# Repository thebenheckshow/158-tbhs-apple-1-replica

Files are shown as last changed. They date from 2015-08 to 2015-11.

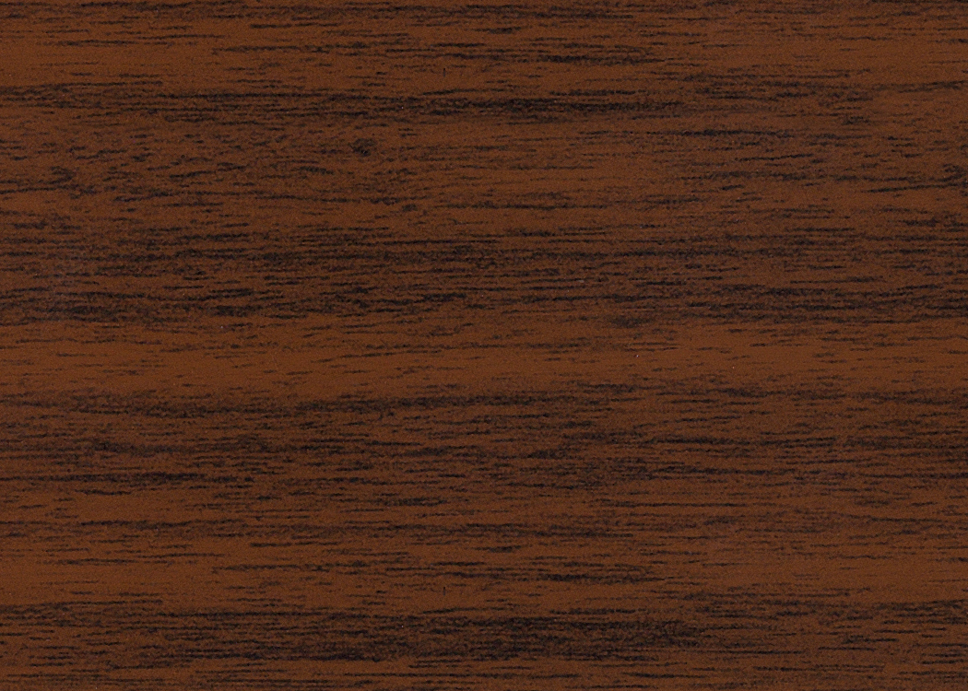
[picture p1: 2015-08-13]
enclosure design/ai/woodgrain.jpg

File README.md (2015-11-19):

Ben decides to take on another retro 8-bit computer project and builds an Apple 1 from scratch. He wires the CPU, ROM, and RAM to a PCB and adds some logic gates for memory addressing. With this basic 6502 computer complete, he uses an oscilloscope to take a look at what the CPU is doing. The digital data shows that the 6502 is functional and Ben can move on to the next step.

Ben Heck's Apple 1 Replica Part 1: http://www.element14.com/community/docs/DOC-70662/l/episode-158-ben-hecks-apple-1-replica-part-1-episode

Ben Heck's Apple 1 Replica Part 2: http://www.element14.com/community/docs/DOC-70977/l/episode-159-ben-hecks-apple-1-replica-part-2-episode

Ben Heck's Apple 1 Replica Part 3: http://www.element14.com/community/docs/DOC-71142/l/episode-160-ben-hecks-apple-1-replica-part-3-episode

Learn more about DREAMBOARD at http://element14.com/dreamboard

Join the community at: http://www.element14.com/tbhs

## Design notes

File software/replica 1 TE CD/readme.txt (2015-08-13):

This CD contains drivers, manuals and software for the replica 1TE 8 bit single board computer. See Briel Computers website for more information at:

http://www.brielcomputers.com

I hope you enjoy your replica 1 as much as I enjoyed designing it.

Vince Briel
Briel Computers

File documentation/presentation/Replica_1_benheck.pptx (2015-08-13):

## Replica apple 1 build the ben heck show

A Journey Back to an 8-bit Era

## About the ben heck show

- Weekly show on element14.com community and YouTube
- Focus on technology, problem solving and real-world assembly
- Projects designed to engage community
- 175 episodes since debut in 2010

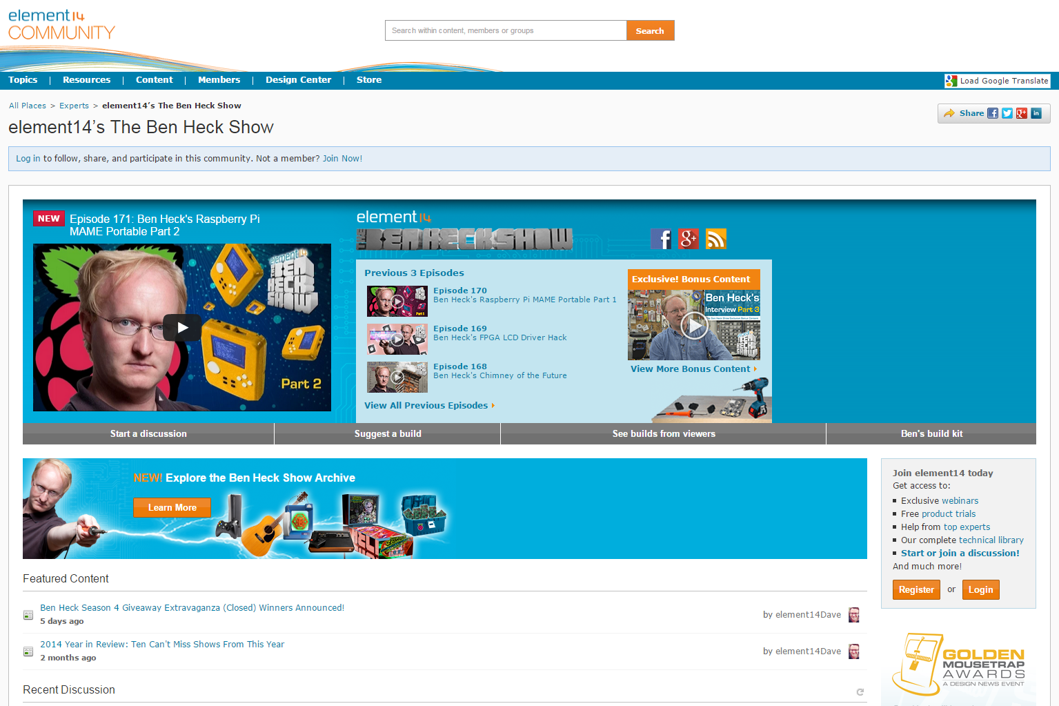
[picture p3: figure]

## Project origins

- Personal fan of classic 8-bit computers
- Recent success with classic Sinclair Spectrum
- Fun opportunity to explore the roots of modern computing

## Project overview

- Find schematics for original Apple 1
- Locate ROM images and map correctly to modern EPROM
- Find as many modern, compatible components as possible
- Hand-wire Apple 1 circuitry as a 6502 single-board module
- Hand-wire microcontroller alternative to Apple 1 video circuit
- Create custom keyboard and scan with the microcontroller
- Design project enclosure based off the size of the LCD
- CNC, laser cut and 3D print custom case, assembly and wire

## Apple 1 overview

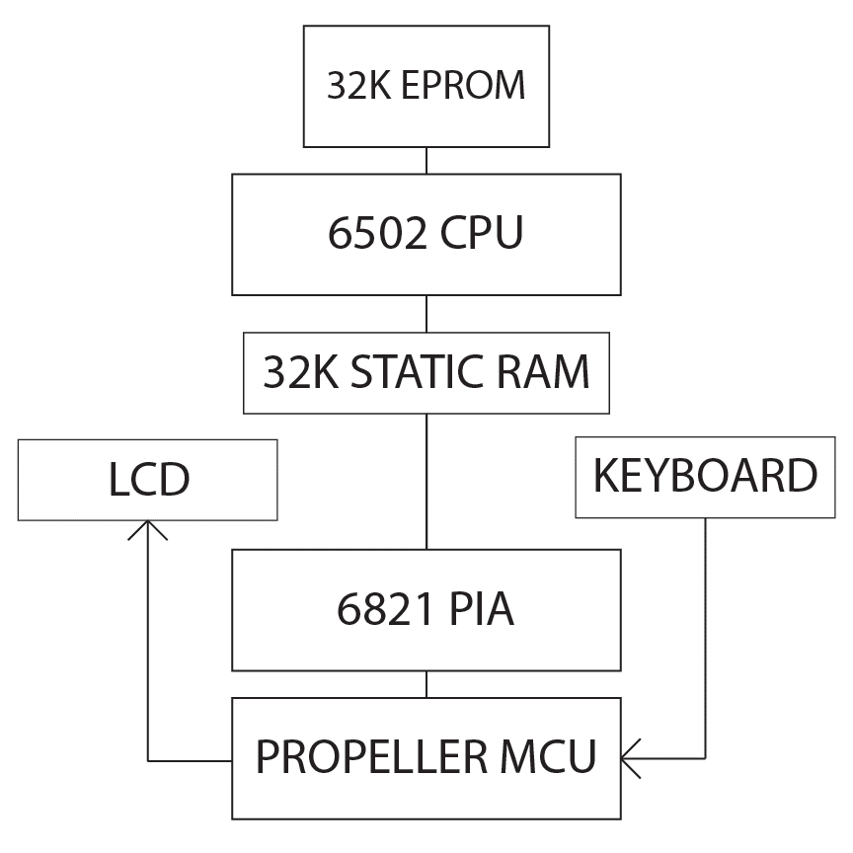
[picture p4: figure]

- Part 1: 6502 system
- Part 2: PIA and Microcontroller for I/O
- Original parts:
- 6502, PIA
- Modern parts:
- EPROM, RAM, MCU, glue logic

## Memory map

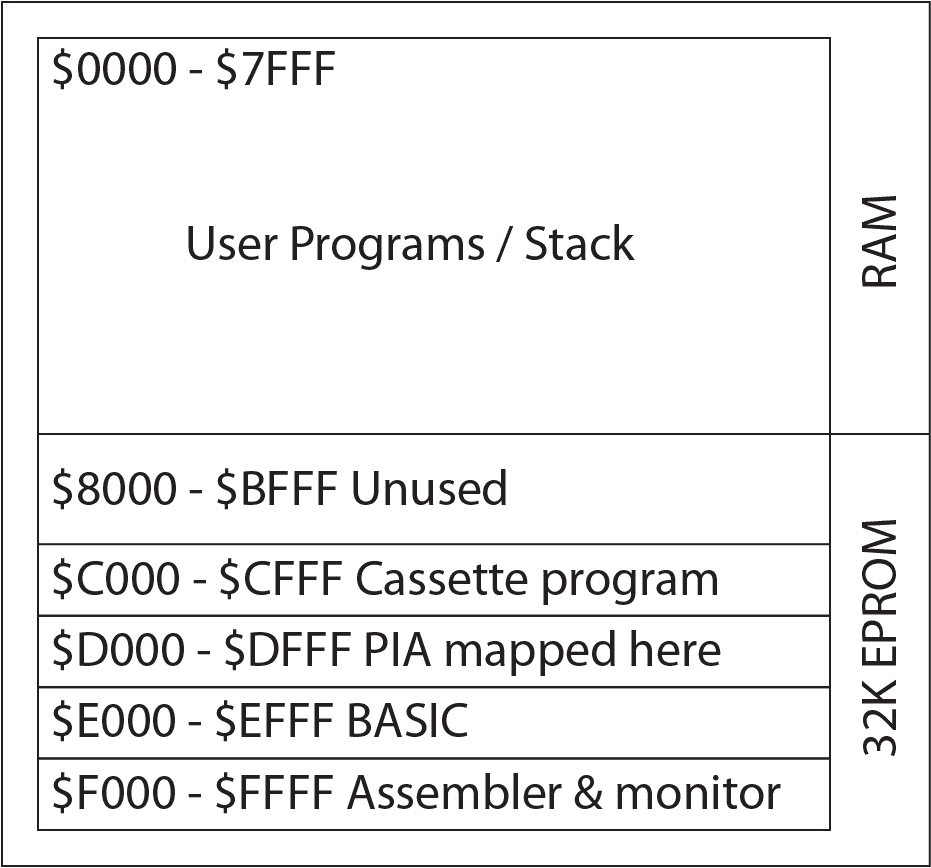
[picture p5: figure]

- Original Apple had RAM at bottom and top of memory (below WOZ monitor)
- Replicas place RAM at bottom of memory, EPROM programs at top
- Cassette, BASIC and monitor programs arranged via HEX editor and burned to EPROM
- Mapping done with a few logic circuits

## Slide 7

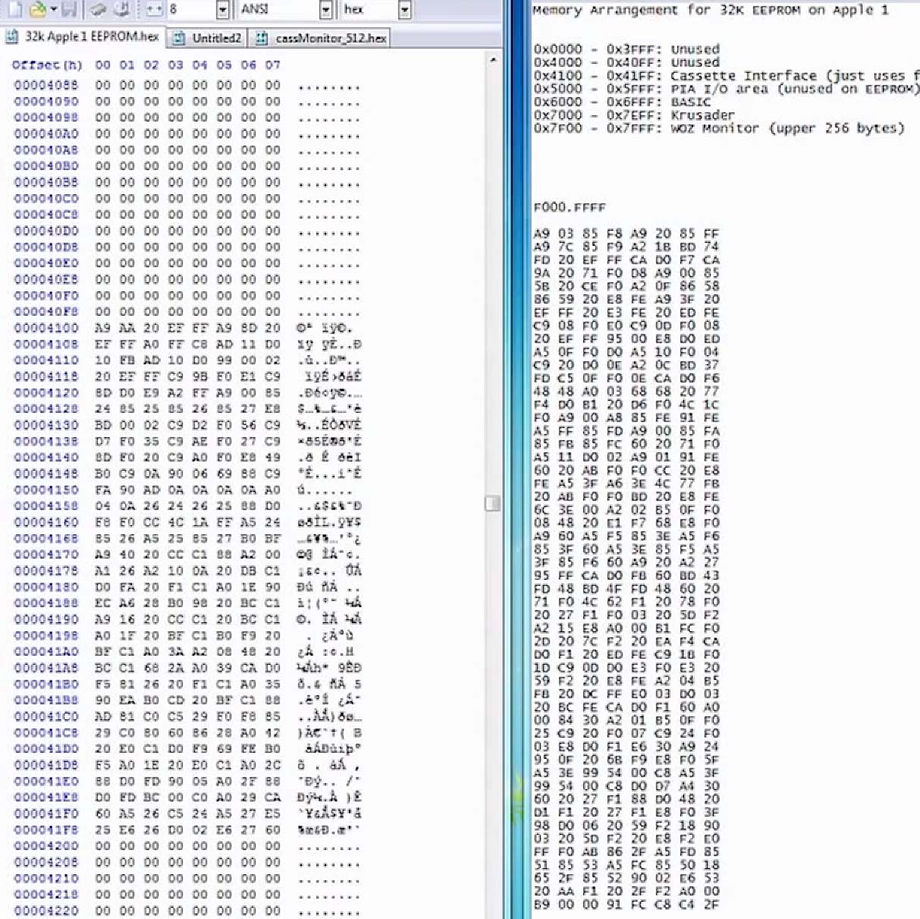
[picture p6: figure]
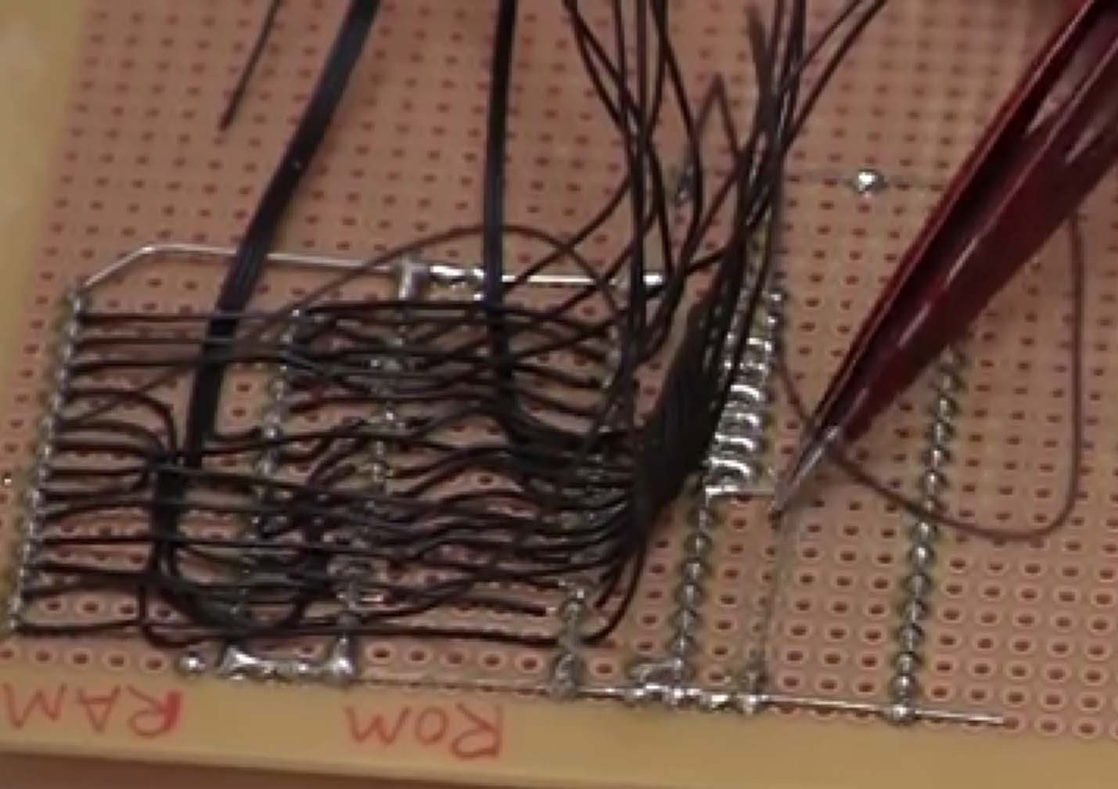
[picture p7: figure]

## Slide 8

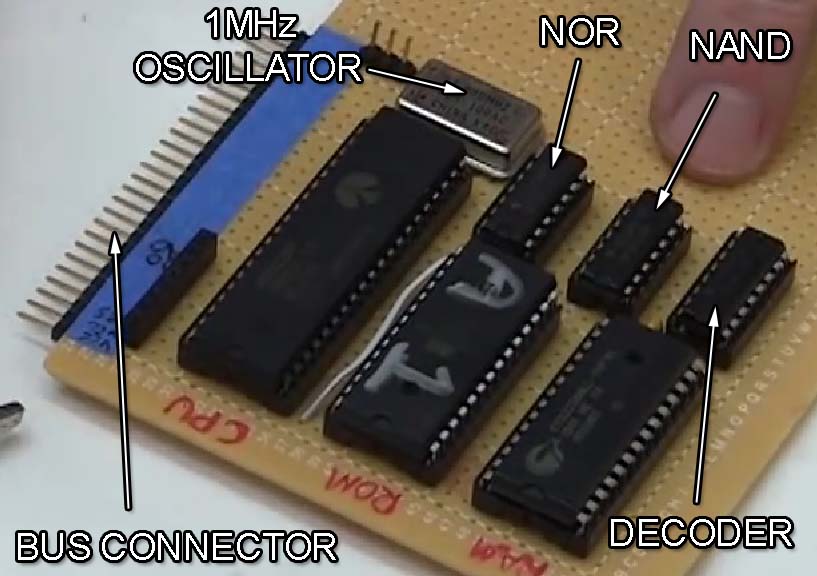
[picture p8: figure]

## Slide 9

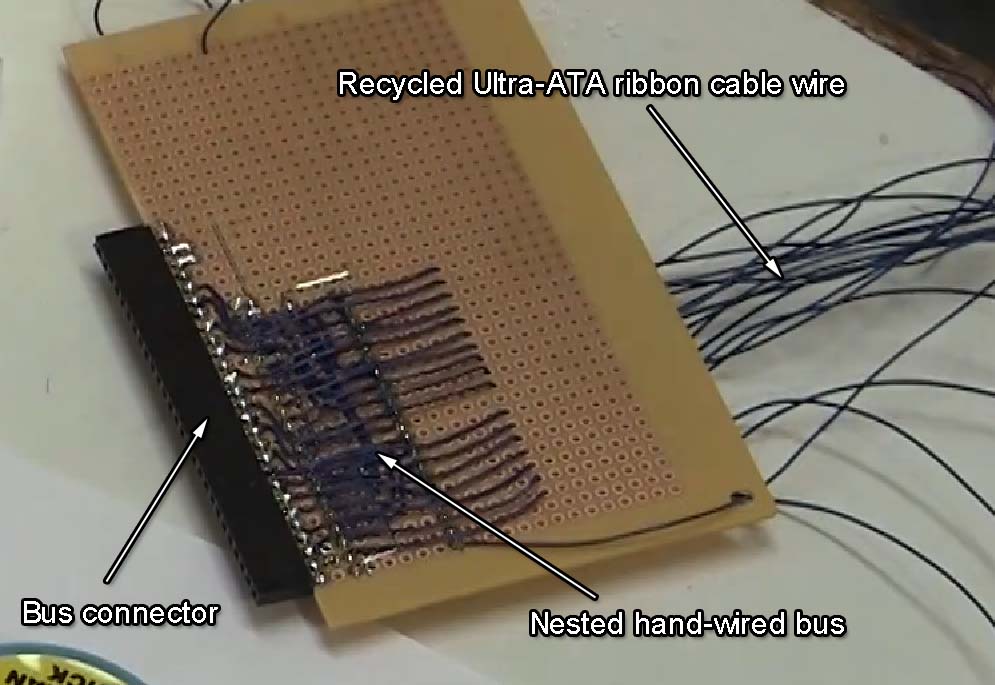
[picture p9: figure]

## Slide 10

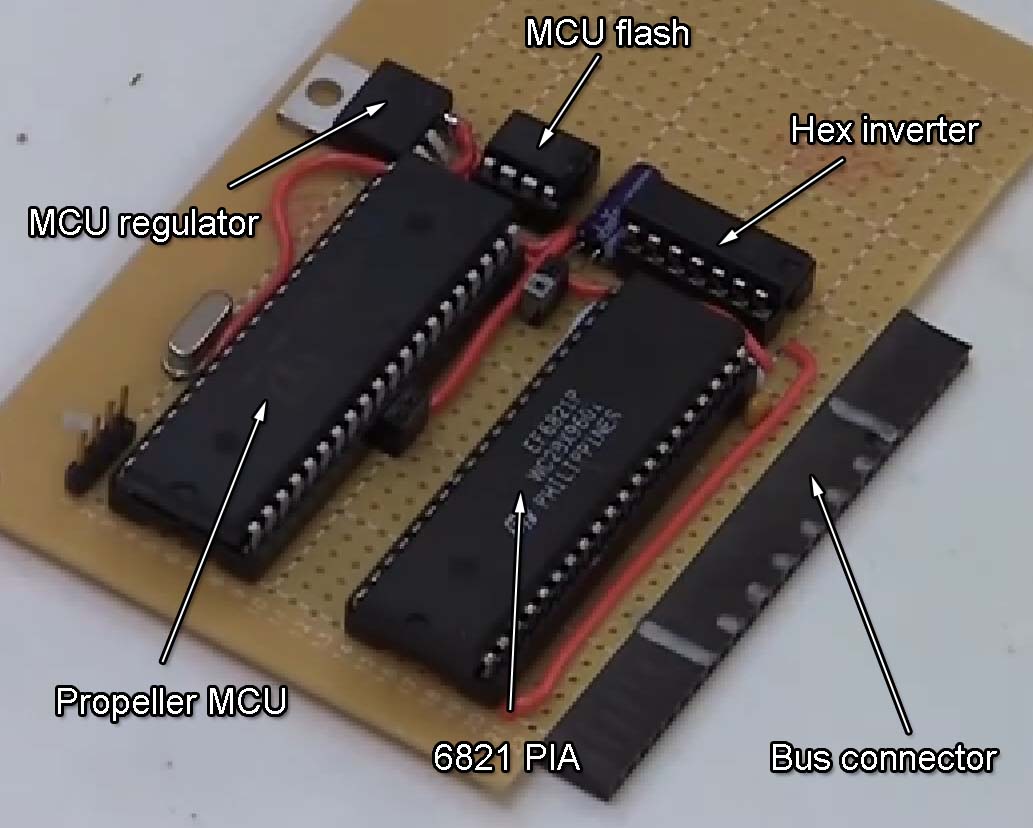
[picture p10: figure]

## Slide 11

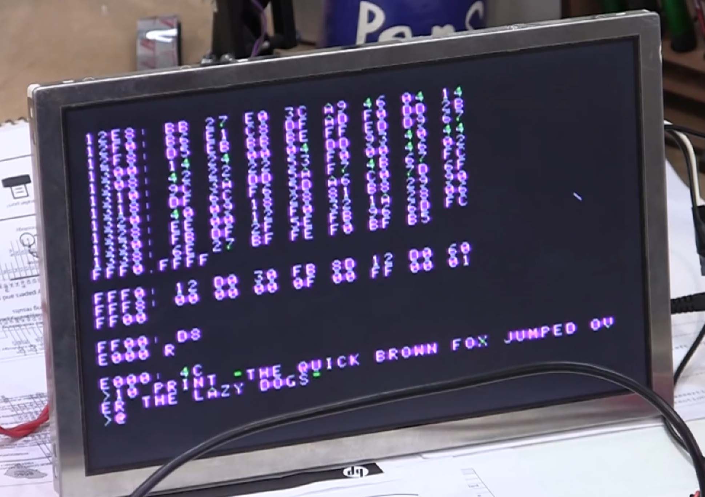
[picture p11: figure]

## Enclosure design & construction

- Bringing a Blast from the Past

## Base pcb layout

- Basic dimensions of hand-wired PCB are drawn into computer
- Only major shapes drawn for expediency

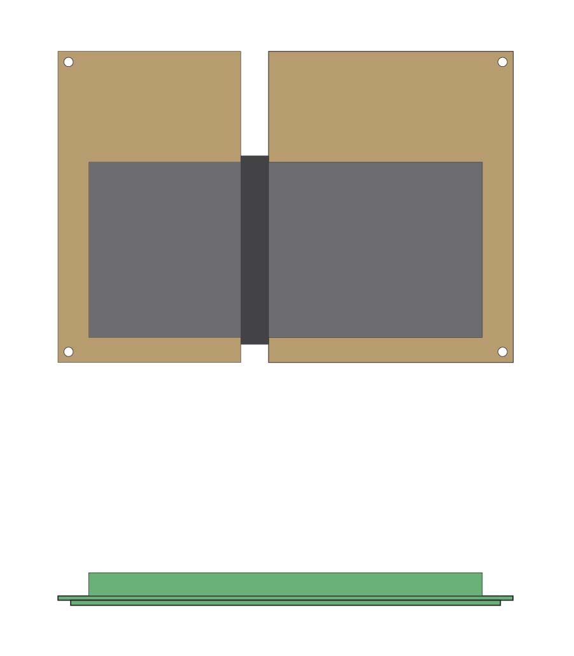
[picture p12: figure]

## LCD drives majority of layout

- Used old spare composite LCD taking up space in shop
- Size of LCD drives size & design of custom keyboard
- Extra layers and texturing added to increase detail

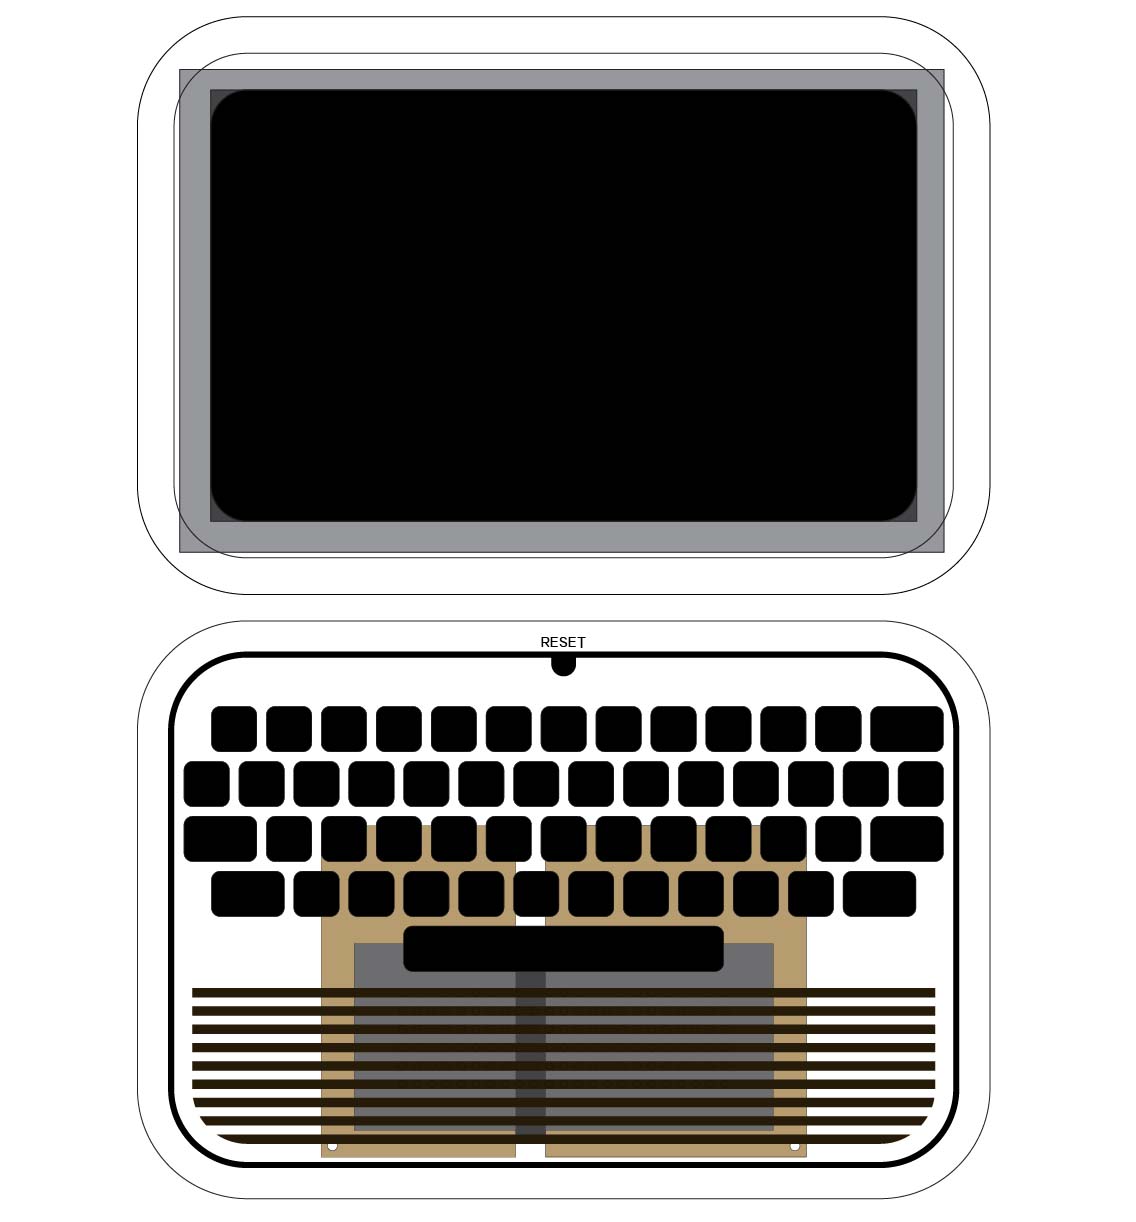
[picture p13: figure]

## Minimalist custom keyboard

- Spacing and size derived from case shape – custom allows us to make it perfectly fit our case
- 6mm tactile switches mount to laser-cut plastic template

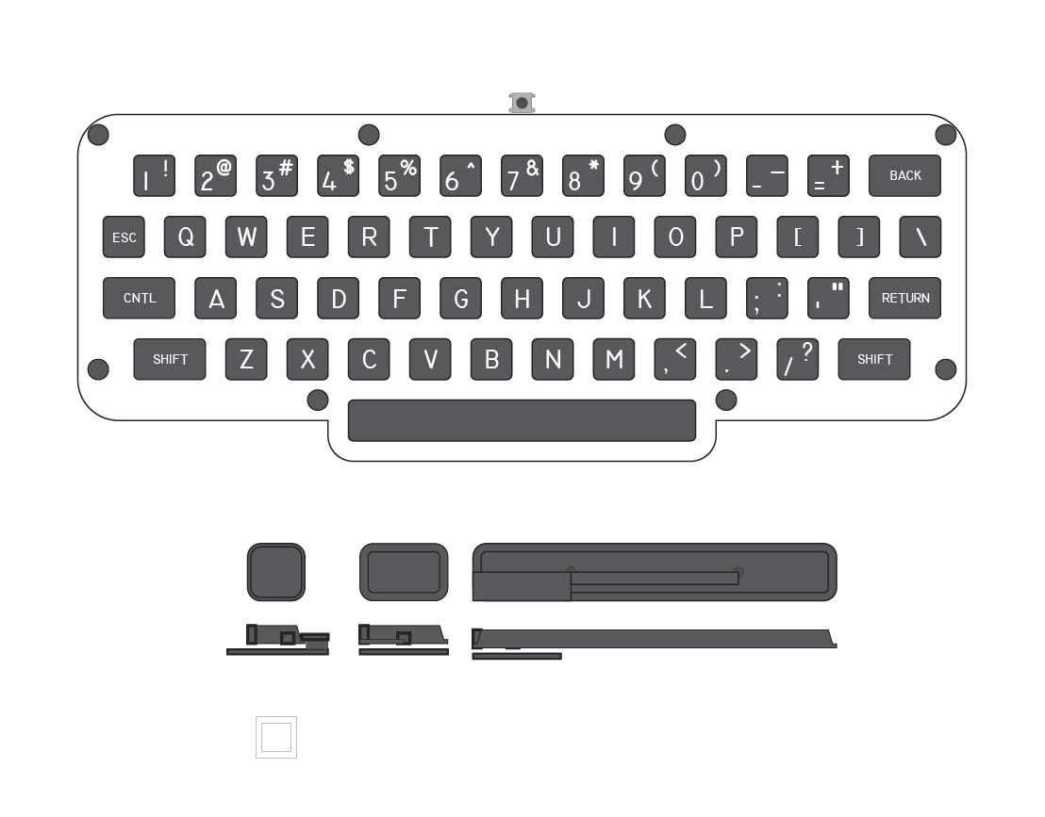
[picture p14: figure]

## Final case design

- 3D printed keys with laser-etched white glyphs
- Dark stained wood & gloss black color theme
- Meant to look like a well-made, homemade computer from a wood-grain era

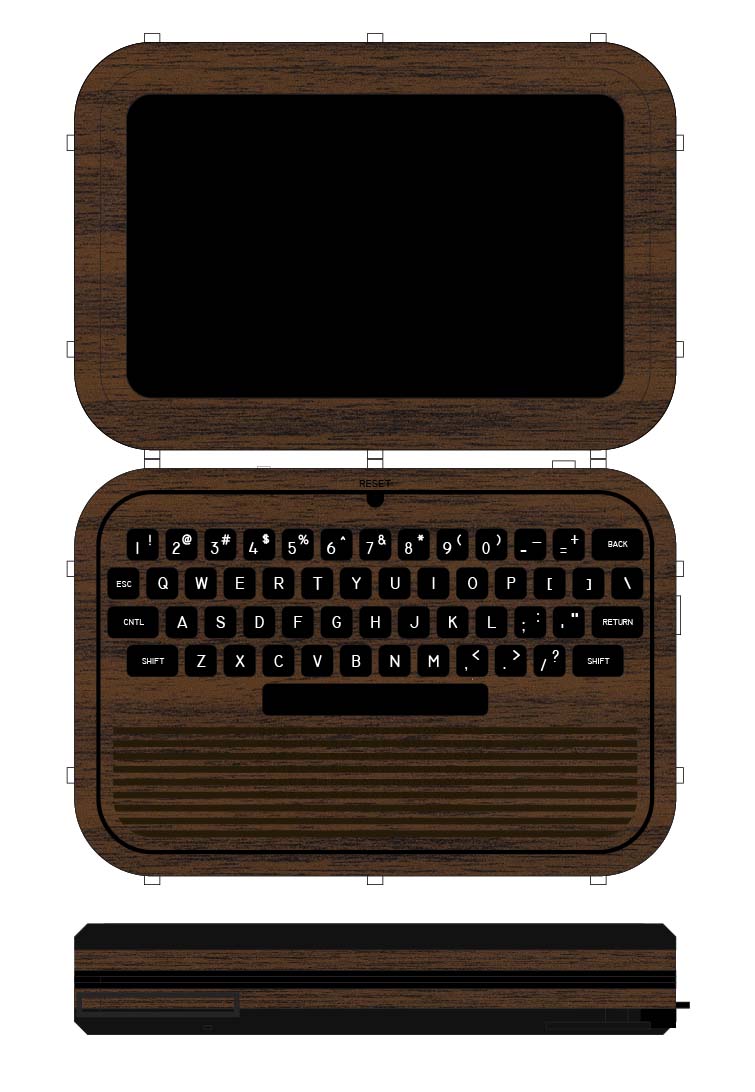
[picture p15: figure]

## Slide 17

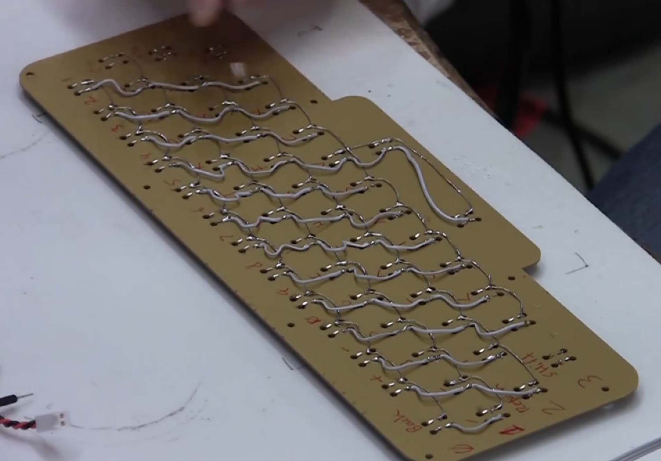
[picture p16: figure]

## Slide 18

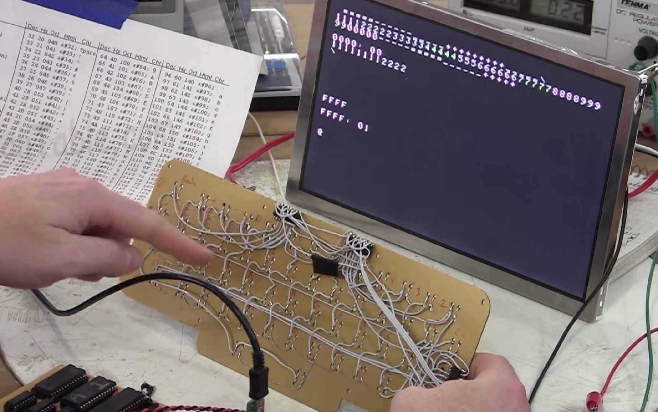
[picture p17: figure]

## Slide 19

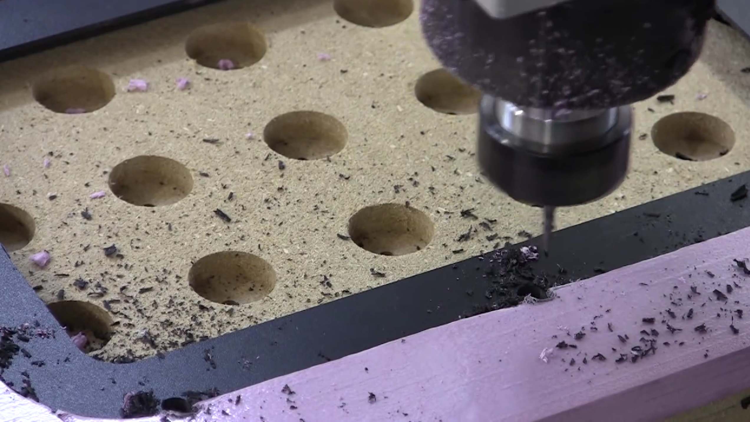
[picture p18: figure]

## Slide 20

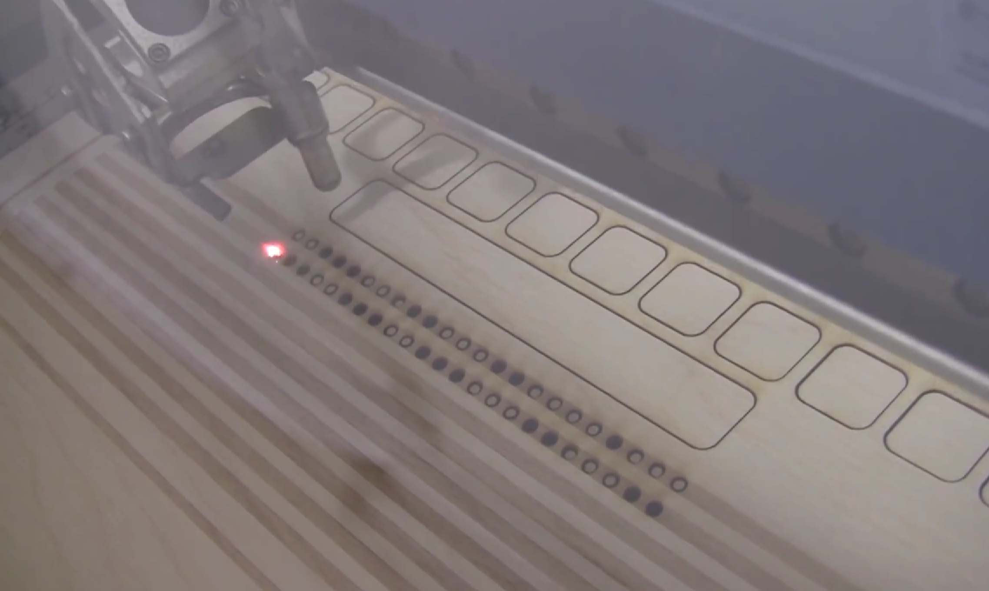
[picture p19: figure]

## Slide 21

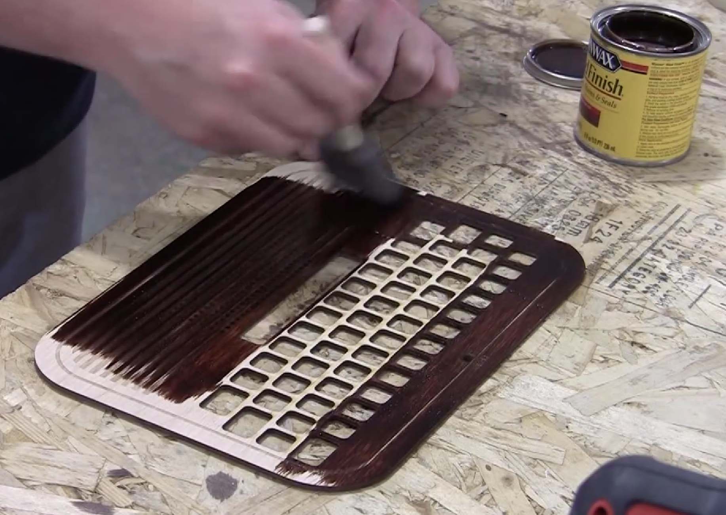
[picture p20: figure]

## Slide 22

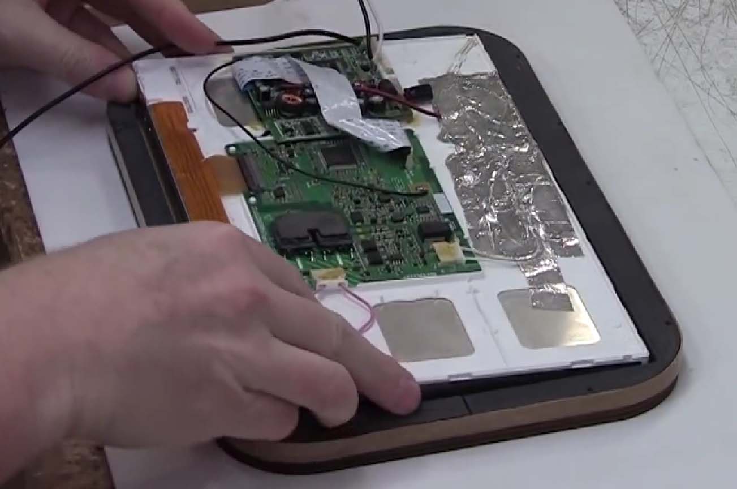
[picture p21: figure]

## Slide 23

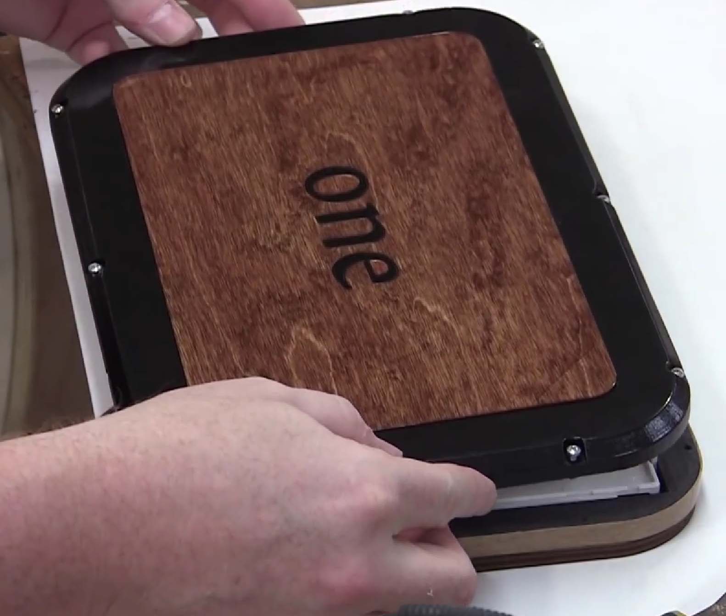
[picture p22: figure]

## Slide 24

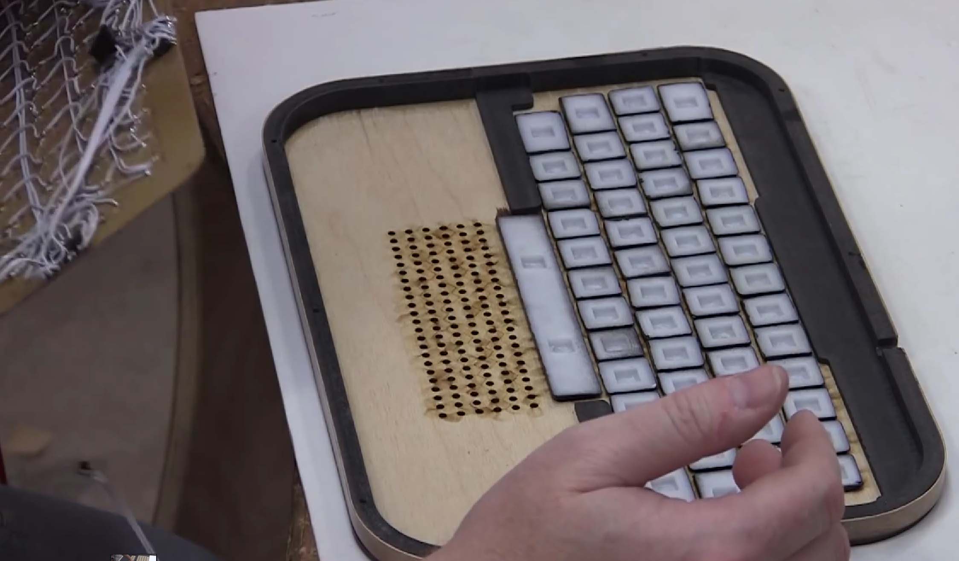
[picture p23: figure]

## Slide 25

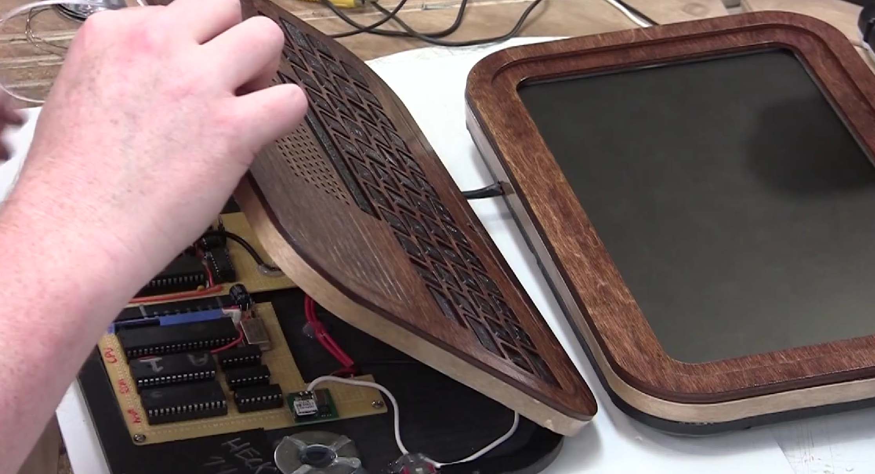
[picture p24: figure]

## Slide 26

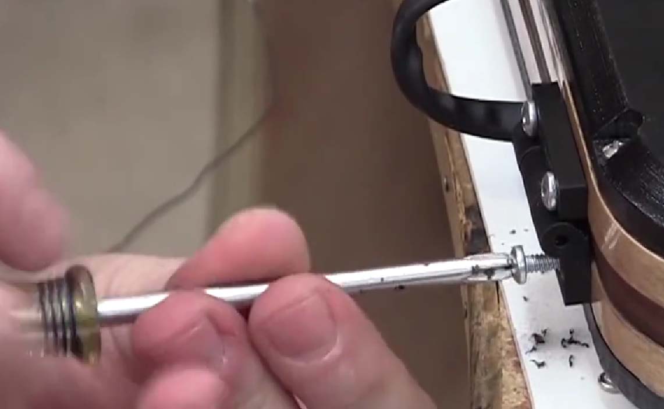
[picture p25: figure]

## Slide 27

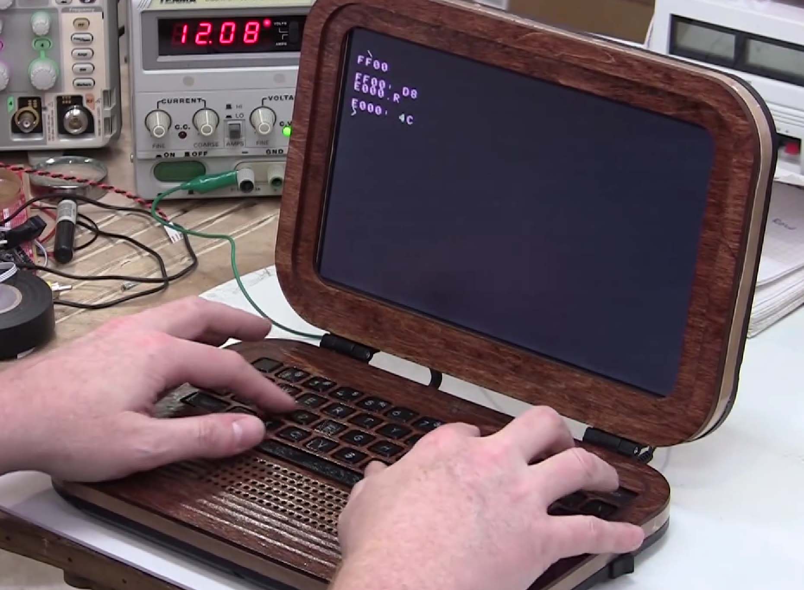
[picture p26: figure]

## Things I liked about project:

- Great wood aesthetic, fairly compact size
- Used almost all original components, fairly simple and fun electronics
- Learned a lot about where Apple came from and was very impressed by the use of technology, especially the 256 byte “Woz Monitor”
- Used up a clunky old LCD that was taking up space in my shop
- Made great use of a variety of CNC tools.
- Always fun to do woodworking

## Things I could have done better:

- Custom keyboard ate up a lot of build time, was it worth it?
- Old PS/2 keyboard would have worked better but at cost of design / size
- “Junk” LCD has poor display (even by composite standards) and consumes a lot of power, making batteries not an option
- Sometimes buying new is better than using up what you have
- Audio in / cassette port would have been nice
- 6821 PIA could probably have been emulated in MCU assembly if I had the time to write code

## Questions?

- Questions about this build, other builds, our show, etc?

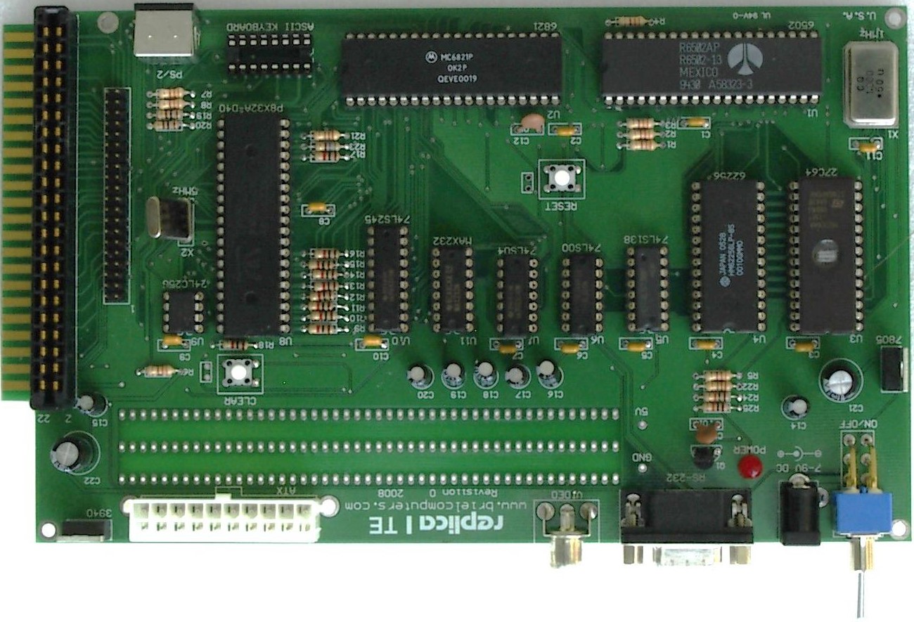
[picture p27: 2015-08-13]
software/replica 1 TE CD/Replica1TE1.jpg

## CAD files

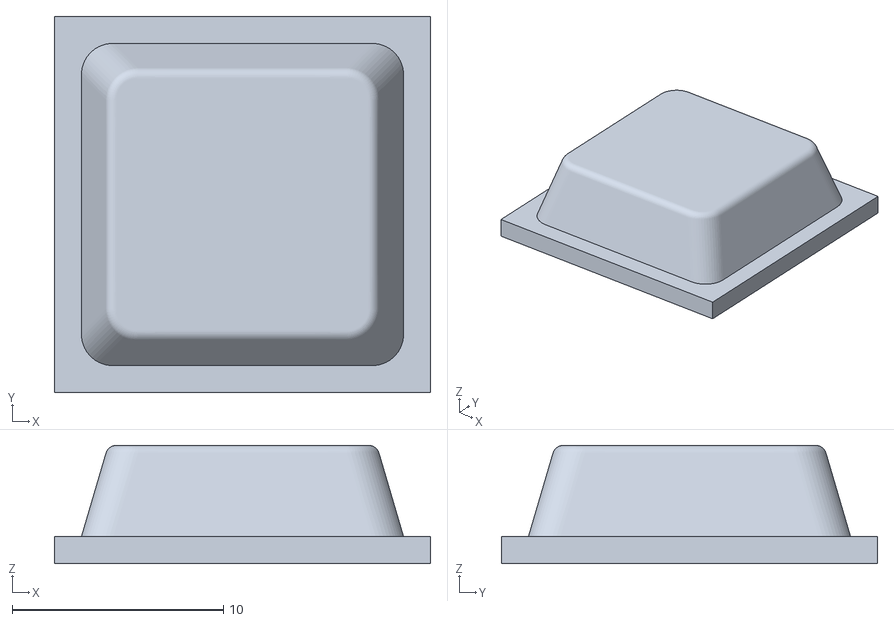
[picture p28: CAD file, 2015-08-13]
enclosure design/STL/key 2.stl
17.8 x 17.8 x 5.59

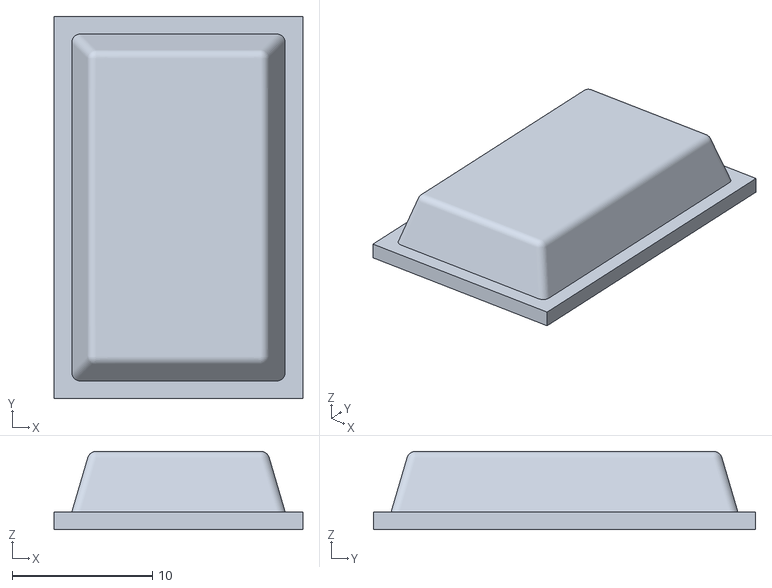
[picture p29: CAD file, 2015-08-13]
enclosure design/STL/control.stl
17.8 x 27.3 x 5.59

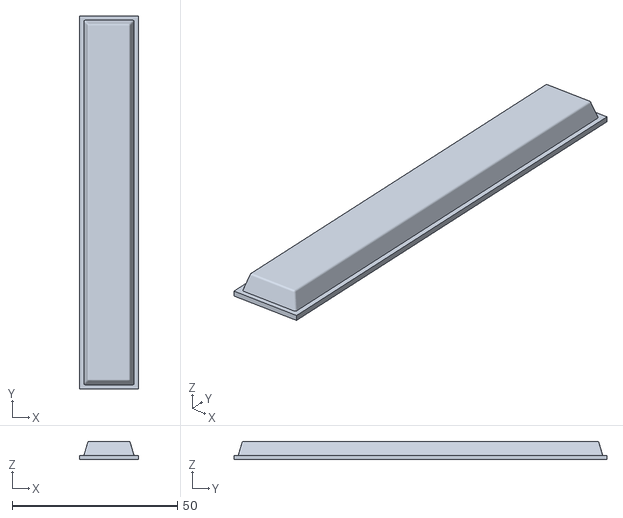
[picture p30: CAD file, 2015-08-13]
enclosure design/STL/space.stl
17.8 x 113.0 x 5.59

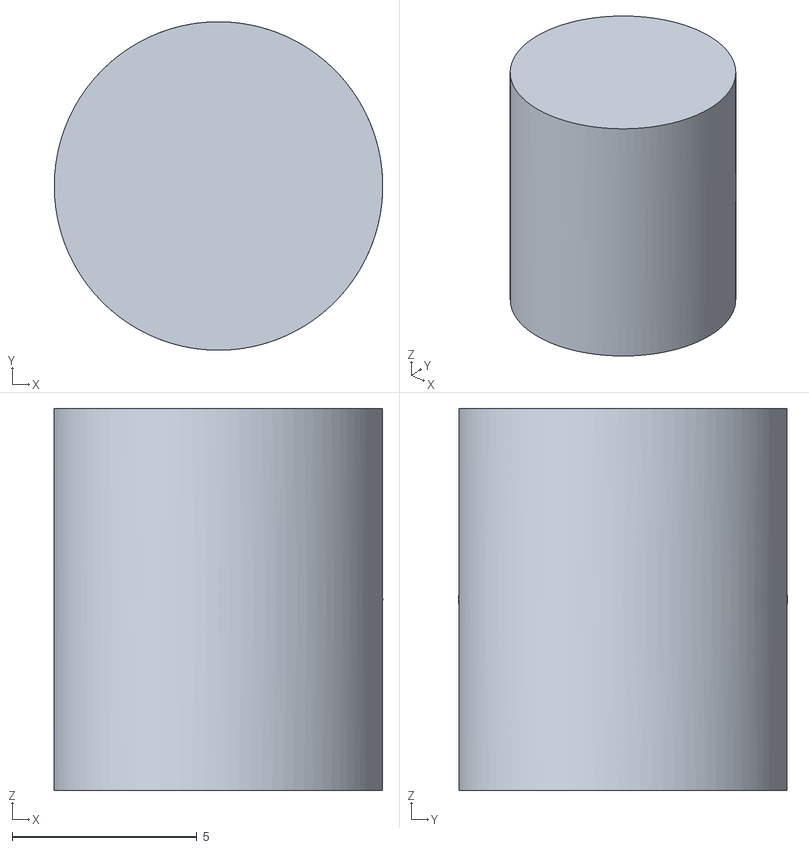
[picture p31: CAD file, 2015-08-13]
enclosure design/STL/key_pressure_1.stl
8.89 x 8.89 x 10.3

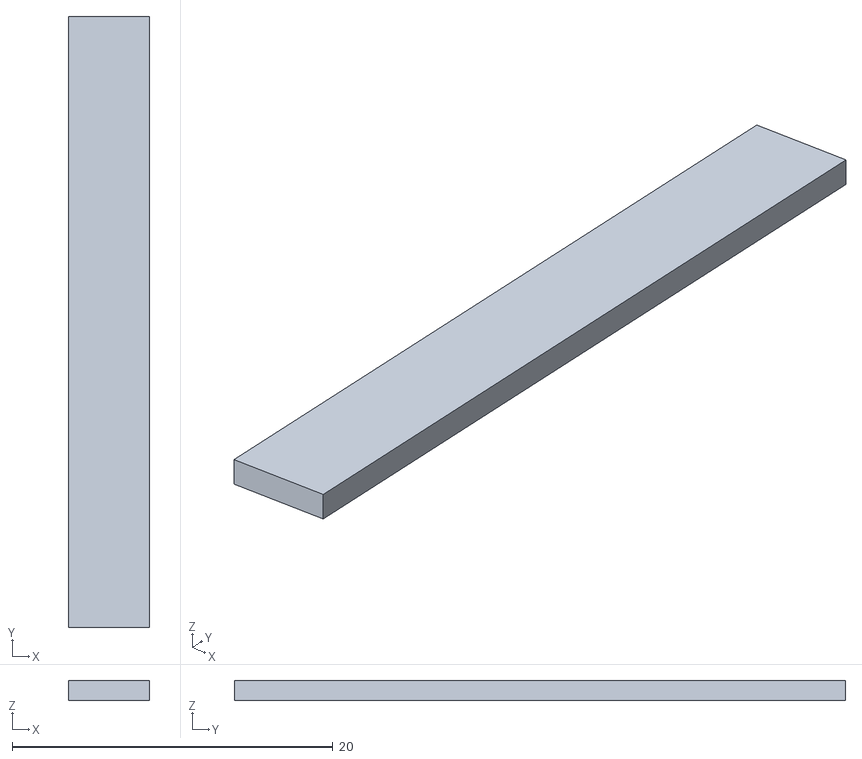
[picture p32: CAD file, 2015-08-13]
enclosure design/STL/spacer.stl
5.08 x 38.1 x 1.27

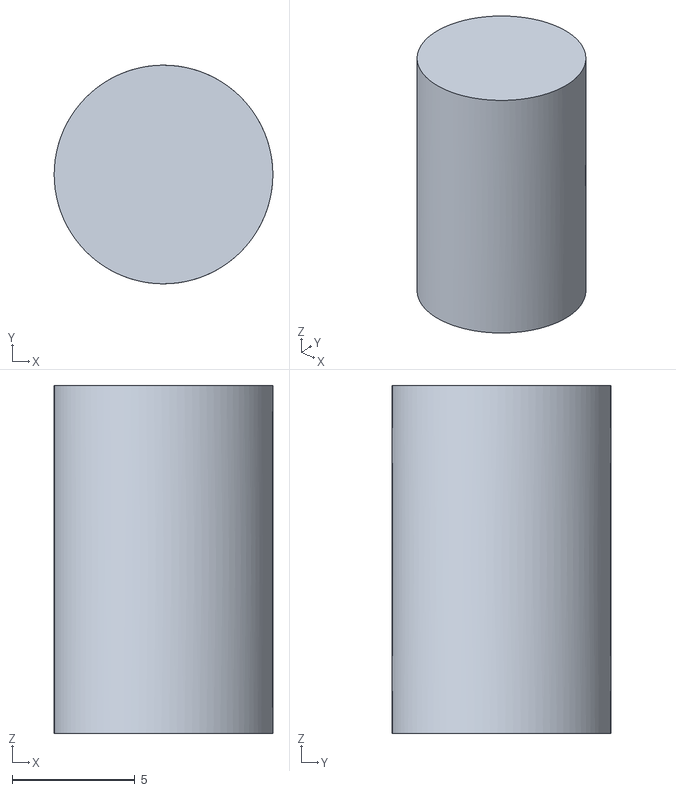
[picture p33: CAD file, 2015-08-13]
enclosure design/STL/key_pressure_2.stl
8.89 x 8.89 x 14.1

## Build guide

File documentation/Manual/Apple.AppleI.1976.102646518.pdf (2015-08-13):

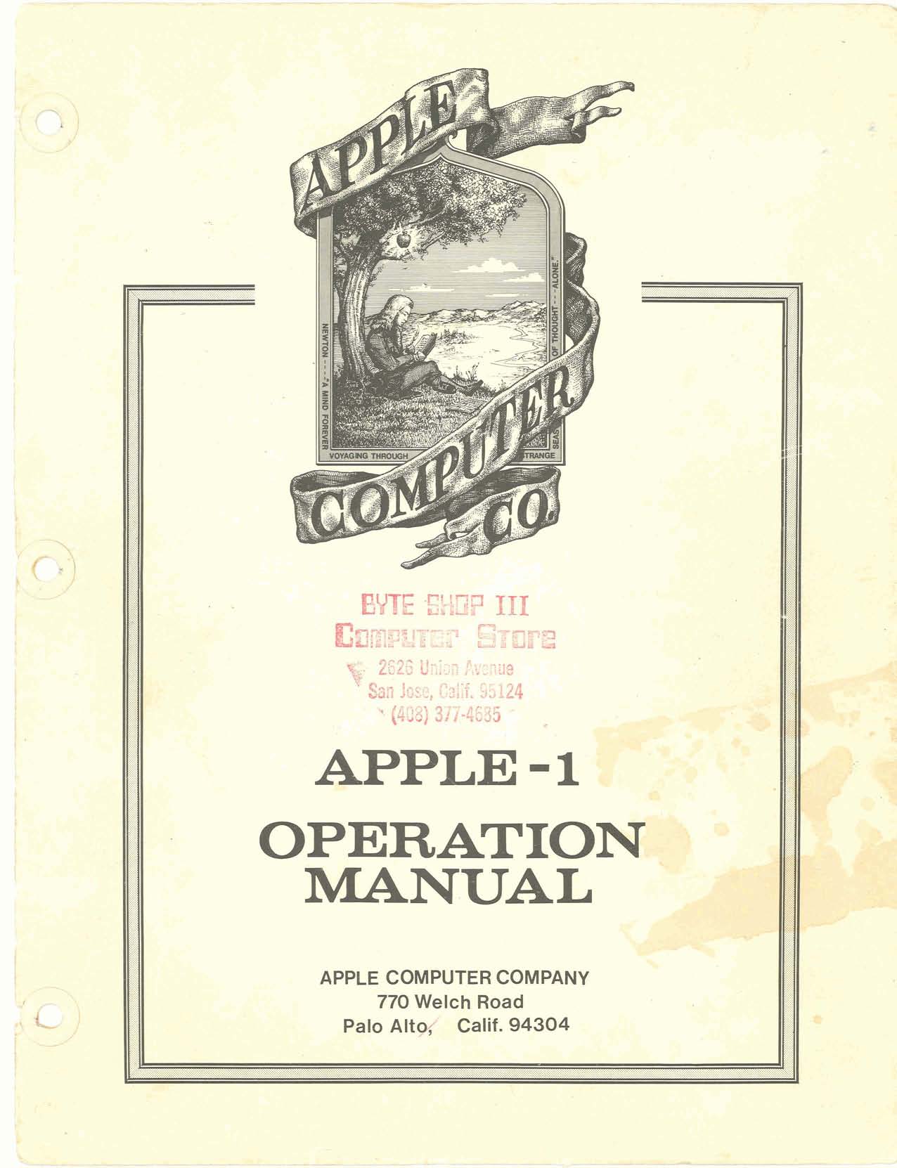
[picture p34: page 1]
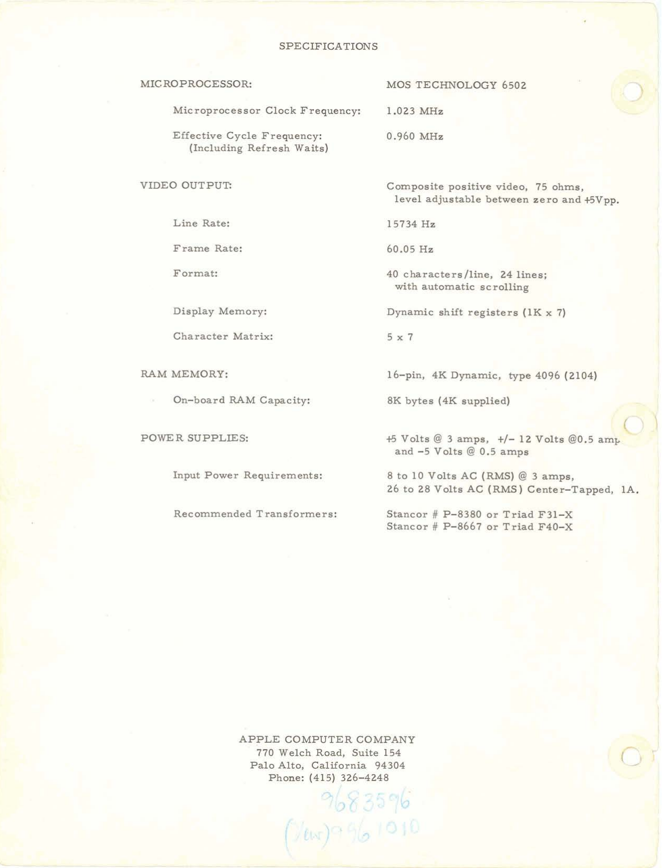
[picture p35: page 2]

SPECIFICATIONS

MICROPROCESSOR:

Microprocessor Clock Frequency:

Effective Cycle Frequency: (Including Ref re sh Waits)

VIDEO OUTPUT:

Line Rate:

Frame Rate:

Format:

Display Memory:

Character Matrix:

RAM MEMORY:

On-board RAM Capacity:

POWER SUPPLES:

Input Power Requirements:

Recommended Transformers:

MOS TECHNOLOGY 6502

1.023 MHz

0.960 MHz

Composite positive video, 75 ohms, level adjustable between zero and -15Vpp.

40 characters/line, 24 lines; with automatic scrolling

Dynamic shift registers (1K x 7)

16-pin, 4K Dynamic, type 4096 (21 04)

8K bytes (4K supplied)

+5 Volts @ 3 amps, +/- 12 Volts @0.5 amp and -5 Volts @ 0.5 amps

8 to 10 Volts AC (RMS) @ 3 amps,
26 to 28 Volts AC (RMS) Center-Tapped, 1A.

Stancor # P-8380 or Triad F31-X
Stancor # P-8667 or Triad F40-X

APPLE COMPUTER COMPANY
770 Welch Road, Suite 154
Palo Alto, California 94304 Phone: (415) 326-4248

The Apple Computer is a complete micro-'~,ocessor system, consisting of a Mos Technology 2 microprocessor and support hardware, in-Jral video display electronics, dynamic memory and refresh hardware, and fully regulated power supplies. It contains resident system monitor software, enabling the user, via the keyboard and display, to write, examine, debug, and run programs efficiently; thus being an educational tool for the learning of microprocessor programming, and an aid in the development of software.

The integral video display section and the keyboard interface renders unnecessary the need for an external teletype. The display section contains its ownmemory, leaving all of RAM for user programs, and the outputformat is 40 characters/ line, 24 lines /page, with auto scrolling. Almost any ASCII encoded keyboard will interface directly with the Apple system.

The board has sockets for upto 8K bytes of the 16 pin, 4K type, RAM, and the system is fully expandable to 65K via the edge connector. The system uses dynamic memory (4K bytes supplied), although static memory may also be used. All refreshing of dynamic memory,' including all " off -board" expansion memory, is done auto-

matically. The entire system timing, including the microprocessor clock and all video signals, originates in a single crystal oscillator.

Further, the printed circuit board contains a "breadboard area", in which the user can add additional " on -board " hardware ( for example,

extra PIAfs, ACIAfs, EROMfs, and so on).

This manual is divided into three Sections:

Section I GETTING THE SYSTEM RUNNING. Section I1 USING THE SYSTEM MONITOR. (listing included)
Section I11 EXPANDING THE SYSTEM.

Please readsection I thoroughly, before attempting to "power-up" your system, and study Section I11 carefully before attempting to expand your system. In addition to this manual, Apple "Tech Notes" are available which contain example s of expansion hardware and technique s.

*
SECTION I
GETTING THE SYSTEM RUNNING

The Apple Computer is fully assembled, tested, and burned in. The only external devices necessary for operation of the system are: An ASCII encoded keyboard, a video display monitor, and AC power sources of 8 to 10 Volts (RMS) @3 amps and 28Volts (RMS) @1amp. The following three articles describe the attachment of these devices in detail.

Keyboard:
Any ASCII encoded keyboard, with positive DATA outputs, interfaces directly with the Apple system via a "DIP" connector. If your keyboard has negative logic DATA outputs (rare), you can install inverters (7404) in the breadboard area. The strobe can be either positive or negative, of long or short duration. The "DIP" keyboard connector (B4) has inputs for seven DATA lines, one

1
87

ST ROBE line, and two normally-open pushbutton switches, used for RESET (enter monitor), and CLEAR SCREEN (see schematic diagram, sheet

### 3 of 3, for exact circuitry). This keyboard con-

nector also supplies three voltages, (+5V, +12V, and-12V) of which one or more may be necessary to operate the keyboard. Pin 15 of the keyboard connector (B4) must be tied to +5V (pin 16) for normal operation.

NOTE: The system monitor accepts only uppercase alpha (A-F, R).
It is therefore convenient, though it's not essential, tohave a keyboard equipped with uppercasealphalock (usuallyintheelectronics). Either of the following suggested circuits may be used to provide alpha lock capability, if needed, and
can be built in the breadboard area.

Vcc(+S)

Bp-wB6 13 | TO KBD
FROM l5 | 00
KBD 14 | CONNECTOR 184)

Display:
The Apple Computer outputs a composite video signal (composite of sync and video information) which can be applied to any standard raster-scan type video display monitor. The output level is adjustable with the potentiometer located near the video output Molex connector, J2. The additional two outside pins on the Molex connector supply $5 andi-12 volts, to be used in future Apple accessories. The composite video signal can also be modulated at the proper RFfrequency, with an inexpensive commercially available device , and applied to the antenna terminals of a home television receiver. Since the character format is 40 characters /line, all television receivers will have the necessary bandwidth to display the entire 40 characters. Two large manufacturers of video display monitors, which connect directly with the Apple Computer, are Motorola and Ball. The mating four-pin Molex connector is provided.

AC Power Sources:
Two incoming AC power sources are required for operation: 8 to 10 VAC (RMS) at 3 amps, and 28VAC (RMS) Center-Tapped

at 1amp. These
AC supplies enter the system at the Molex connector, Jl. The 8 to10 volts AC provides the raw AC for the +5 volt supply, while the 28 VCT supplies the raw AC for the +12 and -12 volt supplies, and the -5V supply is derived from the -1 2V reg-
ulated output. | I

The board, as supplied, requires no more than 1.5 amps DC from the t5V supply, while the regulator is capable of supplying 3 amps. The remaining 1.5 amps DC from the t5V supply is available for user hardware expansion (provided ratings are employed).

rce of the raw AC voltages , are two commercially available trans-,Stancor P/N P-8380 or equivalent (8 to at 3 amps), and Stancor PIN P-8667 or equivalent ( 28VCT at 1 amp ) . Simply wire the

secondaries to the mating six-pin Molex connector supplied, and wire the primaries in parallel, as -
shown in the schematic diagram (power supd section, Dwg. No. 00101, sheet 3 of 3.
TEST PROGRAM | &

After attaching the keyboard, display, and
AC power sources, you can try a simple program to test if your system and the attachments are functioning together properly. While it does not test many possible areas of the microprocessor system, the test program will test for the correct attachment of the keyboard, display, and power supplies.

FIRST:
Hit the RESET button to enter the system monitor. A backslash should be displayed, and the cursor should drop to the next line.
SECOND: | 4Y
Type- | 0 :A9 b 0 b AA b 20 b EF b FF b
E8 b 8A b 4C b'2 bib-(RE~)
(0 is a zero, NOT an alpha "0"; b means blank or space; and (RET) hit the "return" key on the keyboard)

THIRD:
Type- 0 . A (RET)

(This should print out, on the display, program you have just entered. )

FOURTH:
Type- R (RET)
(R means run the program. )

THE PROGRAM SHOULD THEN PRINT OUT ON THE DISPLAY A CONTINUOUS STREAM OF ASCII CHARACTERS. TO STOP THE PRO-GRAM AND RETURN TO THE SYSTEM MONITOR, HIT THE "RESET" BUTTON. TO RUN AGAIN, TYPE : R (RET).

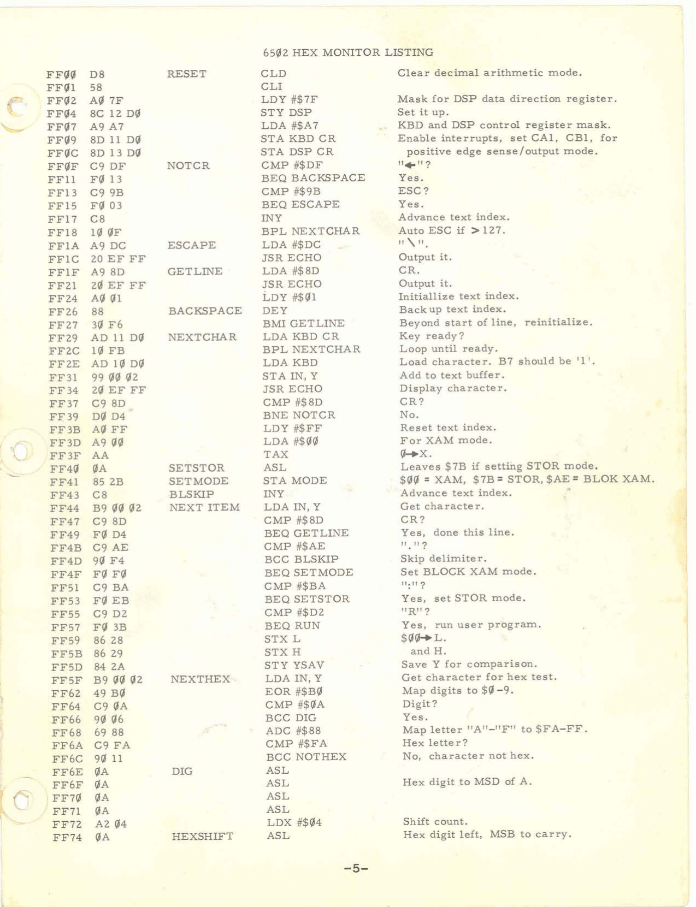
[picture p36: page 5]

ifhmetic mode.

| | LDY #$7F | | Mask for DSP data direction register.
| | STY DSP | | Set it up.
| | LDA #$A7 | | KBD and DSP control register mask.
FF09 8D 11 D0 | | STA KBD CR | | Enable interrupts, set CAI, CB1, for
FFgC 8D 13 D0 | | STA DSP CR | | positive edge sense/output mode.
FF0F C9 DF | NOTCR | CMP #$DF | | 11 ?
FFll F0 13 | BEQ BACKSPACE | Yes.
FF13 C9 9B | | CMP #$9B | | ESC ?
FF15 F0 03 | | BEQ ESCAPE | | Yes.
FF17 C8 | | INY | | Advance text index.
FF18 10 0F | BPL NEXTCHAR | Auto ESC if >127.
FFlA A9 DC | ESCAPE | LDA #$DC | * | 11 \It,
FFlC 20 EF FF | | JSR ECHO | | Output it.
FFlF A9 8D | GETLINE | LDA #$8D | | CR.
FF21 241 EF FF | | JSR ECHO | | Output it.
FF24 A0 01 | | LDY #$a1 | | Initiallize text index.
FF26 88 FF27 30 F6 | BACKSPACE | DEY
BMI GETLINE
| | | | Back up text index.
| | | | Beyond start of line, reinitialize.
FFZ~AD 11 DQ | NEXTCHAR | LDA KBD CR | Key ready?
FFZC 10 FB
FFZE AD 10D0

BPL NEXTCHAR

| | LDA KBD | | Loop until ready. Load character. B7 should be '1 I.
FF31 99 00 02 | | STA IN, Y | | Add to text buffer.
FF34 20 EF FF | | JSR ECHO | | Display character.
FF37 C9 8DI | | CMP #$8D | | CR?
FF39 D0 D4 | | BNE NOTCR | | No.
FF3B A0 FF | | LDY #$FF | | Reset text index.
FF3D A9 00 | | LDA #$a0 | | For XAM mode.
FF3F AA | | TAX
FF40 4A | SETSTOR | ASL
FF41 85 2B | SETMODE | STA MODE
FF43 C8 | BLSKIP | INY | - | 'Advance text index.
I
i
FF44 B9 09 02 FF47 C9 8D | NEXT ITEM | LDA IN, Y
| | CMP #$8D | | Get character.
| | | | CR?
FF49 F0 D4 | BEQ GETLINE
FF4B C9 AE | | CMP #$AE
FF4D 90 F4 | BCC BLSKIP | Skip delimiter.
FF4F Fg F0 | BEQ SETMODE
FF51 C9 BA
FF53 F0 EB
FF55 C9 D2 | | CMP #$D2 | | Yes, set STOR mode. "R"?
l | FF57 F0 3B
FF59 86 28 | | BEQ RUN
| | STX L | | Yes, run user prbgram
! | FF5B 86 29 | STX H
FF5D 84 2A | | STY YSAV
FF5F B9 (40 02 | NEXTHEX-. | LDA IN, Y
FF62 49 B0 | | EOR #$I30 | | Map digits to $@-9.
FF64 C9 0A | | CMP #$@A
FF66 90 06 | | BCC DIG
FF68 69 88 | | ADC #$88
FF~A C9 FA | | C.MP #$FA | | Hex letter?
BCC NOTHEX | . | No, character not hzx.
| | | | Hex digit .to MSD of
| | | | Shift count.

Fd 97

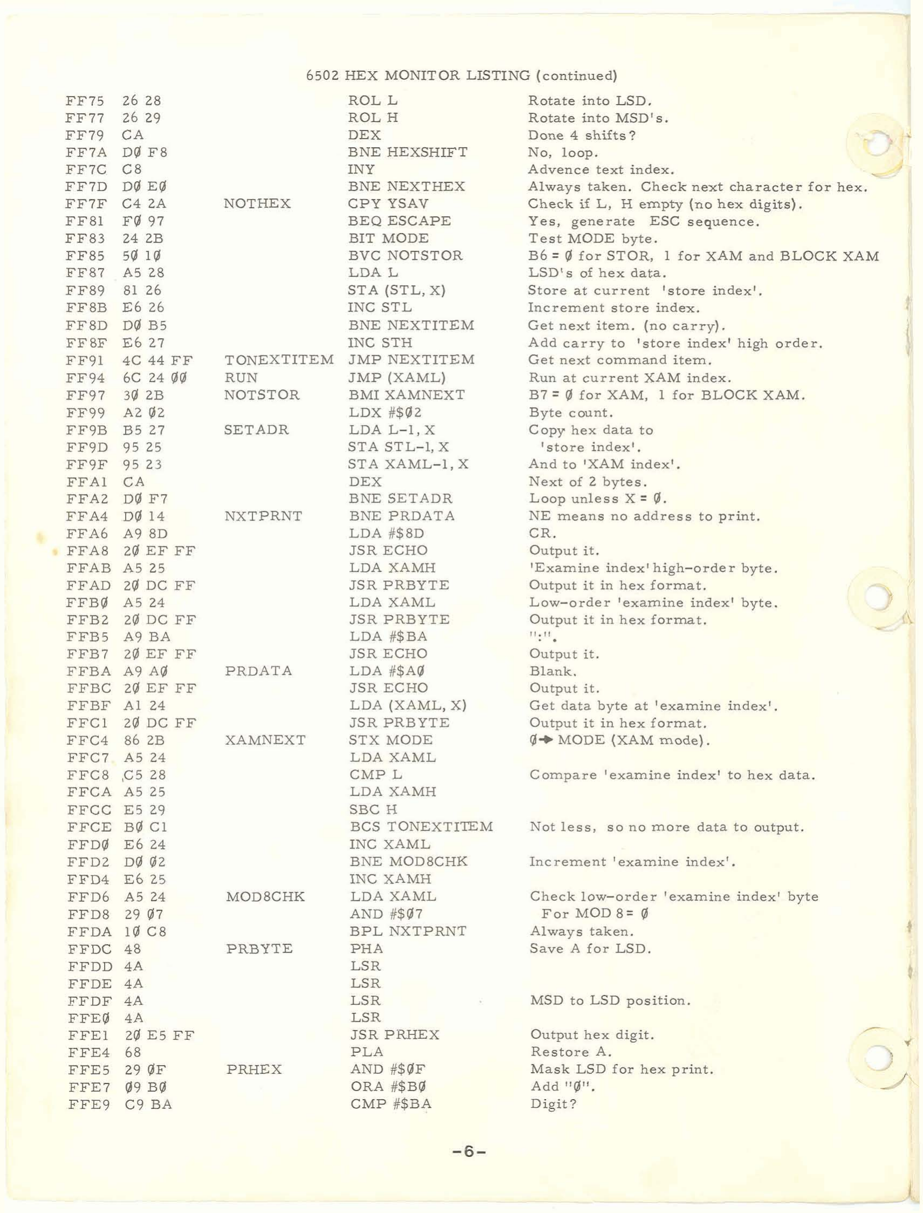
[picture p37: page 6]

i

6502 HEX MONITOR LISTING (continued) FF75
FF77
FF79
FF7A
FF7C
FF7D
FF7F
FF81
FF83
FF85
FF87
FF89
FF8B
FF8D
FF8F
FF91
FF94
FF97
FF99
FF9B
FF9D
FF9F
FFAl

26 28
26 29
CA
Db F8
C8
DQ EQ
C4 2A

24 2B
50 10
A5 28
81 26
E6 26
DQ B5
E6 27
4C 44 FF
6C 24 00
30 2B
A2 02
B5 27
95 25
95 23
CA
| ROL L | Rotate into LSD.
| ROL H | Rotate into MSD's.
| DEX | Done 4 shXts?
| BNE HEXSHIFT | No, loop.
| INY | Advence text index.
| BNE NEXTHEX | Always taken. Check next character for he,
| CPY YSAV | Check ifL, H empty (no hex digits).
| BEQ ESCAPE | Yes, generate ESC sequence.
| BIT MODE | Test MODE byte.
| BVC NOTSTOR | B6 = 0 for STOR, 1 for XAM and BLOCK XAM
| LDA L | LSD's of hex data.
| STA (STL, X) | Store at current 'store index'.
| INC STL | Increment store index.
| BNE NEXTITEM | Get next item. (no carry).
| INC STH | Add carry to 'store index' high order.
TONEXTITEM JMP NEXTITEM | Get next command item.
RUN | JMP (XAML) | Run at current XAM index.
NOTSTOR | BMI XAMNEXT | B7 = 0 for XAM, 1 for BLOCK XAM.
| LDX #$02 | Byte count.
SETADR | LDA L-1 ,X | Copy hex data to
| STA STL-1, X | 'store index'.
| STA XAML-1, X | And to 'XAM index'.
| DEX
| BNE SETADR | Next of 2 bytes.
| | Loop unless X = 0.
NXTPRNT | BNE PRDATA | NE means no address to print.
| LDA #$8D | CR.
| JSR ECHO | Output it.
| LDA XAMH | 'Examine index'high-order byte.
| JSR PRBYTE | Output it in hex format.
| LDA XAML | Low-order 'examine index' byte.
| JSR PRBYTE | Output it in hex format.
| LDA #$BA | ,I:,#
| JSR ECHO | Output it.
PRDATA | LDA #$A0 | Blank.
| JSR ECHO | Output it.
| LDA (XAML, X) | Get data byte at 'examine index'.
| JSR PRBYTE | Output it in hex format.
XAMNEXT | STX MODE | 0-C MODE (XAM mode).
| LDA XAML
| CMP L | Compare 'examine index' to hex data.
| LDA XAMH
| SBC H
| BCS TONEXTITEM | Not less, so no more data to output.
| INC XAML
| BNE MOD8CHK | Increment 'examine index'.
| INC XAMH
MODBCHK | LDA XAML
| AND #$07 | Check low-order 'examine index' byte
| | For MOD 8' 0
| BPL NXTPRNT | Always taken.
PRBYTE | PHA | Save A for LSD.
| LSR
| LSR
| LSR | MSD to LSD position.
| LSR
| JSR PRHEX | Output hex digit.
| PL A | Restore A.
PRHE X | AND #$@F | Mask LSD for hex print.
| ORA #$BQ | Add "0".
| CMP #$BA | Digit?

d~~A2 D0 F7
L%IX;

FFAB
FFAD
FFBQ
FFB2
FFB5
FFB7
FFBA
FFBC
FFBF
FFCl
FFC4
FFC7
FFC8
FFCA
FFCC
FFCE

$fi,

A5 25
20 DC FF
A5 24
20 DC FF
A9 BA
20 EF FF
A9 A0
20 EF FF
A1 24
20 DC FF
86 2B
A5 24
,C5 28
A5 25
E5 29
B0 Cl
FFDQ E6 24
FFD2
FFD4
FFD6
FED8
FFDA
FFDC
FFDD
FFDE
FFDF
FFE0
FFEl
FFE4
FFE5
FFE7
FFE9

D0 02
E6 25
A5 24
29 07
10 C8
48
4A
4A
4A
4A
20E5FF
68
29 0F
09 B0
C9 BA

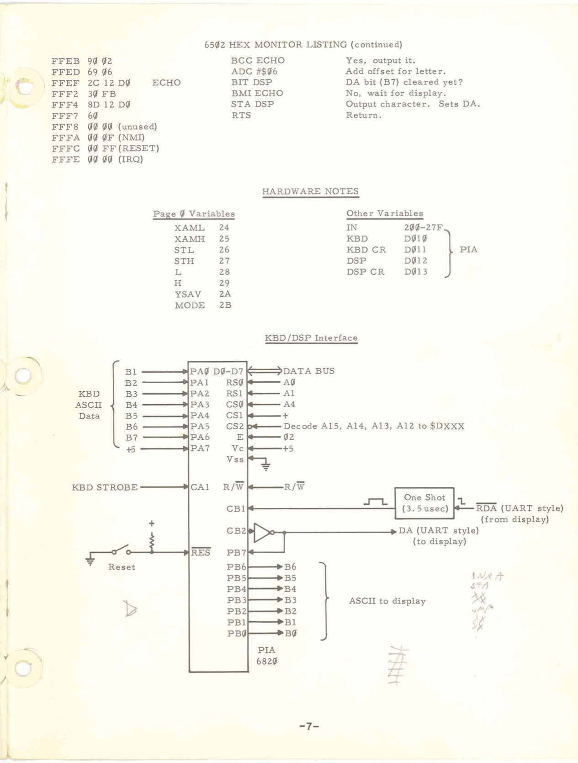
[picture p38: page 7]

Page 0 Variables
XAML | 24
XAMH | 25
STL | 26
STH | 27
L | 28
H | 29
YSAV | 2A
MODE | 2B

HARDWARE NOTES

Other Variables
IN | 200-27F
KBD
KBDCR Doll
DSP
DSP CR DQ13

SECTION I11
HOW TO EXPAND THE APPLE SYSTEM

The Apple system can be expanded to include more memory and I0 devices, via a 44-pin edge connector. The system is fully expandable to 65K, with the entire data and address busses, clocks, control signals ( i. e. IRQ, NMI, DMA, RDY, etc.), and power sources available at the connector. All address lines are TTL buffered, and data lines can drive ten equivalent capacitive loads (one TTL load and 130pf) without external buffers. All clock signals are TTL. The Apple system runs at approximately 1 MHz ( see spec sheet) and is fully compatible with 6800/6500 style timing.

Three power sources are available at the edge connector: f5 volts regulated, and raw DC (approximately +/- 14V) for the +12'V, -12V, and -5V supplies. If +12V, -12V, or -5V supplies are required, EXTERNAL REGULATORS MUST BE USED. An excess of 1.5 amps from the "onboardu regulated f5V supply is available for expansion (assuming suitable transformer ratings are employed). Exercise great care in the handling of the raw DC, as no short-circuit protection is provided.

REFRESH:
Four out of every 65 clock cycles is dedicated to memory refresh. At the start of a re-
- fresh cycle (150 ns after leading edge of 01), RF

goes low, and remains low for one clock cycle. $42 is inhibited during a refresh cycle, and the processor is held in 01 (it's inactive state). Dynamic memories, which must clock during refresh cycles, should derive their clock from 00, which is equivalent to 02, except that it continues during a refresh cycle. Devices, such as PIA1s, will not be affected by a refresh cycle, since they react to 02 only. Refer to Apple "TechNotesl' for a variety of inte riacing examples .

DMA:
The Apple system has full DMA capabli
For DMA, the DMA control line tri- states ,
address buss, thus allowing external devices t, | '
control the buss. | Consult MOS TECHNOLOGY
6502 Hardware Manual for details. (For DMA use, the solder jumper on the board, marked "DMA", must be broken. )

For the 6502 microprocessor, the RDY line is used to halt the processor for single stepping, or slow ROM applications. Refer to Apple "Tech Notes" for examples.

SOFTWARE CONSIDERATIONS:
The sequences listedbelow are the routines used to read the keyboard or output to the display,

Read Key from KBD:
LDA KBD CR (D011)

LDA KBD DATA (DQlo)

Output to Display:
BIT DSP (D012)

STA DSP (Do12)

PIA Internal Registers:
KBD Data | I3010
High order bit equals 1.

KBD Control Reg. Doll
High order bit indicates "key ready". Reading key clears flag. Rising edge of KBD sets flag.
DSP DATA | D012
Lower seven bits are data output, high order bit is display ready" input (1 equals ready, 0 equals busy)

DSP Control Reg. D013

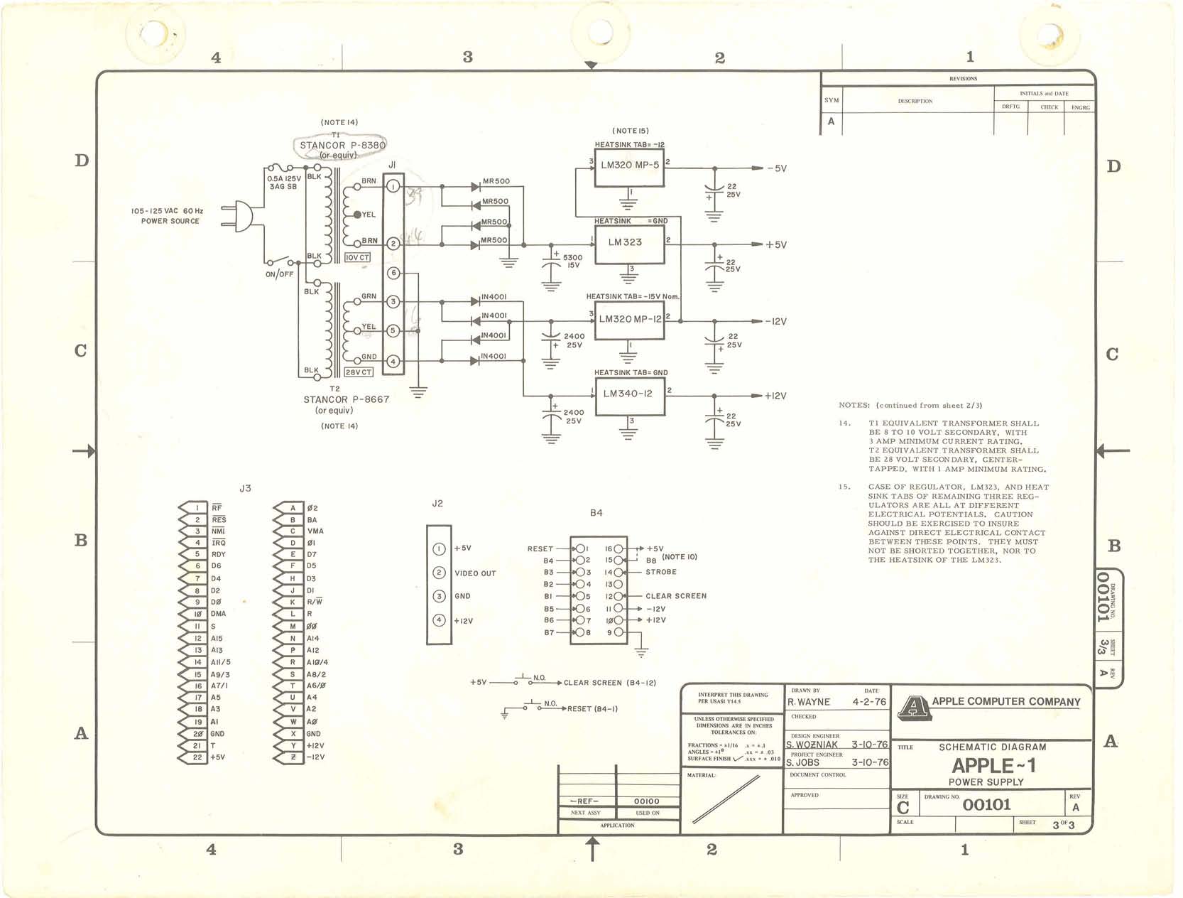
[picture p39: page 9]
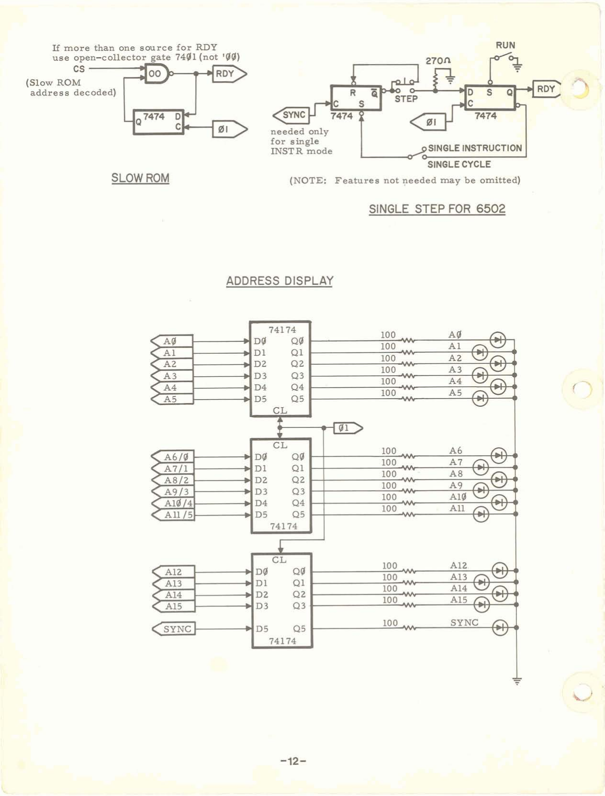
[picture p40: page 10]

If more than one source for RDY | RUN
use owen-collector gate 7401 (not '00)
CS
(SlowROM
address decoded) I | I | , ' | 1 STEP | -1,I | Y

needed only
for single

INSTR mode I poSINGLE lNSTRUCTlON I

SINGLE CYCLE
SLOW ROM | (NOTE: Features not needed may be omitted)

## SINGLE STEP FOR 6502

## ADDRESS DISPLAY

D0
Dl
D2
D3
100 ,.. | SYNC SYNC | D5 | Q5

The Apple Computer Company hereby warrants each of its products, and all components therein contained, to be free from defects in materials and/or workmanship for a period of thirty (30) days from date of purchase. In the event of the occurrence of malfunction, or other indication of failure attributable directly to faulty workmanship and/or mate rial, then, upon return of the product to the Apple Computer Company, at 770 Welch Road, Palo Alto, California, 94304 (postage prepaid), the Apple Computer Company will, at its option, repair or replace said products or components the reof, to what sve r extent Apple Computer Company shall deem necessary, to restore said product to proper operating condition. All such repairs or replacements shall be rendered by the Apple Computer Company, without charge to the customer.

The responsibility for the failure of any Apple Computer product, or component thereof, which, at the discretion of the Apple Computer Company, shall have resulted either directly or indirectly from accident, abuse, or misapplication of the product, shall be assumed by the customer, andthe Apple Computer Company shall assume no liability as a consequence of such events under the terms of this warranty.

While every effort, on the part of Apple Computer Company, is made to provide clear and accurate technical instruction on the use, implementation, and application of its products, the Apple Computer Company shall assume no liability in events which may arise from the application of such technical instruction, nor shall the Apple Computer Company be held liable for the quality, interconnection, or application of periferal products, which may have been recommended by Apple Computer Company, but which havenotbeensuppliedaspart oftheproduct.

This warranty contains and embodies the limits of responsibility of the Apple Computer Company, with regard to its products, and no other liability is expressed, implied, or should be assumed by the purchaser, and in no event shall the Apple Computer Company be held liable for the loss of time, effort, or transportation costs, nor for loss of potential profits or other consequentiallosses whichmight arise from the purchase, assembly, use, application, or subsequent sale of the products of Apple Computer Company, nor from any instructions and/or technical information thereto related.

4

f

d

k

C

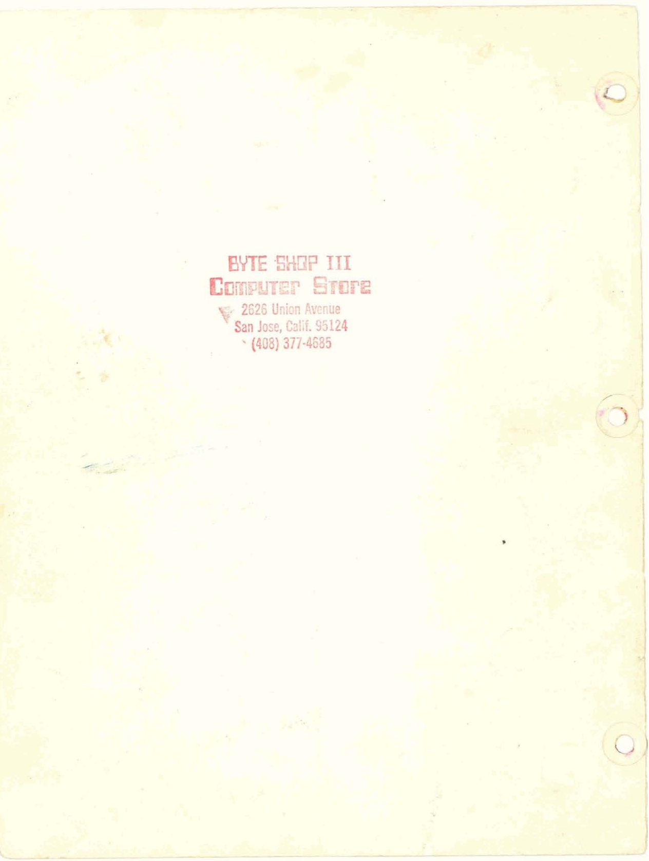
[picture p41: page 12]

# em 'anp 1\11

# v $621 Union A%en+Qe $gsj Mf;351124

@@4i137746g$

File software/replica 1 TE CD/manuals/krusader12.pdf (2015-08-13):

# User Manual for

# KRUSADER

Ken’s Rather Useless Symbolic Assembly Development Environment for the Replica 1 or is that Reasonably Useful? You decide!

### Ken Wessen

ken.wessen@gmail.com

### Version 1.2 – August 30, 2006

## 1 Introduction

KRUSADER is a program written to allow assembly language development on the Replica 1 – an Apple 1 clone designed by Vince Briel¹
, and described in the book Apple 1 Replica Creation: Back to the Garage by Tom Owad²
. KRUSADER includes a simple shell and editor, a single-pass symbolic assembler, a disassembler, and a simple interactive debugger, and fits in just under 4K (so it is small enough to fit in the 8K of Replica 1 ROM along with the monitor and Apple BASIC). Although designed for the Replica 1/Apple 1, there is very little system dependent code, and since full source code is provided, KRUSADER can easily be adapted to any other 6502 based system. However, it’s limitations may mean it is not an appropriate tool in many cases (for example, it has no concept of a file-system and so would not be particularly suitable for use on an Apple II). KRUSADER handles a fairly standard and expressive syntax for its assembly source code. For users who are unfamiliar with the 6502 instruction set, I recommend the introduction by Andrew John Jacobs at http://www.obelisk.demon.co.uk/6502/. On a Replica 1, KRUSADER can assemble over 200 lines of code per second, and given its 32K of RAM, the defaults provide space for around 20K of tokenised source code, 7K of generated code, and up to 256 global symbols. The KRUSADER distribution is comprised of two source files, one that can assemble and disassemble 6502 code only, and the another that is able to handle the expanded 65C02 instruction set (see section 6). Both versions include a mini-monitor for interactive debugging (see section 7). In addition, two binaries of each version are supplied – one to be loaded in high RAM at addresses $7100-$7FFF, and the other that belongs in ROM from $F000-$FEFF. Since source is provided, alternative binaries are easy to produce. I use the 6502 simulator by Michal Kowalski³
to assemble

1http://www.brielcomputers.com
2http://www.applefritter.com/replica
3http://home.pacbell.net/michal k/ (http://home.pacbell.net/michal_k/)

the object code, and test it on the Pom1 simulator⁴ and my Replica 1. Although the latest version of KRUSADER supports the 65C02, it contains only 6502 code itself, and this manual will cover the 6502 features first, saving a discussion of the 65C02 enhancements until section 6. Addresses quoted in this manual will be for the high RAM version of the code, with the ROM version values following in brackets, but these values are easily offset for any particular starting address.

## 2 Sample Session

The best way to give a quick overview of the system and its operation is to work through a couple of simple examples. First thing is to load the program, and once loaded run it by typing 7100R(F000R). At this point you will be presented with a brief message showing the version of the assembler you are running, followed by the shell prompt ? . Type N to enter a new program, and enter the code shown below. The column layout is important, with the source organised in fields. After the current line number is printed by the editor, the next 6 characters are the label field, then after a space there is the 3 character mnemonic field, then after a space a 14 character arguments field, and finally a comments field of maximum 10 characters. Hitting tab or space will automatically progress you to the next field, and to finish entering code, hit the escape key (hit return first though, or you will lose the current line). If you make an error typing a line, hitting backspace will return you to the start of the line (there is no true backspace on the Apple 1, and I have chosen not to implement the underscore-as-backspace hack used in the Apple 1 monitor and Apple 1 BASIC since it confuses the syntactically important column layout). If you only notice an error after hitting return and need to change a line, type E nnn, where nnn is the line number in question (it is not necessary to enter any leading zeroes). If you missed a line out altogether, type I nnn to insert at line nnn.

? N
000 | LDA #’A’
001 LOOP | JSR $FFEF
002 | CLC
003 | ADC #$1
004 | CMP #’Z’+1
005 | BNE LOOP
006 | RTS
007<esc>

When you have finished entering the source, type L to list the code, and then A to assemble it. You should see the assembler output 0300-030C, indicating the target memory locations used by the assembled code. Any errors detected in the code will be displayed at this point, and can be fixed using either the I and E commands described above, or the X nnn mmm command for deleting a range of lines (the second argument mmm is optional). Once the code has been successfully assembled, run it by typing R $300. The program will run and output the string

4The original is at http://www.chez.com/apple1/Apple1project/, and a version that fixes various bugs at http://school.anhb.uwa.edu.au/personalpages/kwessen/apple1. This version also adds the capability to emulate a 65C02-based Replica 1.

ABCDEFGHIJKLMNOPQRSTUVWXYZ

and then return to the shell (because of the final RTS).
In order to illustrate some more advanced features of the assembler, a second, more complicated example is the following.
000 ECHO | .= | $FFEF
001 START | .= | ’A’
002 END | .= | ’Z’
003 STEP | .= | $30
004
005 SETUP | .M | $280
006 | LDA #$1
007 | STA STEP
008 | LDA #START
009 | RTS
00A
00B FWD | .M | $300
00C .LOOP | JSR ECHO
00D | CLC
00E | ADC STEP
00F | CMP #END
010 | BMI .LOOP
011 | RTS
012
013 BACK | .M | $320
014 .LOOP | JSR ECHO
015 | SEC
016 | SBC STEP
017 | CMP #START
018 | BPL .LOOP
019 | RTS
01A
01B MAIN | .M | $340
01C | JSR SETUP
01D | JSR FWD
01E | JSR BACK
01F | RTS
020<esc>

Again, type L to list the code. Since this program is longer than 24 lines (i.e. one Apple 1 screen), the listing will pause after 22 lines and wait for a keypress. Hitting return will move the listing forward by one line, escape will cancel the listing, and any other key will list the next 22 lines. Typing A will assemble the code – this time made up of 4 modules, each with their own starting address. The assembler will output the following upon successful assembly:

? A
0300-02FF
SETUP | 005 0280-0286
FWD | 00B 0300-030A
BACK | 013 0320-032A
MAIN | 01B 0340-0349
?

This output shows the first source line number and the memory locations used by each module in the source code (the first line can be ignored because no code is generated prior to the declaration of the SETUP module). Hitting M will show the memory taken up by the source code, in this case 2000-20E5(2300-23E5), and the value of global symbols can be queried by using the V command – e.g. typing V MAIN will get the response 0340. This is important, because it is the entry point for this program, and running it by typing either R $340 or R MAIN will result in the output:

ABCDEFGHIJKLMNOPQRSTUVWXYZYXWVUTSRQPONML
KJIHGFEDCBA

Some other relevant features of this second example are the use of blank lines for layout, and symbols to represent both constants (e.g. START .= ’A’) and memory locations (e.g. STEP .= $30). Also note the use of the local label .LOOP in both the FWD and BACK modules. Local labels are indicated by an initial ‘.’, and have module level scope only. The .= and .M commands are two directives recognised by the assembler for defining symbols and modules respectively. It is not necessary to give a memory location argument to the .M directive, and indeed only in very special circumstances would you wish to do so.

## 3 Shell Commands

The previous section introduced most of the available shell commands, in the context of a sample interactive session. Shell commands are entered in response to the ? prompt, and are all single key commands, with between zero and two arguments. If the shell cannot process an entered command, ERR: SYN is output to indicate a syntax error. Five of the twelve shell commands are for source editing, and the others are for assembling, running, disassembling, querying symbols and source memory, entering the monitor, and recovery. Table 1 gives a summary of all commands and their syntax.

## 4 Source Code

As described in section 2, source code in KRUSADER requires strict adherence to a specific column-based format. The editor both assists and enforces source code entry to match this format by auto-forwarding on a space and ignoring invalid keypresses. In addition, any non-blank line must have either a valid mnemonic or directive, or start with the comment character (;). The sections below describe the source format and the legal entries for each field in detail.

Command | Arguments | Action
N | | Start a new program. This command will clear any ex- isting source, and prompt for source entry from line 000.
I | <nnn> | Insert code from line nnn, or at the end if no argument. If k lines are inserted, existing lines from nnn are shifted down by k.
L | <nnn> | List the source starting from line nnn, or the beginning if no argument. The listing pauses for input every page – hitting return shows the next line, escape cancels the listing, and any other key shows the next page.
X | nnn <mmm> | Delete from lines nnn to mmm inclusive. If just one argument, delete line nnn only. Care must be taken since this will change the line number associated with all subsequent source lines. Delete cannot be undone.
E | nnn | Edit line nnn, and insert after. This is equivalent to typ- ing X nnn followed by I nnn, so the existing line is deleted immediately, and as for the X command, it cannot be recovered.
M | | Show the memory range used to store the current source code.
A | | Assemble the current source code.
V | LABEL | Show the value of the given label or expression.
R | $nnnn or LABEL | Run from address $nnnn. If the program ends with an RTS, control is returned to the shell. Otherwise, re-enter the shell at address $711C($F01C).
D | <$nnnn or LABEL> | Disassemble 20 instructions from address $nnnn, or con- tinue from the last address if no argument.
$ | | Drop into the Apple 1 Monitor. You can re-enter the shell at address $711C($F01C).
P | <c> | Panic! This command attempts to recover lost source (usually due to zero page data corruption). If the first line of source starts with a label, then give the first letter of that label as an argument to this command. For more detail, see the section on source tokenisation 8.2

Table 1: KRUSADER shell commands. Note that any shell commands that use labels are dependent on the assembler’s global symbol table being intact, specifically the pointer information in zero page locations $E9, $EA and $EB, and the table data itself (see figure 1). Optional arguments are indicated by < · · · >.

### 4.1 Labels

Labels are up to 6 alphanumeric characters in length, and may be either global or local in scope. Local labels are defined for the current module only, whereas global labels are accessible anywhere in the program. Up to 256 global labels may be defined, and up to 32 local labels in any one module. Local labels are any labels that begin with a . (i.e. a period).
Labels may be used prior to being defined, i.e. as forward references, and up to 85 forward references are allowed. However, forward references are more limited than normal labels since they are always treated as words (i.e. 2 bytes in size), and any expression involving them must also result in a 2 byte value. In particular this means forward references cannot be used with the < and > operators (see section 4.5).
Once any particular module has been assembled, all local labels are cleared and an error is reported if any forward references involving local labels remain unresolved. However, any forward references to global labels that remain unresolved are simply held, and will only cause an error if they are still unresolved once assembly of the entire program has been completed.
KRUSADER will report an error if a global label is redefined, or a local label is redefined within a module.

### 4.2 Mnemonics

KRUSADER recognises the standard 3 character mnemonics for all legal 6502 instructions. These are shown in table 2. Undocumented opcodes are not supported, and the 65C02 support is discussed in section 6. The editor will not accept any line with an invalid entry in the mnemonic field. Note that when the 6502 executes a BRK instruction, the return address pushed onto the stack is PC+2, and so KRUSADER assembles the BRK opcode as two $00 bytes and an RTI will return to the next instruction. However, the disassembler will show these as consecutive BRK instructions.

Operation | Mnemonics
Load/Store | LDA, LDX, LDY, STA, STX, STY
Transfer | TAX, TXA, TAY, TYA, TSX, TXS
Stack | PHA, PLA, PHP, PLP
Logical | AND, EOR, ORA, BIT
Arithmetic | ADC, SBC, CMP, CPX, CPY
Increment/Decrement | INC, INX, INY, DEC, DEX, DEY
Shift | ASL, LSR, ROL, ROR
Jump/Call | JMP, JSR, RTS
Branch | BCC, BCS, BEQ, BNE, BMI, BPL, BVC, BVS
Status Flag | CLC, CLD, CLI, CLV, SEC, SED, SEI
Other | BRK, NOP, RTI

Table 2: Recognised mnenomics.

### 4.3 Arguments

Table 3 shows the argument format for each of the 6502’s addressing modes. In addition, $nnnn can always be replaced by a label or expression, and similarly $nn so long as the result is a single byte. (Expressions are introduced in section 4.5 below.) A single byte may also be represented using ‘c’ for a given printable character when immediate mode is being used. Whenever a word sized argument actually has a high byte of zero and the corresponding byte size addressing mode is legal, the byte size mode will be used. In addition, some mnemonics support the absolute,Y addressing mode but not the zero page,Y mode. In these cases, a byte sized argument will be increased to word size in order to make the instruction legal. Constants are always hexadecimal.

Addressing Mode | Format | Addressing Mode | Format
Implicit | | Absolute | $nnnn
Accumulator | | Absolute,X | $nnnn,X
Immediate | #$nn or #’c’ | Absolute,Y | $nnnn,Y
Zero Page | $nn | Indirect | ($nnnn)
Zero Page,X | $nn,X | Indexed Indirect | ($nn,X)
Zero Page,Y | $nn,Y | Indirect Indexed | ($nn),Y
Relative | *+/-nn

Table 3: Source code syntax for the 13 addressing modes of the 6502.

### 4.4 Comments

There are two ways to include comments in KRUSADER source. Full line comments may be entered by typing a ‘;’ character as the first character in the line, followed by a space⁵
. Then
all line space from the mnemonic field onwards can be used for comment text. Alternatively, the remainder of any line after the end of the argument field is also reserved for comments, and in this case, no special character is required to preceed their entry.
Comment entry is the only place where spaces are treated literally, and examples of both kinds of comments are shown in the code snippet below:
003 ; | HERE IS A LONG COMMENT
004 | CMP #’Z’+1 | HERE ARE
005 | BNE LOOP | SHORT ONES

### 4.5 Expressions

KRUSADER allows the use of 4 operators in a mnemonic’s argument: +, -, < and > for plus, minus, low byte and high byte respectively. The plus and minus operators take a constant signed byte argument only, and unlike other places where constants are employed, the argument requires no preceeding $. The high and low byte operators are used to extract the relevant single byte from

5Strictly speaking the space is not required, but if it is absent, the source formatting will be upset.

a word sized constant or label, and have lower precedence than + and -, and so are applied last of all when evaluating the expression.
For example, if we define the symbols BYTE .= $12 and WORD .= $3456, then the following expressions are evaluated as listed below:
- BYTE+1 | = $13, | • WORD+FF | = $3455,
- BYTE+80 | = $FF92, | • >WORD | = $34,
- <BYTE+80 = $92, | • <WORD | = $56,
- WORD+1 | = $3457, | • >WORD+10 = $34,
- WORD-1 | = $3455, | • <WORD+10 = $66.

As described in section 4.1, forward references can be used in expressions involving the + and
- operators, but not in expressions involving the < and > operators.

### 4.6 Directives

In addition to the 6502 mnemonics described in section 4.2, KRUSADER supports a number of directives for managing symbolic constants, program structure and data. Directives are entered in the mnemonic field, and always consist of a period followed by a single letter. Each of the available directives is described in table 4 below.

Directive | Action
LABEL .= $nnnn | Define a named constant. The label must be global in
scope, and redefinitions are ignored without error. Expressions or a quoted character are allowed.
LABEL .M <$nnnn> Define a new module, optionally at the specified address, or else just continuing on from the previous module. The label must be global in scope, and redefinitions are ignored without error. Expressions are not allowed.
<LABEL> .B $nn | Store the byte-sized value $nn at the current PC. Ex-
pressions or a quoted character are allowed, but not for-
| ward references.
<LABEL> .W $nnnn | Store the word-sized value $nnnn at the current PC in
little-endian byte order. Expressions are allowed, but
| not forward references.
<LABEL> .S ’cc. . .c’ | Store the string literal at the current PC. The string
must be 13 characters or less, and may not containt
| spaces.

Table 4: Directives supported by KRUSADER. Optional fields are indicated by < · · · >.

## 5 Errors

Error reporting in KRUSADER is necessarily limited by its size constraints, but nevertheless it attempts to capture as many errors and ambiguities as possible, and report them in a meaningful way. Errors can arise in response to a shell command or as a result of an assembly. When appropriate, the offending line or symbol will be displayed.

Error | Meaning
ERR: SYN | Syntax error in either a shell command or a source code line.
ERR: MNE | An illegal mnemonic code was encountered.
ERR: ADD | An illegal addressing mode was encountered.
ERR: SYM | A needed symbol was not found.
ERR: OVF | Too many symbols has lead to a symbol table overflow.

Table 5: KRUSADER error messages.

There are many reasons why an “ERR: ADD” may occur, especially if the offending line involves symbols. For this reason it can be helpful to query the symbols involved using the V command (see table 1). If the symbol is indeed the cause of the addressing mode error, the V command will report a more useful error, specifically “ERR: SYM” if the symbol is undefined, or “ERR: OVF” if the symbol tables are full.

## 6 65C02 Support

With version 1.2 of KRUSADER, optional support for the 65C02 processor has been included. The 65C02 is an enhanced version of the basic 6502 chip, offerring some extra operations and addressing modes, and fixing a few problems with the original design⁶
. Although these enhancements are all useful, essentially the changes are a case of “too little, too late” and frequently programmers choose to stick to pure 6502 code for portability reasons. In addition, 65C02s from various manufacturers have slightly different command sets, thus adding to the confusion. However, since the 65C02 is the CPU in nearly all Replica 1 computers, it makes good sense for KRUSADER to support this chip, and this section describes this support. Nevertheless, no 65C02 specific operations are used in the KRUSADER code itself.

### 6.1 Additional Mnemonics

The ten 65C02 instructions supported by KRUSADER are listed in table 6. Each of these is valid on all versions of the 65C02, and also on the 65C816. No other instructions are supported – specifically the single bit instructions BBR, BBS, RMB, SMB found on the Rockwell and WDC versions of the 65C02, and the STP and WAI instructions found on the Rockwell 65C02 only are not recognised.

6See http://www.obelisk.demon.co.uk/65C02/ for a brief introduction to the 65C02.

Operation | Mnemonics
Load/Store | STZ
Stack | PHX, PLX, PHY, PLY
Logical | TSB, TRB
Increment/Decrement | INA, DEA
Branch | BRA

Table 6: Additional mnenomics supported by the 65C02 version of KRUSADER.

### 6.2 Additional Addressing Modes

The 65C02 introduced two new addressing modes – zero page indirect and absolute indexed indirect. The KRUSADER source code syntax for these modes is shown in table 7.

Addressing Mode | Format
Zero Page Indirect | ($nn)
Absolute Indexed Indirect | ($nnnn,X)

Table 7: Source code syntax for the additional 65C02 addressing modes.

## 7 The Mini-Monitor

The 8K of Replica 1 ROM, with Integer BASIC, the Monitor, and KRUSADER, leaves just enough space for a simple interactive debugger, and this section describes the debugger included with the ROM version of KRUSADER. By making the IRQBRK vector at $FFFE,F point to the DEBUG routine at address $FE17 ($FE0A for the 65C02 version), execution of a BRK passes control to the mini-monitor, and the registers and next instruction are displayed as follows:

A-41 X-FF Y-07 S-FD P-23 CZ
0306 | 20 EF FF | JSR | $FFEF

The P register is shown both as a value, and as a string from “NVBDIZC” indicating which flags are set. (In the above example, the zero flag (Z) and the carry flag (C) are set.) The - prompt indicates that the mini-monitor is waiting for a command. Valid commands are shown in table 8, and are used to change the register values, set the next instruction location, or drop into the Apple 1 monitor.
To return to the mini-monitor from the Apple 1 monitor, type FE21R (or FE0AR if you are running the 65C02 version). Another useful address to remember is the 20 instruction disassembly routine at $FADA ($FAF8 for the 65C02 version), but bear in mind that using this routine involves changing the stored PC value at locations $F5 and $F6, and this must be restored, using either the monitor or the mini-monitor, if you wish to resume the program being monitored.

Command | Action
Ann Xnn Ynn Snn Pnn Lnn Hnn R $ T | Put the value $nn into the A register. Put the value $nn into the X register. Put the value $nn into the Y register. Put the value $nn into the S register. Put the value $nn into the P register. Set the low byte of the PC for the next instruction to be executed to the value $nn. Set the high byte of the PC for the next instruction to be executed to the value $nn. Resume execution at the currently displayed instruction. Enter the Apple 1 monitor. Trace execution step by step (6502 version only).

Table 8: Mini-monitor commands.

### 7.1 Sample Mini-Monitor Session

This section gives a short example of a mini-monitor session. In order to work through this example, first start the assembler, and enter the following short program that includes a BRK instruction.

F000R
F000: A9
KRUSADER 6502 BY KEN WESSEN ? N
000 | LDA #’A’
001 | JSR $FFEF
002 | SEC
003 | BRK
004 | JSR $FFEF
005 | RTS
006
?

Assemble it and examine the resulting code.

? A
0300-030B
? D $300
0300 | A9 41 | LDA | #$41
0302 | 20 EF FF | JSR | $FFEF
0305 | 38 | SEC
0306 | 00 | BRK
0307 | 00 | BRK

0308 | 20 EF FF | JSR | $FFEF
030B | 60 | RTS

When this program is run, it should print A, set the carry flag (C), and then drop into the minimonitor.

? R $300
A
A-41 X-FF Y-07 S-FD P-21 BC
0308 | 20 EF FF | JSR | $FFEF

Use the A command to change the value in register A from 41 to 42, confirm the change by checking the new register display, and then resume the program with the R command. The program will then print a B, corresponding to the new value in register A, and return to the assembler shell as normal.

-A42
A-42 X-FF Y-07 S-FD P-21 BC
0308 | 20 EF FF | JSR | $FFEF
-R
B
?

Now let’s enter a new program, this time involving a subroutine call.

? N
000 | LDA #’A’
001 | JSR SUB
002 | JSR $FFEF
003 | RTS
004
005 SUB | .M
006 | BRK
007 | LDA #’Z’
008 | RTS
009
?

Assemble it, examine the resulting code, and run. It will break into the mini-monitor on entry to the subroutine SUB.

? A
0300
SUB 005 0309-030C
? D $300

0300 | A9 41 | LDA | #$41
0302 | 20 09 03 | JSR | $0309
0305 | 20 EF FF | JSR | $FFEF
0308 | 60 | RTS
0309 | 00 | BRK
030A | 00 | BRK
030B | A9 5A | LDA | #$5A
030D | 60 | RTS
? R $300

A-41 X-FF Y-07 S-FB P-24 B
030B | A9 5A | LDA | #$5A

When in the mini-monitor, unroll the stack by adjusting the value in S, and set the PC to $0305.

-SFD
A-41 X-FF Y-07 S-FD P-20 B
030B | A9 5A | LDA | #$5A
-L05
A-41 X-FF Y-07 S-FD P-20 B
0305 | 20 EF FF | JSR | $FFEF

Now resume, and A will be printed rather than Z since lines 007 and 008 were never executed. Since we also adjusted the stack pointer, the RTS on line 003 will return control to the assembler.

-R
A
?

### 7.2 Tracing Assembled Code

The 6502 version of KRUSADER left just enough space free in the Replica 1 ROM for implementing a single step trace function in the mini-monitor. In the absence of size constraints, this function can be added to the 65C02 version as well, but it would need a little bit of extra code to properly handle the BRA instruction and the absolute indirect addressing mode.
To see how the trace function operates, enter the following short program:

? N
000 | BRK
001 | PHP
002 | SEC
003 | LDX #$0
004 | DEX

005 | PLP
006 | RTS
007
?

Assemble and run, and it will drop into the monitor right away.

? A
0300-0308
? R $300

A-0D X-01 Y-07 S-FD P-30 B
0302 | 08 | PHP

Now we can use the T command to step through the code. After one step, the current value of the status register (P = 30) will be pushed onto the stack, and the stack pointer will decrease by 1.

-T
A-0D X-01 Y-07 S-FC P-30 B
0303 | 38 | SEC

As we step through, we can watch the changes in the status flags in response to the execution of each command. Follow the below to see the carry, zero and negative flags being set.

-T
A-0D X-01 Y-07 S-FC P-31 BC
0304 | A2 00 | LDX | #$00
-T
A-00 X-01 Y-07 S-FC P-33 BZC
0306 | CA | DEX
-T
A-FF X-01 Y-07 S-FC P-B1 NBC
0307 | 28 | PLP

After one last step, the status register will be restored to its earlier value, so the flags will return to off, and the stack pointer increased by 1. Then, as usual, the R command will continue execution of the program, and so the RTS command will return control to the assembler shell.

-T
A-FF X-01 Y-07 S-FD P-30 B
0309 | 60 | RTS
-R
?

## 8 Low Level Information

This section presents some low-level information about how KRUSADER works, and is not required for normal use of the assembler. However, there are many situations where this information is quite important for managing source and machine code, and correcting errors. The most important memory locations are shown in table 9, and discussed in the following sections.

Address | Function | Zero Page Dependencies
$7100($F000) $711C($F01C) | Assembler entry Assembler re-entry (shell) | $F8 – High byte of assembled code storage area $F9 – High byte of local/global table boundary $FE,$FF – Address of source code storage area $E9,$EA – Global symbol table address $EB – Number of global symbols
$730E($F20E) | Move memory (non-overlapping) | $50,$51 – Source location $52,$53 – Destination $54,$55 – Bytes to move
$FE17∗ $FE21∗ | Mini-monitor entry Mini-monitor re-entry (ROM version only) | $F0-$F4 – Register storage (S,P,Y,X and A) $F5,$F6 – Address of next instruction $0F-$11 – Input buffer $E0-$E8 – Code buffer for trace function
$7BDA($FADA)∗ | Disassemble 20 instructions | $F5,$F6 – Address to disassemble from

Table 9: Important function entry points and related memory locations. ∗The minimonitor addresses are $FE0A and $FE1D in the 65C02 version, and the disassembler address is $FAF8.

### 8.1 Memory Map

Proper operation of the assembler requires a number of things to reside in the machine’s memory. There is the assembler code itself, the program source code, the assembled code, and various symbol tables. The default arrangement for both the high RAM and the ROM versions of KRUSADER are shown in figure 1. The local symbol and forward reference tables take up a fixed 1K of space, with 256 bytes taken up by the locals, and the remainder for the forward references. The global symbol table grows downward to a maximum of 2K (corresponding to 256 symbols). The two most important source locations have both been mentioned already, and are $7100($F000) for initial program entry, and $711C($F01C) for returning to the shell.
KRUSADER also uses a number of zero page locations, but mostly as an input buffer and during assembly. The only locations that absolutely must be maintained are $F8, $F9, $FE and $FF. These hold the high byte of the default assembled code storage location, the high byte of the local/global symbol table boundary, and the low and high bytes of the source code storage location respectively (See figure 1 for the appropriate values). Additionally, locations $E9, $EA and $EB are needed if the shell is to have access to the global symbol table for various commands (see table 1), and locations $0F, $10, $11, $E0 to $E8, and $F0 to $F6 are used by the mini-monitor. If you wish to use all the features of KRUSADER while developing assembly language programs, it is wise

KRUSADER code

Forward References
Local Symbols

Global Symbols

Program Source

Program Target

Zero Page

FEFF

F000

7D00
7C00

7400

2000

0300
0100
0000

7FFF

7100

6E00
6D00

6500

1D00

0300
0100
0000
70FF | 7FFF
High RAM Version | ROM Version

Figure 1: Memory map for both the high RAM and the ROM versions of KRUSADER. Note that the global symbol table starts at the local/global table boundary and grows downwards, whereas the program source starts at the low address and grows upwards. As mentioned in section 8.1, the important values are the high byte of the target memory, the high byte of the local/global symbol table boundary, and the start of the source code storage. For the RAM version, the values are $03, $6D, $00 and $1D, and for the ROM version they are $03, $7C, $00 and $20. After initialisation, these values are stored in zero page locations $F8, $F9, $FE and $FF.

to avoid using these locations in your programs. Replica 1 users need to beware of Apple 1 BASIC because it may overwrite several of these values, so they need to be restored before returning to the KRUSADER shell⁷

### 8.1.1 Changing Default Memory Locations

For the RAM based version of KRUSADER, the default values can be altered by changing the values at memory locations $7101, $7105 and $7109 in the assembler code. For the ROM based version, the default values can only be altered after the program has been run, and the alternative values must be entered directly into the zero page locations mentioned above, before resuming KRUSADER at location $F01C⁸

7The P command is useful for restoring the default values to these zero page memory locations.
8The P command will overwrite any values entered in this way.

### 8.2 Source Tokenisation Scheme

Any entered source is stored in a tokenised form in order to save space. The tokenisation employed is quite simple because there was even less space available in the code to implement it! Three special codes are employed – $01 as a field terminator, $00 as a line terminator, and $02 00 to indicate a blank line. Labels, arguments and comments are stored as entered with the field terminator marking their end, and mnemonics and directives are encoded as a single byte. Program end is indicated by a line starting with $00. This simple scheme results in a reduction of the source code size by a factor of 2 to 3.
Also provided in the KRUSADER distribution is C source code for a program that can convert more general source code formats to the required tokenised form, so that they may be uploaded to the assembler. However, this simple program does not translate different formats for directives or addressing mode specification, so if any such changes are required, they must be done manually. Once you have the converted source data, simply launch KRUSADER as normal, enter the monitor and load in the tokenised data to the source storage memory, and resume. The source will then be available to KRUSADER as if you had typed it in as normal. However, syntax and formatting errors in the source may not be well handled since the error handling is designed around the restrictions placed on source input in the usual manner.
Unfortunately the binary source tokenisation is incompatible between the 6502 and 65C02 versions of the assembler due to differences in the mnemonic indices and directive encoding. The ‘-C’ command line option may be used with the tokeniser program to specify the 65C02 version binary format.
One useful thing to keep in mind is the N command simply clears the source program from memory by putting a $00 as the very first byte of the source storage location. So if N is typed accidentally, the source can be easily restored. To do this manually, simply enter the monitor using $, and change this initial byte to either $01 if there was no label, or the first byte of the label, and then resume KRUSADER as normal with 711CR(F01CR). This process is automated by the P command. You should note however that there is no way to recover source lines deleted with the X or E commands since the memory is immediately overwritten.

### 8.3 Moving Memory

If you want to copy a block of memory to another location (if you are backing up source or machine code via the expansion interface for example), you can make use of one of the memory moving subroutines inside the assembler as follows. First work out non-overlapping source and destination addresses – call these srcL, srcH, destL and destH, and then the size of memory to move – sizeL and sizeH. (You can do this using the M command for source or watching the output of the A command for assembled code.) Then drop into the monitor using the $ command, and enter: 50: srcL srcH destL destH sizeL sizeH to set the parameters, and 730ER (F20ER) to do the move.

### 8.4 Testing

KRUSADER comes with a number of sample programs, both in binary and hex dump formats, and these are useful for verifying its correct operation. The most important sample in this regard is TestSuite.asm, which contains a number of modules for testing the assembler. (For the

65C02 version, there is the pair of source files: TestSuiteC.asm for the pure 6502 tests, and TestSuite65C02.asm for tests of the 65C02 extensions.) The first test of course is that the source assembles without error, then R MAIN will cause the program to verify its own assembled code and report any errors. This test suite covers all the 6502 instructions, using all their addressing modes and various formats for arguments where relevant, as well as each of the available directives. In addition, both forward referencing and the various kinds of expressions supported by KRUSADER are tested – both alone and in combination with various addressing modes. A successful run of this suite of tests is a very good indication that KRUSADER is functioning properly.
Because of the size of the test suite code, it can not be run with the RAM version of KRUSADER without changing the start address for program source storage as described in section 8.1.1 above in order to allow enough room for the source code, the assembled code, and the global symbol table. Specifically, prior to running KRUSADER, the value at address $7101 needs to be changed to $14, or if KRUSADER is already running, this value of $14 can be loaded directly into the zero page address $FF.

## 9 Release History

- KRUSADER 1.0 (May 2006)

– First version released.

– Target CPU is 6502 only.

- KRUSADER 1.1 (July 2006)

– Fully tested version - several bug fixes over version 1.0.

– Comes with code for a thorough automated testing of itself.

– Various enhancements over version 1, most notably:
∗ Forward references can cross module boundaries.
∗ Symbol redefinition is reported as an error.
∗ Comment only lines.
∗ Approximately 20% faster assembly.

– This version was added to the Replica 1 SE ROM.

- KRUSADER 1.2 (August 2006)

– Fixes an obscure bug in version 1.1 that prevented assembly of JMP or JSR commands targetting page zero.

– Improved syntax checking.

– More compact implementation saves more than 200 bytes over version 1.1.

– Extra space used to implement a mini-monitor for interactive debugging.

– Also available is KRUSADER 65C02, a version that supports 65C02 commands in both the assembler and disassembler.

– Still fits inside the 3840 free bytes of the Replica 1 ROM!

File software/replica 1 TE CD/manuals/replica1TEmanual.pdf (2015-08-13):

# replica I

# Setup and Users Manual Setup and Users Manual

MARCH 2009 TE EDITION

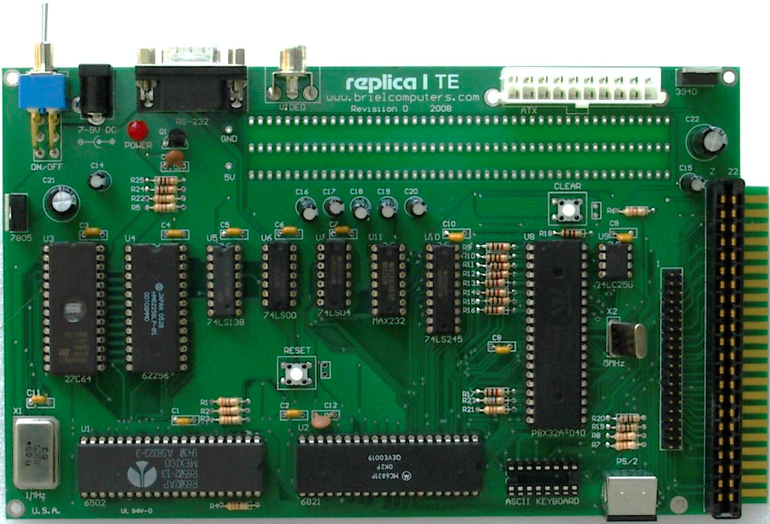
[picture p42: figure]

## Briel Computers Briel Computers Briel Computers

## 5392 Cornell Blvd North Ridgeville, OH 44039

Replica 1 TE | Users Manual
© Briel Computers 2007 | page 2

All materials, schematics, and hardware designs provided without any warranties. Although this material has been carefully examined, Briel Computers takes no responsibility for any errors in printing.

Version 3.0
Published by Briel Computers
5392 Cornell Blvd
North Ridgeville, OH 44039
USA

Copyright 2009 Briel Computers. All rights reserved. Printed in the United States of America. Except as permitted under the Copyright Act of 1976, no part of this publication may be reproduced or distributed in any form or by any means, or stored in a database or retrieval system, without the prior written permission of the publisher, with the exception that the program listings may be entered, stored, and executed in a computer system, but they may not be reproduced for publication.

© Briel Computers 2007 | page 3

# Forward Forward

How the replica 1 came to be

Thank you for purchasing your replica 1 computer. I take pride in every kit and assembled replica that is shipped and my goal is that all kits and assembled boards work as designed. In early 2001 I was an avid collector of vintage computers. I had started with an Apple IIe because it was close to my first computer the Apple IIplus. I, like many people who get the urge to relive the yesteryears of computing looked to eBay to find my past. After receiving my first computer I found myself wanting a monitor, a disk drive, anything to make it fully functional. I didn’t just want a mantle piece; I wanted to actually use my vintage machine.

After spending some time with my Apple I remembered other computers I had seen in magazines but couldn’t afford at the time. I little searching and I was able to start a nice little collection of home computers. I was addicted to vintage computing and collecting everything I could get my hands on.

I was really proud of the fact that every machine I owned, not only worked but I had software to run on them. I was fast becoming an expert in the area of software conversion from the modern computer realm back to actual vintage media like 5 ¼” disk.

Feeling proud that I had a nice collection going I stumbled upon the www.applefritter.com website. I felt pretty versed with apple II hardware and I noticed a small forum there and poked in to read some of the posts. I didn’t see anything out of the ordinary but I noticed a subject right above the Apple II section labeled Apple I. Well, I had never seen an Apple I and had only herd the stories like most people about how Woz and Jobs started Apple Computers from their garage. I had to read more.

I quickly learned that only about 50 Apple 1’s remained in existence from about 200 boards and they were highly collectable and way out of my price range. I read a post where people talked about making a replica but nobody was really stepping up to the plate. I have an education in engineering so I decided to take a look into the Apple 1 hardware.

In March 2002 I wrote to the Applefritter forum requesting some information on the Apple 1 and I informed the group of my intentions. I was well received and many former and current owners of Apple 1 computers gave me information and documentation to get started.

With manuals and emails from owners in hand, I looked over every inch of the Apple 1. I quickly decided not to use all the original components from the Apple 1 due to their lack of ability. Although there are chip suppliers that carry surplus components, their prices and minimum orders are just out of the question. This left me with a decision that many people questioned. I could have made the replica 1 look like the Apple 1 but in the spirit of Woz, I choose to go with more modern components and reduce the chip count as low as possible.

I quickly found that I could interface 32K of RAM with no address decoding. Simply using Address line A15 as the select line, I could activate the RAM chip with A15 off. So, if the replica 1 was looking anywhere in the address range 0000-7FFF A15 would be low and RAM chip select activated. If the replica 1 was looking at address range 8000-FFFF A15 would now be high and the RAM chip select would be deactivated. I added some logic so that the access time of the RAM write cycle was only during PHI2 of the 6502’s clock. For this I used a 74LS00 NAND gate IC. I needed to invert the R/W signal and AND in PHI2. This required 2 of the 4 NAND gates in the IC.

© Briel Computers 2007 | page 4

My next step was to add some address decoding so the replica 1 accessed the I/O chip 6821 PIA and ROM at the same addresses the Apple 1 used. I used a 74LS138 to decode addressing for both the 6821 and an 8K EEPROM. I also made sure that the space for BASIC (E000-EFFF) was EEPROM so BASIC could be stored in ROM.

I now had a core CPU section replicated from the Apple 1. I still had no video section and I needed to build a prototype. After some delays I finally built a prototype on wire-wrap and tested it. It didn’t work. I needed to troubleshoot the board but my free time was very hard to come by and the replica sat on the shelf for a few months.

In November of 2002 I received an email from Leander Kahney of Wired Magazine. He had been reading on the replica project and wanted to interview me. My first reaction was, “Why me?” I had no idea the cult following that Apple had. I really was fond of Apple since the beginning but Apple has such loyal owners and they love everything that involves the history. So, here I am on the phone with Leander as he is asking me questions about why I am doing the project, and when will it be completed and what will I be selling these for? What? I didn’t have the heart to tell him that the project is on the self, that I have no idea what to sell these for even if I had a working version. Little did Leander know that because of him, the replica 1 was pulled off the shelf and completed. I started from scratch, and created a breadboard version of the replica 1. This time it worked… Sort of… Well, the I/O chip, the 6821 was sending binary code for a “\” which means that the replica was seeing a reset and the Woz monitor was trying to output a “\” to a TV monitor. Now I needed a video solution.

Right after the Wired article was released, I received an email from Greg Glawitsch. He stated his interest in the project and said that he had a “down and dirty” solution to the video problem. His answer was to use a microcontroller to output TV text like the video terminal section of the manual. He offered to help by writing the firmware to do this and it would only require a couple external IC’s to help the microcontroller. Wow, 3 chips to do what took about 24 on the Apple 1. This was perfect. And with some work with Greg, we had a working video section.

In August 2003 the first of the replica prototypes were being made. I didn’t have a name for the board yet and simply called it A1 replica. I also just put my initials on the board with the year 2003. Shortly after my first prototypes were built, I created Briel Computers. At this stage my old high school friend Chris contacted Woz through his webmaster asking for permission to use the Apple 1 code. His approval of the project prompted another Wired article.

In October 2003, the first replica 1’s was being built and thus completing a 20 year old dream to design and sell my very own computer. Thanks to Woz for being such a strong influence and great guy to give the ok for this project.

Vince Briel

© Briel Computers 2007 | page 5

# Setup and Users Manual

# Index

Chapter 1: | A Brief History of the Apple 1
Chapter 2: | Introducing the replica 1
Chapter 3: | Unpacking and Setting Up
Chapter 4: | Assembling Kit Version
Chapter 5: | Programming the replica 1
Chapter 6: | Using The Serial Interface
Chapter 7: | Using the Krusader Assembler
Chapter 8: | Troubleshooting your replica 1
Appendix A: | ASCII Keyboard Pin Out
Appendix B: | Replica 1 Memory Map
Appendix C: | Monitor Listing

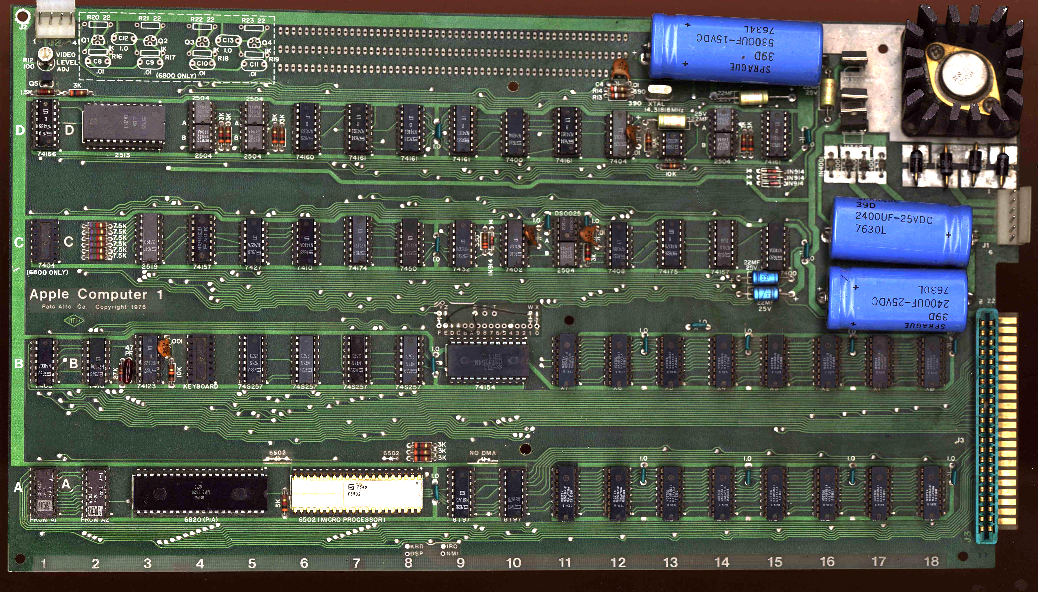
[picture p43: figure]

© Briel Computers 2007 | page 6

## Chapter 1: A brief History of the Apple 1

Steve Wozniak had designed and built many different little projects before the Apple 1 computer. The Apple 1 was not even his first computer design. He had designed the “cream soda computer” long before the Apple 1. He had even designed a TV terminal that could be hooked up to a mainframe computer using a keyboard and your TV as the display. Of course he also built the infamous “blue box” so people could phone phreak and make free long distance calls. It wasn’t until Woz decided to combine two projects, and make one complete computer never seen on the market before. He designed a single board computer and combined his TV terminal to create what is today known as the Apple 1 Computer. He first presented the project to the Homebrew Computer Club and it was well received. At that time, the only major computer out there was the Altair 8800 and that only came with LED’s and switches. The Apple 1 had a keyboard and a monitor. When he showed this to his friend Steve Jobs, Jobs was excited and immediately wanted to make more to sell.

Figure 1: Actual Apple 1 Computer

In April 1976, Steve Jobs and Steve Wozniak decided to start Apple Computer Company. It was based on a computer design that Wozniak had completed making a computer that could display text on a TV and use a keyboard without any additional boards. One board could do all of this. While it wasn’t the first home computer, it was the first to give you all of these features on one board without any addition hardware. No entering code by flipping switches and looking at LED’s. You could actually sit down at a table and type code into the computer using a standard keyboard. Steve Jobs saw something great in this project and was eager to start selling these boards.

Woz distributed schematics and source code listings for the Apple 1 computer at the Homebrew Computer Club meetings in Northern California bay area. Steve Jobs knew that there was enough interest in the boards at the Homebrew club to sell boards to the members. 200 boards were printed and most of them were assembled but not all of them. They assembled boards at night in Job’s parents’ garage and sold some to the Homebrew Club. It wasn’t until a local computer store purchased $50,000 worth of boards that anything significant had happened. After that, things changed.

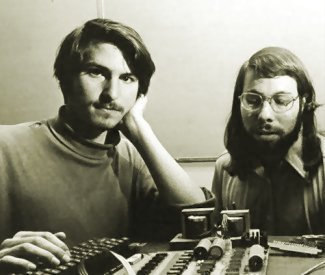
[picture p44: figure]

© Briel Computers 2007 | page 7

They knew they had a great product and that the average person could have a computer on their kitchen table. Woz quickly worked on a BAIC for the Apple 1 but it still lacked a means of storage. Shortly after the Apple 1’s release, Woz designed a cassette interface simply named the ACI (Apple Cassette Interface). This interface allowed the user to store programs onto an audio tape using simple 1 and 2Kh signals to store the data.

While the new interface was being designed and BASIC was being written, the end of the Apple 1 was already near. Woz was already working on the next version of his design. While many people thought the Apple II was the same as the Apple 1 with just more features, the Apple II was a completely new design from scratch. This new design could do color and using processor accessible RAM; you could do graphics and more. While this was all being designed, the Apple 1 was still being made and sold.

BAIC was finally released and that gave the Apple 1 a high level language for people to program in. This BAIC was not only written for the Apple 1, but it was also written for the Apple II at the same time. As a matter of fact, if you look at a disassembly of the Apple 1 BAISC you will see some commands built in that are impossible to perform, such as COLOR. There was no color graphics on the Apple 1, only text.

As soon as the Apple II was release, Jobs wanted to get rid of all the Apple 1 computers. He offered deals, like half off an Apple II with the trade in of your old Apple 1. He so wanted to get rid of the Apple 1, that rumor has it, he even gave some Apple II’s for even exchanges. Some he handed to engineers and programmers at Apple to use, others he chopped up with a band saw. So, while there were 200 boards made from the board house, not all were assembled and many were destroyed on the exchange program.

Today, approximately 50 Apple 1’s are known to exist making it one of the most sought after vintage computers. Some auctions have fetched upwards of $50,000 for an Apple 1 but the average selling price is around $16,000-$25,000.

Figure 2: Steve Jobs and Steve Wozniak shown with an Apple 1 computer in 1976

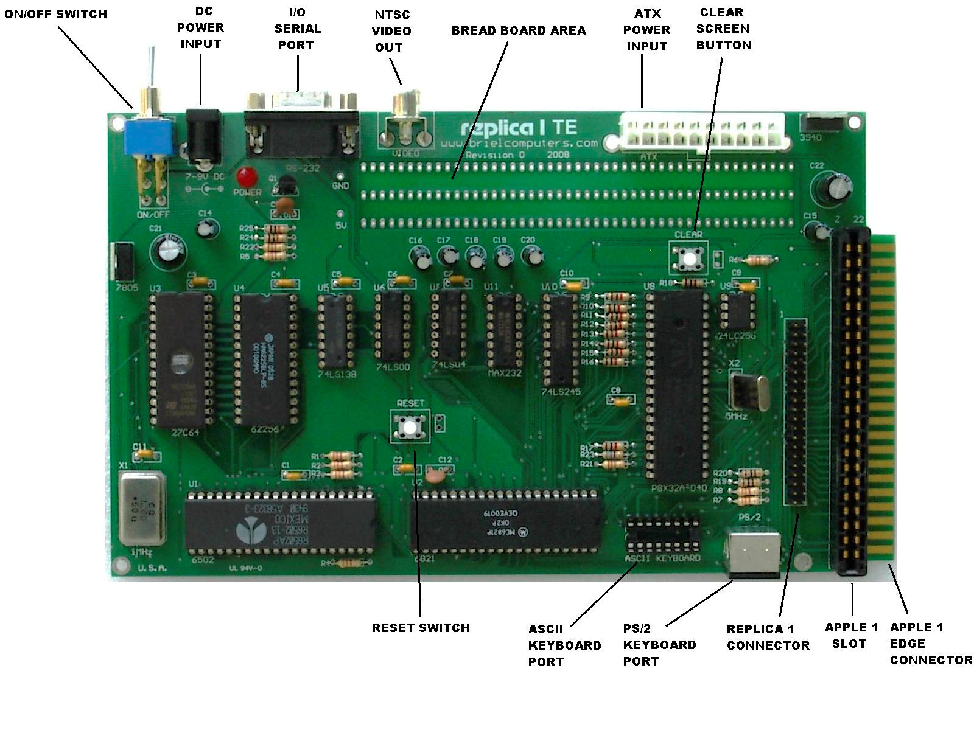
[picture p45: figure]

© Briel Computers 2007 | page 8

## Chapter 2: Introducing the replica I TE computer

The replica 1 computer was designed to give those people a chance to see what an Apple I computer looked and acted like. Most people have never seen an Apple 1 running and the replica 1 helps us see what Woz had created. The goal of the replica 1 project is to simulate the functional aspects of the Apple 1 so that all hardware and software designed for the Apple 1 can be used.

Figure 3: Key component features on the replica 1 TE

Not just a simple hobby board. The replica 1 contains features such Apple 1 compatible expansion slot, original replica 1 connector and your choice of ATX or wall wart power supply.. Other features include a built in serial port that intercepts the keyboard and video signals so software drivers are not required. A PS/2 keyboard port is onboard for those who don’t have ACII keyboards, and a simple On/Off switch for applying power to the replica 1.

Firmware upgradeable: The new TE model (Third Edition) includes a Parallax Propeller micro-controller for the onboard I/O. The source code is open source and is included with the replica 1 on the CD and updates can be made via free software to program the Propeller from Parallax website. Programmers are welcome and encouraged to use the Briel Computers forum to announce custom developed features and improvements to the firmware. The owner takes all responsibility for any firmware installed that is not released or approved by Briel Computers. Using untested firmware could damage the replica 1 TE.

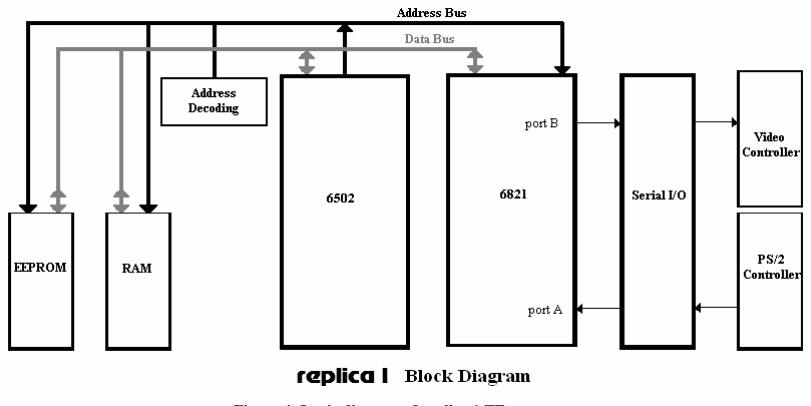
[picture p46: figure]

© Briel Computers 2007 | page 9

The replica 1 expansion header was designed for the hobby engineer in mind. The Apple 1 expansion slot gives the user the ability to use Apple 1 compatible boards, or expanding even more with the edge connector and the 3 slot adapter.

As well as being able to run all the original Apple 1 software and hardware, the replica 1 has the capability to use modern hardware like a ps/2 keyboard and use a standard PC ATX power supply or wall brick power supply to power the replica 1. The added Serial port gives the user the ability to download programs right from your PC or Mac into the replica 1 making software sharing possible.

Figure 4: Logic diagram of replica 1 TE computer

Keeping a simple design structure was important with the replica 1. Chip reduction is the way Woz designed the Apple 1 and the replica 1 follows in its path. While it’s true that the replica 1 TE board contains more IC’s than the original replica 1, the added features give the user flexibility that wasn’t available before. The TE (Third Edition) replica 1 uses the new Parallax Propeller as the I/O controller. This new micro-controller has the ability to handle all I/O including video, serial, and PS/2 port. This feature reduces chip count and eliminates the need for jumpers.

While the replica 1 has been in production for 5 years, it is always a work in progress. Sometimes bugs and fixes come up and changes to the board are always discussed on the replica 1 forums. For the latest in design changes and modifications, see the replica 1 forum at:

http://www.brielcomputers.com/phpBB2/

The replica 1 TE is currently the most advanced replica Apple 1 produced. It encompasses features as requested by current or future owners of replica 1, as well as design improvements, bug fixes and other enhancements. All revisions remain backward compatible with the original replica 1.

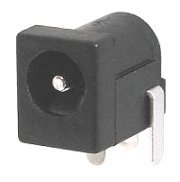
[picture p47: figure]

© Briel Computers 2007 | page 10

Chapter 3: Unpacking and Setting up system.

Before you begin setting up your replica 1 computer, make sure you have plenty of table space. Do not power up the unit while touching any part of the circuit board and contact Briel computers if you are unsure about any part of the setup process.

You will need the following items to get your replica 1 up and running:

1. The replica 1 system board.
2. ATX power supply or 7-9V DC wall brick supply positive center.
3. Keyboard, a PC PS/2 or an Apple II/II plus (not //e or //gs).
4. A TV with composite video in, or a composite computer monitor.
5. A video cable to attach to the TV from the replica 1.

Place or mount the replica 1 board so that it is secured. Make sure no metal objects can touch the circuit board or damage could result. Next you need to choose what type of power supply you are going to use. There are three ways you can power your replica 1 TE. ATX power supplies are the most commonly used power supplies in today’s computers. You need to use an ATX power supply if you are planning on using the Apple II ASCII keyboard because -12V power is required.

If you only intend on using the ps/2 style keyboard you only need a 7-9V wall brick style power supply. While the replica 1 shows 7V on the board, it is best to use something around 8-9V 1000mA (1.0A) if adding on an add-on board. You may need to find a heat sink for the 7805 voltage regulator to keep it cool under that much voltage drop.

Figure 5: DC wall brick connector (Use 7-9V positive center connection power supply)

CAUTION: DO NOT ATTACH BOTH A WALL WART POWER SUPPLY AND AN ATX AT THE SAME TIME TO YOUR REPLICA 1. DOING SO COULD DAMAGE YOUR REPLICA 1.

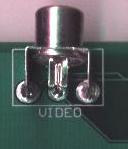
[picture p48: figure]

© Briel Computers 2007 | page 11

Once you have the power source connected, you can attach your monitor or TV to the replica 1 with a standard composite video cable. Most modern TV’s have a composite input located on the back of the TV. Plug your RCA style cable into the back of your TV or monitor and locate the video connector as shown and plug your cable (not supplied) into the replica 1 (figure 8). While the replica 1 is designed for NTSC composite video, PAL will work but will be slightly reduced in size on the screen.

Figure 6: Video connector

Next you need to attach a keyboard. You have two choices for keyboards; ps/2 pc style keyboard or an ASCII keyboard. To use the ps/2 style keyboard locate the ps/2 port on the back edge of the replica 1 and plug your keyboard into that port (see figure 9).

Figure 7: ps/2 keyboard port

If you are using an Apple 2 or 2+ ASCII keyboard, locate the ASCII keyboard port near the replica 1 logo on the board and plug your 16pin dip cable into the board. Note that pin 1 is next to the ‘A’ on the ASCII KEYBOARD label.

© Briel Computers 2007 | page 12

Figure 8: ASCII keyboard port

Now you are ready to test your replica 1 TE. Make sure your TV or monitor is turned on and flip the switch on the replica 1 up. The red LED next to the switch should light up and a solid block cursor should appear in the upper left corner. If you do not see the cursor at the top of the screen, or the LED is not lit, turn the replica 1 off and recheck your work.

Press RESET on the board and your replica will respond with a backslash “\” and the cursor will drop to the next line. The cursor is a blinking ‘@’ symbol just like the original Apple 1 computer. You are now in the Woz monitor and ready to use your replica 1 TE. If you are using the PS/2 style keyboard you will notice that the caps lock is already on by default for you. The apple 1 only understands uppercase characters so does the replica 1.

© Briel Computers 2007 | page 13

## Chapter 4: Assembling the replica 1 TE kit

If you have experience with soldering circuit boards, then not only will you enjoy the replica 1 kit, but you will also have the pride in assembling it yourself while saving money. If you have never built a circuit board kit, please start with something a little simpler before attempting to build the replica 1. This chapter is only designed as a brief guide to help you assemble your replica 1.

Kit contents:

All kits have been carefully assembled to insure that no parts are missing; however, you should check the inventory to make sure you have everything. If you find anything missing, please contact Briel Computers.

IC’s:

QTY | MODEL | ID | # of Pins
1 | 6502 | U1 | 40
1 | 6821 | U2 | 40
1 | 62256 | U4 | 28
1 | 27C64 | U3 | 28
1 | P8X32A-D40 | U8 | 40
1 | 74LS00 | U6 | 14
1 | 74LS04 | U7 | 14
1 | 74LS138 | U5 | 16
1 | 74LS245 | U10 | 20
1 | MAX232 | U11 | 16
1 | 24LC256 | U9 | 8
1 | 7805 | V1 | 3
1 | 3940 (3.3V) | V2 | 3

Sockets:

QTY | # of Pins

3 40 pin
2 28 pin (.6 wide)
1 20 pin
2 16 pin
1 16 pin duel swipe
2 14 pin
1 8 pin

Crystals and Oscillators:

QTY | Type | Size | Speed
1 | Crystal | HC49/U | 5MHz (X2)
1 | Oscillator | Full Can | 1MHz

© Briel Computers 2007 | page 14

Connectors:

QTY | Type

### 1 ATX Male connector 1 RCA style video connector 1 PS/2 keyboard connector

1 2.1mm DC power connector

### 1 DB-9 Female serial connector

1 40 pin .100” expansion header 1 44 pin .156” Apple 1 style slot

Switches:

QTY | Type

### 2 PCB board-mount mini momentary push button 1 PCB board-mount toggle DPDT switch

Resistors:

QTY | Size | ID
9 | 3.3K | R1-R8
10 | 1K ohms | R9-R18
2 | 100 ohms | R19, R20
2 | 220 ohms | R21, R22
1 | 560 ohms | R23
2 | 10K ohms | R24, R25

Capacitors:

QTY | Size | ID
11 | .1uF | C1-C11
2 | .01uF | C12, C13
7 | 10uF | C14-C20
2 | 100uF | C21, C22

DISPLAYS:

QTY | Type

### 1 Jumbo Red LED

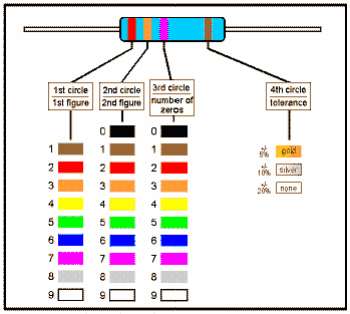
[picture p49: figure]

© Briel Computers 2007 | page 15

Misc:

QTY | Type

1 2N4401 Transistor
1 8.5”X5” replica 1 TE silk screened PCB with expansion male edge

Tools required for assembly:

Soldering iron, solder, wire cutters, needle nose pliers, and a multi-meter

Before you begin:

Make sure you have proper working space and that you heat your iron before beginning the assembly. This kit is not for beginners and Briel Computers assumes that you have some prior experience with soldering circuit boards. If you have never soldered circuit boards before or don’t feel you are ready, you should build other kits of a smaller, less complex nature before building your replica 1.

Reading and identifying resistors:

In previous revisions of the replica 1 kits, all parts were labeled in an effort to make it easier on the kit builder. Now, the manual is being expanded to help newcomers to kits learn to identify the parts and read their values. Resistors have 4 colored bands on them that are used to identify the value. The first 3 are the value and the 4th colored band is to identify the tolerance of the resistor. The 4th band is usually silver for 10% or gold for 5% tolerance. Here is how to read the other three to get the value:

Figure 9: Resistor color code chart

Let’s assume the resistor you are trying to identify has the colors orange, and then another orange, then a red band followed with a gold band. So, to read the resistor, find the gold or silver band, that identifies the 4th band. Hold the resistor so the 4th band is on the right side and read the first color on the left.

© Briel Computers 2007 | page 16

The first color is orange which has a value of 3 according to the chart above. The second color is also orange which also has a value of 3. The 3rd number indicates how many zeros follow the first two numbers. So, red is 2 zeros. This gives your resistor a value of 3, 3 and 2 0’s (00) or 3300=3.3K. This may take some practice but look through all the resistors and identify them without a meter if you need practice.

Reading and identifying capacitors:

It takes less time to read the values of the capacitors than to read the values of the resistors. The key is to understand and read the numbers correctly.

Larger capacitors may have the values clearly printed on them. For example:

10uF = 10 Micro Farads

Smaller capacitors however, may only have 2 or 3 numbers on them. For example, the 22uF capacitors say 22J. .1uF capacitors have the value 104 on them. This is similar to the resistor codes where the first 2 numbers are actual numbers and the 3rd number is the multiplier code. So 10 X 4 is 100,000 and the value is in pico Farads (pF). Converting it to a proper numbering format gives us the value .1uF. To make things easier, here is a list of the values on the capacitors used and the numbers printed on them.

Value | Identifying numbers QTY
.01uF | 103 | 2
.1uF | 104 | 15
22pF | 22J | 4
.22uF | 224M | 1

Power LED:

Figure 10: LED pin internal diagram

Looking at the LED there are two connectors, the Anode is longer and has the smaller connector inside. The cathode is the negative side. It has a shorter lead and a larger part inside the LED. The cathode is the negative post. Connecting is simple on the replica 1. The LED silkscreen on the replica 1 has the positive + marked. Simply put the longer anode connector into the positive side when installing.

Ready to Begin Assembly:

Now that you have inventoried all parts you are ready to begin assembly of your replica 1.

Step 1: Start with the resistors. Bend the leads on each side of the resistor 90 degrees near the edge of the resistor. Insert the resistor into its proper location until it rests flush with the board. They are not polarized so

© Briel Computers 2007 | page 17

that can be installed either direction. While holding the resistor with one finger, bend the pins on the bottom side away from each other so that the resistor will not fall out and will stay flush on the board. Flip the board

over and solder the resistor down to the board. Cut the extra lead length off and throw away. Repeat for all resistors carefully making sure each one goes in the proper location.

Step 2: Solder in the reset and clear screen buttons. You may need to tape these down before you flip the board over.
Step 3: Install the sockets. I prefer to start with the 40 pin sockets but you can do them in any order you prefer. Please note that one of the 16 pin sockets is a duel swipe older style that goes in the ASCII keyboard socket. When installing sockets, notice the notch at one end of the socket, find the matching notch on the board. Hold the socket firmly to the board and flip the board over. Carefully set down the board so that the socket doesn’t come out. Solder in place. Repeat for the remaining sockets.
Step 4: Install the 1MHz oscillator. If you look carefully you will notice that one corner is not rounded. This indicates pin 1. Match pin 1 to the silkscreen (closer to the X1 label). Install like the sockets but clip the extra lead length off.
Step 5: Install the .1uF & .01uF capacitors C1-C11, C12 & C13. They are not polarized so that can be installed either direction. Install the capacitors in a similar way to the resistors where you bend the leads away from one another to hold the capacitor in place so you can flip the board over. Solder and cut the extra lead length off.
Step 6: Install the LED. As described earlier the longer lead is the +. Install the LED all the way flush, and bend the leads away from one another like with the resistors and capacitors. Solder and cut the extra lead lengths.
Step 7: Install the 40 pin expansion connector (notice there is no incorrect way to install but pin 1 is closer to the reset button. This will be a little harder to install because the header pins are close together.
Step 8: Install the Transistor. Orientate the transistor the same as on the board and insert all the way flush as possible with the board. Solder and remove the extra lead length.
Step 9: Install the DC power connector and power switch. The pins on the switch may require adjusting.
Step 10: Install the RCA video connector. When you insert the connector into the board, bend the center pin over flat so it lay’s down. Solder pins into place.
Step 11: Install the DB9 RS232 connector. Use care when inserting the connector into the board. Placing a little solder on the large holding tabs helps ensure a firm connector.
Step 12: Install the PS/2 keyboard connector. Some versions of this connector come with extra retaining tabs on the left and right side, remove before installing. Use care when installing as this connectors pins are fragile.
Step 13: Install the 44 pin Apple 1 slot. Pin 1 on the slot has a dot next to it.
Step 14: Install the C14-C20 10uF capacitors. The arrow on the capacitors points towards the NEGATIVE. On the PCB the positive is identified, so the negative is the other pin hole. Mount flush onto the board, bend the leads away from one another and solder. Cut away excess lead length.

© Briel Computers 2007 | page 18
Step 15: Install two 100uF Capacitors C21 & C22. Installation is identical to the 10uF Capacitors installed in
step 14.
Step 16: Install the two voltage regulators. The 7805 goes near the power switch and the 3940 goes near the upper right corner. The large flat metal part of the regulator faces to the edge of the board on both regulators. Install the regulators all the way flush with the board. The leads are thick and are harder to cut after soldering.
Step 17: Install the ATX power connector. Be sure the connector is flush with the board before soldering.
Step 18: Install the 5MHz crystal. The crystal is not polarized so it can be installed in either direction. Install flush to the board, bend the leads away from one another and solder the leads. Cut the extra lead length.

Inspection of your work:

Now that you have completed your soldering, take a few minutes and look over your work. Check for solder spots that might not be good connections to the posts. Look for bridges where solder may have jumped over where it wasn’t supposed to go.

Testing your replica 1:

Before installing your IC’s, power up your replica 1. With your multi-meter, check the voltages 5V and GND. make sure your LED is lit properly. Test pin 14 and pin 7 on the 74LS00 & 74LS04 to make sure you are getting 5V. Check pin 8 and 16 on 74LS138 for 5V. Once you are satisfied that the power is being distributed correctly, power off the replica. Install the P8X32A-D40 and 24LC256 EEPROM. Attach an RCA cable to the replica 1 video port and attach it to your monitor or TV. Power up your replica 1 and see if you get a cursor. It may move across the screen and that is normal since it is getting a false trigger. If the video section is working properly, turn off the replica 1 and install the rest of the chips. Power up the replica 1 again, this time press ‘RESET’ button after a couple of seconds and see if the replica 1 resets.

If the circuit is working properly, you will get a “\” backslash followed by the cursor ‘@’ moving to the next line. At this point you can power off the replica 1 once more and attach your keyboard. Power up the replica 1, reset the circuit and try out the keyboard. Congratulations, your replica 1 is now assembled and ready to use.

Caution: Before plugging in the power supply, keyboard and video connector, thoroughly check over your work for errors.

Any parts that get accidentally damaged during the building process can be replaced at the owner’s expense. Contact Briel Computers for any replacement parts needed.

The goal of Briel Computers is that ALL replica 1 kits get completed successfully. If you are having a problem, please feel free to ask for help.

© Briel Computers 2007 | page 19

Use this page to document any notes needed for assembly

© Briel Computers 2007 | page 20

## Chapter 5: Programming the replica 1

The replica 1 can be programmed in one of 3 built in ways. You can enter values into memory directly using the Woz monitor. Another way is to use BASIC that is built into ROM. BASIC was the most commonly used language among beginner all the way to experienced programmers in the 70’s and 80’s. The third built in way to program your replica 1 SE is to use the new Krusader© assembler written by Ken Wessen.

Using the Woz monitor:

The Woz monitor is a tool that gives you direct access to memory to program code that the 6502 will interpret. To use the Woz monitor program, simply power up your replica 1. Just like the original Apple 1© you had to manually reset the circuit to get the computer started. Simply press the reset button on the circuit board and you will see a backslash ‘\’ and the cursor will drop below the backslash. You are now in the Woz monitor.

There are three basic functions to the Woz monitor. First, you can examine a range of memory or just one location. To examine one location of memory, just type in the address and press [return]. To view memory location 300 it would look like this:

300[RETURN]

0300: E1

The cursor will then move below the line that displayed the value of the memory location. To display a block of memory, type in the starting location followed by a period ‘.’; follow that with the ending location. To view 300-32F locations, type:

300.32F[RETURN]

The replica will display the memory contents up to 8 locations per line:

0300: E1 20 94 17 08 26 60 10
0308: E4 98 02 86 88 44 A5 50
0310: 3C 2D 20 9D 7E 18 60 8C
0318: 0F 00 18 24 90 24 06 50
0320: 42 07 06 A0 89 81 00 C6
0328: 80 60 41 12 E0 1B A3 04

Again, the cursor will be below the listing.

To program a location in memory, simply type in the address followed by the value to write to it. For example, to program location 300 with the value FF, simply type:

300:FF [RETURN]

The Woz monitor will respond by displaying the old value of the memory location:

0300:E1

© Briel Computers 2007 | page 21

The monitor will once again drop below the displayed line and be ready for more input. To program more than one consecutive location simply put a space after the value, then type in the next value of the next memory location. For example, to program 300 with FF, 301 with EE and 302 with DD type the following line:

300: FF EE DD [RETURN]

The monitor will respond with the prior contents of the first location you programmed (300):

0300:E1

If you examine the other two locations in memory, you will see the new value is now stored. Type:

301.302[RETURN]

The monitor then displays:

0301: EE DD

Notice it did not display 8 locations of memory across because you only asked for two. Once you have entered your program into memory, you can start your program by entering the memory location that it starts at followed by R for run and [return]. Let’s load and run a simple program through the Woz monitor. Type in the following code:

300: A9 0 AA 20 EF FF E8 8A 4C 2 3 [RETURN]

Notice the ‘3’ and the ‘2’ are single digits, this is correct. You can type in ‘02’ or ‘00’ but it is not necessary. After you have typed in the line, type:

300.30A

This will now print out the contents of the memory locations you just typed in. Verify the contents match the code, then type:

300R [RETURN]

The program should then print out a continuous stream of characters. Every once in a while the screen will clear; this is a normal function of the replica 1 having the ability to clear the screen through software.

© Briel Computers 2007 | page 22

Programming in BASIC:

To start the replica 1 and enter BASIC, turn on the replica and press reset. Next type in:

E000R [RETURN]

The memory contents of E000 are displayed and BASIC begins. The prompt for BASIC is ‘>’. This is how you know you are in BASIC. Here is a simple ‘HELLO’ program you can type in:

### 10 PRINT “HELLO WORLD!” 20 END

RUN

When you type in RUN, the program will print out “HELLO WORLD!” onto the display, and then it will return to the prompt. You can view your program by typing in “LIST”. To get started programming in BASIC, read the BASIC manual. There are many example programs on the internet to help you get started.

Krusader:

The replica 1 has 8K of EEPROM (ROM) space onboard. 4K is used for BASIC; 256 bytes are used for the Woz monitor. This leaves just under 4K available. Now, thanks to Ken Wessen, that space is now occupied with a powerful assembler called Krusader. To start Krusader, type in ‘F000R’ [return]. To program the assembler, refer to the Krusader manual for sample programs and commands.

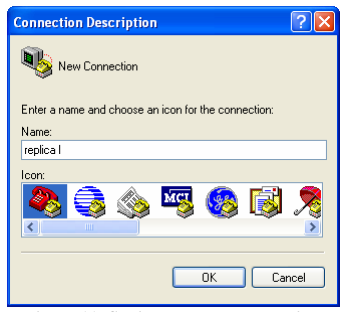
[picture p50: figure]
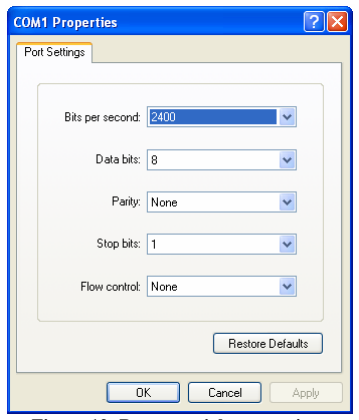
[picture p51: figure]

© Briel Computers 2007 | page 23

## Chapter 6: Using the Serial Port

Setting up Hyper Terminal:

Start a new session of Hyper Terminal and select a name for your session.

Figure 11: Setting up a new connection

Click on OK; next, select which COM port you are connected to and select OK. Next, set up your COM port as shown: 2400, N,8,1

Figure 12: Proper serial port settings

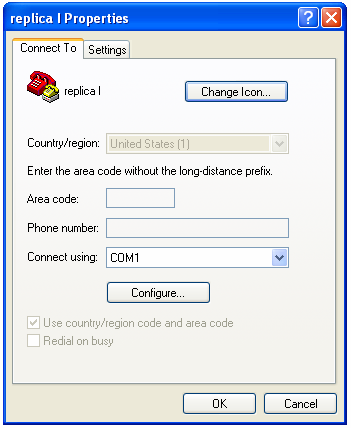
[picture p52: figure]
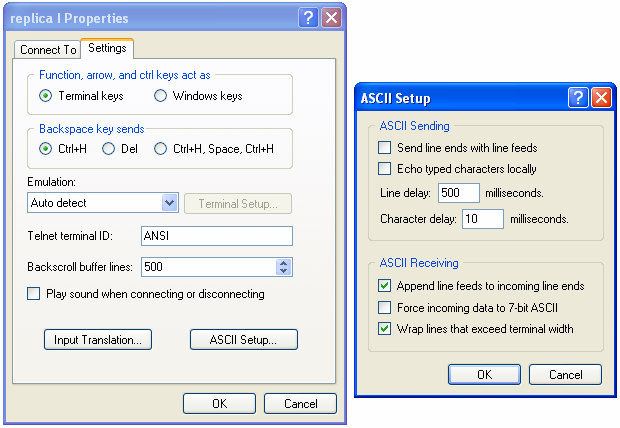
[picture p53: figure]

© Briel Computers 2007 | page 24

Select OK and continue on to starting Hyper Terminal. You are not ready yet, so click on the disconnect Icon as shown: Next, click on “File” in the menu bar and select “Properties” from the drop-down menu list. You should then get a screen that looks like this:

Figure 13: Configure window

Click the “Settings” tab at the top, and then select the “ASCII setup” button.

Figure 14: ASCII settings for COM port

Set up your settings exactly as shown in the Figure 13. Select “OK” to close the ASCII Setup screen. Select “OK” again to close the properties window and return to Hyper Terminal. Now click on the “Connect” button and you are connected. Power up your replica and press the reset button. Try typing on both the replica keyboard and your pc keyboard to verify that both function. Make sure that Caps Lock is ON with the PC. If you have any problems repeat these steps.

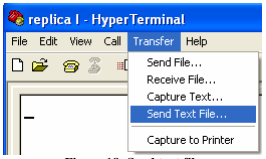
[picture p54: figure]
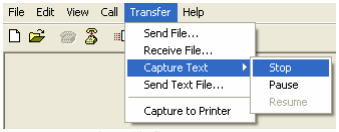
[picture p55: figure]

© Briel Computers 2007 | page 25

Transferring files with Hyper Terminal

To send a file to your replica, simply click on the “Transfer” tab and select “Send Text File” from the drop down list.

Figure 18: Send text file

Find the file on your PC and select “OK”. At this point Hyper Terminal will send the file your replica and your replica will treat the file as if you were typing it in. Once it is finished typing in, just run your program as normal. Remember, if you are sending a BASIC file to enter BASIC by typing “E000R” followed by “Enter” before sending the file.

To receive a file is just as easy. Once again, click on the “Transfer” tab, but this time select “Capture Text…” from the drop down list. This will bring up a file name to save option and select the name for your file. Select “OK” to begin the “Capture” mode. If you’re in BASIC you can type LIST and Hyper Terminal will capture your BASIC listing. If you’re in the Woz monitor, simply type the address range to capture, followed by “Enter.”

Figure 19: Stop text capture

Once you are done capturing your file, click on the “Transfer” tab, Capture Text option and “Stop.” That is it. You can now go in and edit your file with any text editor.

© Briel Computers 2007 | page 26

## Chapter 7: Using the Krusader Assembler

Krusader is a powerful assembler written by Ken Wessen for the replica 1. This assembler makes programming the 6502 processor in the replica 1 a breeze. No hand converting mnemonic instructions to hex then manually entering them in the Woz monitor. Now you can program using mnemonic instructions, assemble and run your program right from the assembler. To enter the assembler, type in:

F000R [return]

The program will begin and the authors name and current revision will appear. Next line will display a ‘?’ with the cursor next to it. Type ‘N’ to enter a new program. The assembler will now display ‘000’ for the first line. Let’s enter the program listed in the Krusader as an example program.

000 is now displayed. Press space bar to skip the first field used for naming code blocks. The assembler tabs over to the next field. Type LDA #’A’ [return];
001 is now displayed. Then type LOOP then press space bar to tab to the next field. Type JSR $FFEF [return]. Type in the rest as shown:

002 CLC
003 ADC #$1
004 CMP #’Z’+1
005 BNE LOOP
006 RTS

Once you have entered in the source code, type L to list out the code, and then A to assemble it. To run your code type R $300. The program will run and output the string:

ABCDEFGHIJKLMNOPQRSTUVWXYZ

Once the program finishes with the RTS command it will return to the Krusader assembler shell.

To learn more on how to program using Krusader, refer to the Krusader owner’s manual or visit the Krusader web site at:

http://school.anhb.uwa.edu.au/personalpages/kwessen/apple1/Krusader.htm

© Briel Computers 2007 | page 27

## Chapter 8: Troubleshooting your replica 1

If you have just built your replica 1 and are now having problems getting it running, here are some tips on what to check:

Dead: Check jumpers to ensure correct setting for the type of power source you are using. Check your power source to make sure it is functioning properly.

Replica 1 won’t reset: If you soldered from a kit, check for any points that didn’t get soldered. Check to make sure all chips are seated properly. Make sure you soldered the oscillator in the correct orientation.

No response from the keyboard: Make sure you press reset before you begin using the replica 1. Check the connector and be sure it is inserted properly.

Reset works but cursor stays on same line as backslash: This is an indication that communication between the 6821 and the 6502 is not working correctly, or RAM is not functioning properly. If built from kit, check the 6821, 74LS04 and 62256 for missed soldering of pins. Make sure the chips are seated properly.

These are a few of the most common problems reported by kit builders. The number one source was missed pins. If the pins don’t get soldered, the circuit may work, but act very strange. If you absolutely can’t find out what is wrong, contact Briel Computers to have your board checked.

The replica 1 forums at: http://www.brielcomputers.com/phpBB2/ is a good source for information when troubleshooting.

We want every kit that gets sold to operate properly so we will fix your kit for shipping charges plus cost on any parts. Please contact Briel Computers at vbriel@yahoo.com before shipping in your board for repair.

## Appendix A: ASCII Keyboard pin out

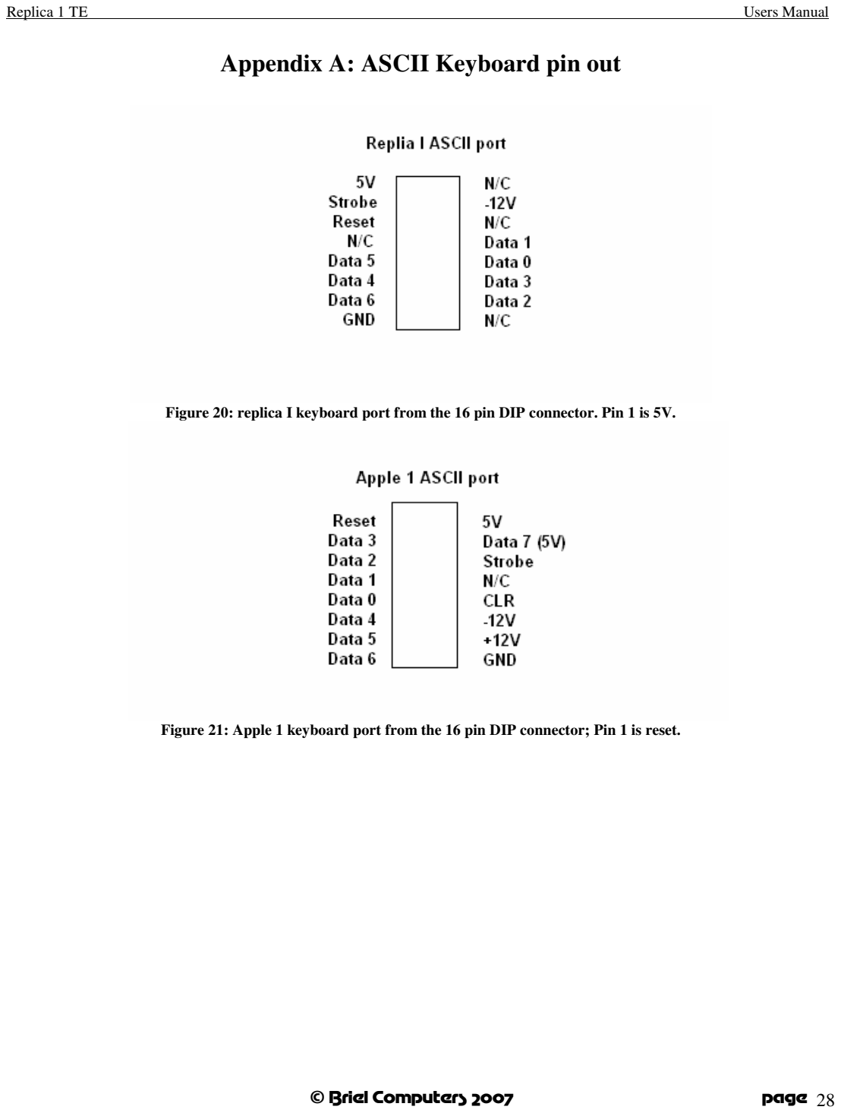
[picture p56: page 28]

© Briel Computers 2007 | page 28

Figure 20: replica I keyboard port from the 16 pin DIP connector. Pin 1 is 5V.

Figure 21: Apple 1 keyboard port from the 16 pin DIP connector; Pin 1 is reset.

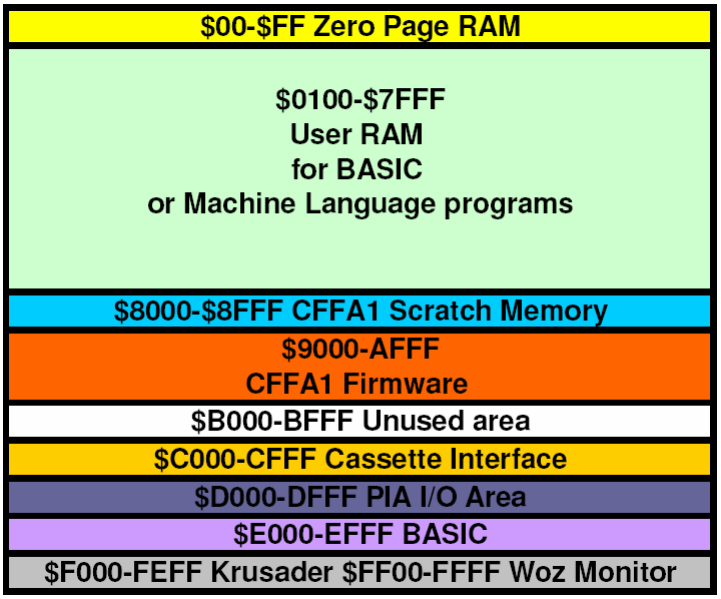
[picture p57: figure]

© Briel Computers 2007 | page 29

## Appendix B: Replica 1 Memory Map

© Briel Computers 2007 | page 30

## Appendix C: Woz Monitor listing

FF00: D8 | RESET | CLD | Clear decimal arithmetic mode.
FF01: 58 | | CLI
FF02: A0 7F | | LDY #$7F | Mask for DSP data direction register.
FF04: 8C 12 D0 | | STY DSP | Set it up.
FF07: A9 A7 | | LDA #$A7 | KBD and DSP control register mask.
FF09: 8D 11 D0 | | STA KBD CR | Enable interrupts, set CA1, CB1, for
FF0C: 8D 13 D0 | | STA DSP CR | positive edge sense/output mode.
FF0F: C9 DF | NOTCR | CMP #$DF | “_”?
FF11: F0 13 | BEQ BACKSPACE Yes.
FF13: C9 9B | | CMP #$9B | ESC?
FF15: F0 03 | | BEQ ESCAPE | Yes.
FF17: C8 | | INY | Advance text index.
FF18: 10 0F | BPL NEXTCHAR Auto ESC if > 127.
FF1A: A9 DC | ESCAPE | LDA #$DC | “\”.
FF1C: 20 EF FF | | JSR ECHO | Output it.
FF1F: A9 8D | GETLINE | LDA #$8D | CR.
FF21: 20 EF FF | | JSR ECHO | Output it.
FF24: A0 01 | | LDY #$01 | Initialize text index.
FF26: 88 | BACKSPACE | DEY | Back up text index.
FF27: 30 F6 | | BMI GETLINE | Beyond start of line, reinitialize.
FF29: AD 11 D0 | NEXTCHAR | LDA KBD CR | Key ready?
FF2C: 10 FB | BPL NEXTCHAR Loop until ready.
FF2E: AD 10 D0 | | LDA KBD | Load character. B7 should be ‘1’.
FF31: 99 00 02 | | STA IN,Y | Add to text buffer.
FF34: 20 EF FF | | JSR ECHO | Display character.
FF37: C9 8D | | CMP #$8D | CR?
FF39: D0 D4 | | BNE NOTCR | No.
FF3B: A0 FF | | LDY #$FF | Reset text index.
FF3D: A9 00 | | LDA #$00 | For XAM mode.
FF3F: AA | | TAX | 0->X.
FF40: 0A | SETSTOR | ASL | Leaves $7B if setting STOR mode.
FF41: 85 2B | SETMODE | STA MODE | $00=XAM $7B=STOR $AE=BLOK XAM
FF43: C8 | BLSKIP | INY | Advance text index.
FF44: B9 00 02 | NEXT ITEM | LDA IN,Y | Get character.
FF47: C9 8D | | CMP #$8D | CR?
FF49: F0 D4 | | BEQ GETLINE | Yes, done this line.
FF4B: C9 AE | | CMP #$AE | “.”?
FF4D: 90 F4 | | BCC BLSKIP | Skip delimiter.
FF4F: F0 F0 | | BEQ GETLINE | Yes. Set STOR mode.
FF51: C9 BA | | CMP #$BA | “:”?
FF53: F0 EB | | BEQ SETSTOR | Yes. Set STOR mode.
FF55: C9 D2 | | CMP #$D2 | “R”?
FF57: F0 3B | | BEQ RUN | Yes. Run user program.
FF59: 86 28 | | STX L | $00-> L.
FF5B: 86 29 | | STX H | and H.
FF5D: 84 2A | | STY YSAV | Save Y for comparison.

© Briel Computers 2007 | page 31
FF5F: B9 00 02 | NEXTHEX | LDA IN,Y | Get character for hex test.
FF62: 49 B0 | | EOR #$B0 | Map digits to $0-9.
FF64: C9 0A | | CMP #$0A | Digit?
FF66: 90 06 | | BCC DIG | Yes.
FF68: 69 88 | | ADC #$88 | Map letter “A”-“F” to $FA-FF.
FF6A: C9 FA | | CMP #$FA | Hex letter?
FF6C: 90 11 | | BCC NOTHEX | No, character not hex.
FF6E: 0A | DIG | ASL
FF6F: 0A | | ASL | Hex digit to MSD of A.
FF70: 0A | | ASL
FF71: 0A | | ASL
FF72: A2 04 | | LDX #$04 | Shift count.
FF74: 0A | HEXSHIFT | ASL | Hex digit left, MSB to carry.
FF75: 26 28 | | ROL L | Rotate into LSD.
FF77: 26 29 | | ROL H | Rotate into MSD’s.
FF79: CA | | DEX | Done 4 shifts?
FF7A: D0 F8 | | BNE HEXSHIFT | No, loop.
FF7C: C8 | | INY | Advance text index.
FF7D: D0 E0 | | BNE NEXTHEX | Always taken. Check next char for hex.
FF7F: C4 2A | NOTHEX | CPY YSAV | Check if L, H empty (no hex digits).
FF81: F0 97 | | BEQ ESCAPE | Yes, generate ESC sequence.
FF83: 24 2B | | BIT MODE | Test MODE byte.
FF85: 50 10 | | BVC NOTSTOR | B6=0 STOR 1 for XAM & BLOCK XAM
FF87: A5 28 | | LDA L | LSD’s of hex data.
FF89: 81 26 | | STA (STL,X) | Store at current ‘store index’.
FF8B: E6 26 | | INC STL | Increment store index.
FF8D: D0 B5 | | BNE NEXTITEM | Get next item. (no carry).
FF8F: E6 27 | | INC STH | Add carry to ‘store index’ high order.
FF91: 4C 44 FF | TONEXTITEM | JMP NEXTITEM | Get next command item.
FF94: 6C 24 00 | RUN | JMP (XAML) | Run at current XAM index.
FF97: 30 2B | NOTSTOR | BMI XAMNEXT | B7=0 for XAM, 1 for BLOCK XAM.
FF99: A2 02 | | LDX #$02 | Byte count.
FF9B: B5 27 | SETADR | LDA L-1,X | Copy hex data to
FF9D: 95 25 | | STA STL-1,X | ‘store index’.
FF9F: 95 23 | | STA XAML-1,X | And to ‘XAM index’.
FFA1: CA | | DEX | Next of 2 bytes.
FFA2: D0 F7 | | BNE SETADR | Loop unless X=0.
FFA4: D0 14 | NXTPRNT | BNE PRDATA | NE means no address to print.
FFA6: A9 8D | | LDA #$8D | CR.
FFA8: 20 EF FF | | JSR ECHO | Output it.
FFAB: A5 25 | | LDA XAMH | ‘Examine index’ high-order byte.
FFAD:20 DC FF | | JSR PRBYTE | Output it in hex format.
FFB0: A5 24 | | LDA XAML | Low-order ‘examine index’ byte.
FFB2: 20 DC FF | | JSR PRBYTE | Output it in hex format.
FFB5: A9 BA | | LDA #$BA | “:”.
FFB7: 20 EF FF | | JSR ECHO | Output it.
FFBA: A9 A0 | PRDATA | LDA #$A0 | Blank.
FFBC: 20 EF FF | | JSR ECHO | Output it.
FFBF: A1 24 | | LDA (XAML,X) | Get data byte at ‘examine index’.

© Briel Computers 2007 | page 32
FFC1: 20 DC FF | JSR PRBYTE | Output it in hex format.
FFC4: 86 2B | XAMNEXT | STX MODE | 0->MODE (XAM mode).
FFC7: A5 24 | LDA XAML
FFC8: C5 28 | CMP L | Compare ‘examine index’ to hex data.
FFCA:A5 25 | LDA XAMH
FFCC:E5 29 | SBC H
FFCE: B0 C1 | BCS TONEXTITEM Not less, so no more data to output.
FFD0: E6 24 | INC XAML
FFD2: D0 02 | BNE MOD8CHK | Increment ‘examine index’.
FFD4: E6 25 | INC XAMH
FFD6: A5 24 | MOD8CHK | LDA XAML | Check low-order ‘examine index’ byte
FFD8: 29 07 | AND #$07 | For MOD 8=0
FFDA:10 C8 | BPL NXTPRNT | Always taken.
FFDC:48 | PRBYTE | PHA | Save A for LSD.
FFDD:4A | LSR
FFDE: 4A | LSR
FFDF: 4A | LSR | MSD to LSD position.
FFE0: 4A | LSR
FFE1: 20 E5 FF | JSR PRHEX | Output hex digit.
FFE4: 68 | PLA | Restore A.
FFE5: 29 0F | PRHEX | AND #$0F | Mask LSD for hex print.
FFE7: 09 B0 | ORA #$B0 | Add “0”.
FFE9: C9 BA | CMP #$BA | Digit?
FFEB: 90 02 | BCC ECHO | Yes, output it.
FFED: 69 06 | ADC #$06 | Add offset for letter.
FFEF: 2C 12 D0 | ECHO | BIT DSP | DA bit (B7) cleared yet?
FFF2: 30 FB | BMI ECHO | No, wait for display.
FFF4: 8D 12 D0 | STA DSP | Output character. Sets DA.
FFF7: 60 | RTS | Return.
FFF8: 00 00 (unused)
FFFA: 00 0F (NMI)
FFFC: 00 FF (RESET)
FFFE: 00 00 (IRQ)

HARDWARE NOTES

Page 0 Variables | Other Variables
XAML | 24 | IN | 200-27F
XAMH | 25 | KBD | D010
STL | 26 | KBD CR | D011
STH | 27 | DSP | D012
L | 28 | DSP CR | D013
H 29
YSAV | 2A
MODE | 2B

© Briel Computers 2007 | page 33

# Warranty

(Applies to factory assembled circuit boards only)

Briel Computers hereby warrants each of its products, and all components therein contained, to be free from defects in materials and/or workmanship for a period of thirty (3O) days from date of purchase. In the event of the occurrence of malfunction or other indication of failure attributable directly to faulty workmanship and/or material, then, upon return of the product to Briel Computers, at 5392 Cornell Blvd, North Ridgeville, Ohio 44039 (postage prepaid), Briel Computers will, at its option, repair or replace said products or components thereof, to whatever extent Briel Computers shall deem necessary, to restore said product to proper operating condition. All such repairs or replacements shall be rendered by Briel Computers, without charge to the customer. The responsibility for the failure of any Briel Computers product, or component thereof, which, at the discretion of Briel Computers, shall have resulted either directly or indirectly from accident, abuse, or misapplication of the product, shall be assumed by the customer, and the Briel Computers shall assume no liability as a consequence of such events under the terms of this warranty. While every effort, on the part of Briel Computers, is made to provide clear and accurate technical instruction on the use, implementation, and application of its products, Briel Computers shall assume no liability in events which may arise from the application of such technical instruction, nor shall Briel Computers be held liable for the quality, interconnection, or application of peripheral products, which may have been recommended by Briel Computers, but which have not been supplied as part of the product. This warranty contains and embodies the limits of responsibility of Briel Computers, with regard to its products, and no other liability is expressed, implied, or should be assumed by the purchaser, and in no event shall Briel Computers be held liable for the loss of time, effort, or transportation costs, nor for loss of potential profits or other consequential losses which might arise from the purchase, assembly, use, application, or subsequent sale of the products of Briel Computers, nor from any instructions and/or technical information thereto related.

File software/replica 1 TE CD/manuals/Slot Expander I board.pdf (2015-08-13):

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

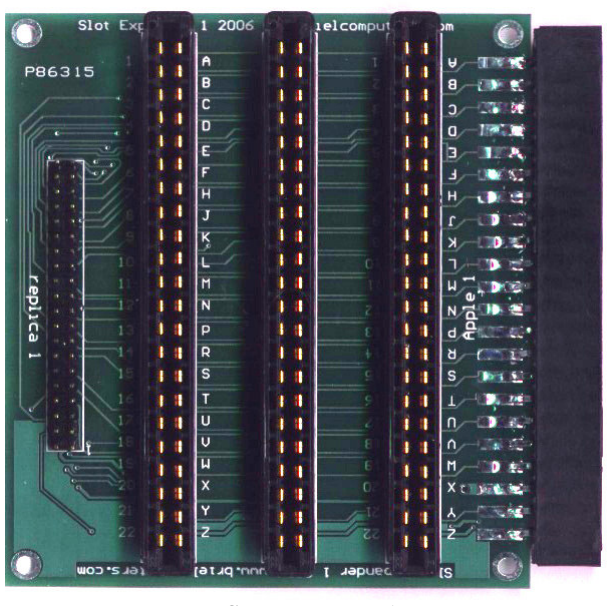
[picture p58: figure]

## Assembly:

Tools needed:

Soldering Iron
Solder
Ohm meter to check connections (optional)

The assembly is straight forward and simple except for the slot connector on the edge of the board. To solder this you will need to exercise patience since the connector wasn’t really designed for this type of connection. Align the slot along the edge so that it lines up with the edge pins on the edge of the board. You might want to bend some of the pins on the edge connector so that contact is better but the edge of the board sits about in the middle of the slot connector. Start by soldering one pin on each edge making sure that they stay down on the contact points on the board. Flip the board over and solder the 2 other ends on the bottom of the board. Check to make sure the board is still sitting in the middle of the slot connector and finish soldering the rest of the edge pins. You may want a small flat screwdriver to help hold the pins down onto the board.

Once you have the edge connector soldered you can install the replica 1 40 pin connector. Hold the 40 pin connector fitting into place and flip the board so the top of the board is facing your workbench and with the replica 1 header connector resting on the workbench you can now solder it in place.

The last step is to solder the 3 slot expansion connectors into place. If you look carefully at the slot connector you might be able to make out a small dot in one corner; that is pin1. The connector does not have to be installed this way but it is the correct way. Hold all three connectors with the board, then flip the board over and set down on workbench so all three are resting on the bench while the board is sitting on top of the 3 connectors. You can now solder you slot connectors in place. Check you work with an ohm meter to verify all the connections on the end connector are making good contact.

## Installation:

Apple 1:

Installing on the Apple 1 or look-alike clone computers is straight forward. Simply plug the slot expander 1 board into the edge connector on the Apple 1 computer and you are ready to go. You can double check that the connections match with an ohm meter and the 1 slot on the Apple 1 with any of the 3 slots on the expansion board.

Replica 1:

To install the slot expander 1 board on the replica 1, you need to attach a 40 pin connector cable to both the expander board and the replica 1. Pin 1 on the expander board is marked with a 1. Find the red edge of the cable and either end to find pin 1 on the connector. Carefully plug the cable into the expansion board. On the replica 1, pin 1 is not as easy to identify but it is located closest to the silver looking 4 pin clock OSC.

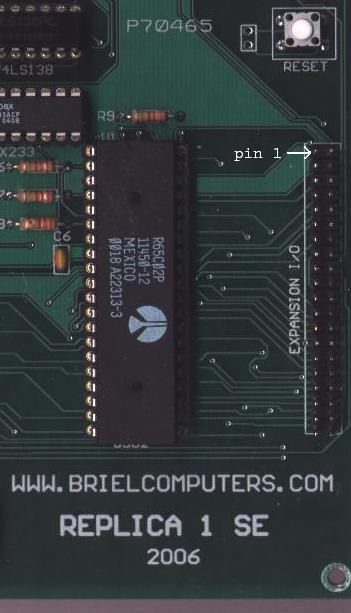
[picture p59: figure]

replica 1 showing pin 1 location

This pin is 180 degrees off from the expansion board so you will need to be careful when plugging in the cable to make sure you have it correct.

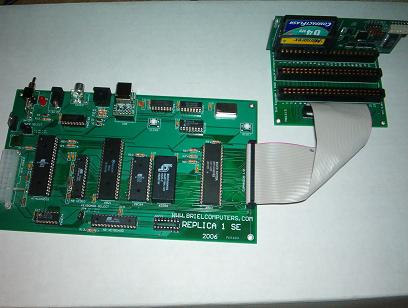
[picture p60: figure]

replica 1 shown with correct cable orientation

To make certain that you have the cable installed correctly, you can test pins 20 and X with ground (mounting hole on replica 1) to make sure they are the same.

Please feel free to ask any questions regarding installation of assembly of this product to vbriel@yahoo.com

Visit Briel Computers website at http://www.brielcomputers.com for information on expansion boards for the replica 1 and apple 1 computers.

Get answers about your replica 1 at the replica 1 users forum:

http://www.brielcomputers.com/phpBB2/
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

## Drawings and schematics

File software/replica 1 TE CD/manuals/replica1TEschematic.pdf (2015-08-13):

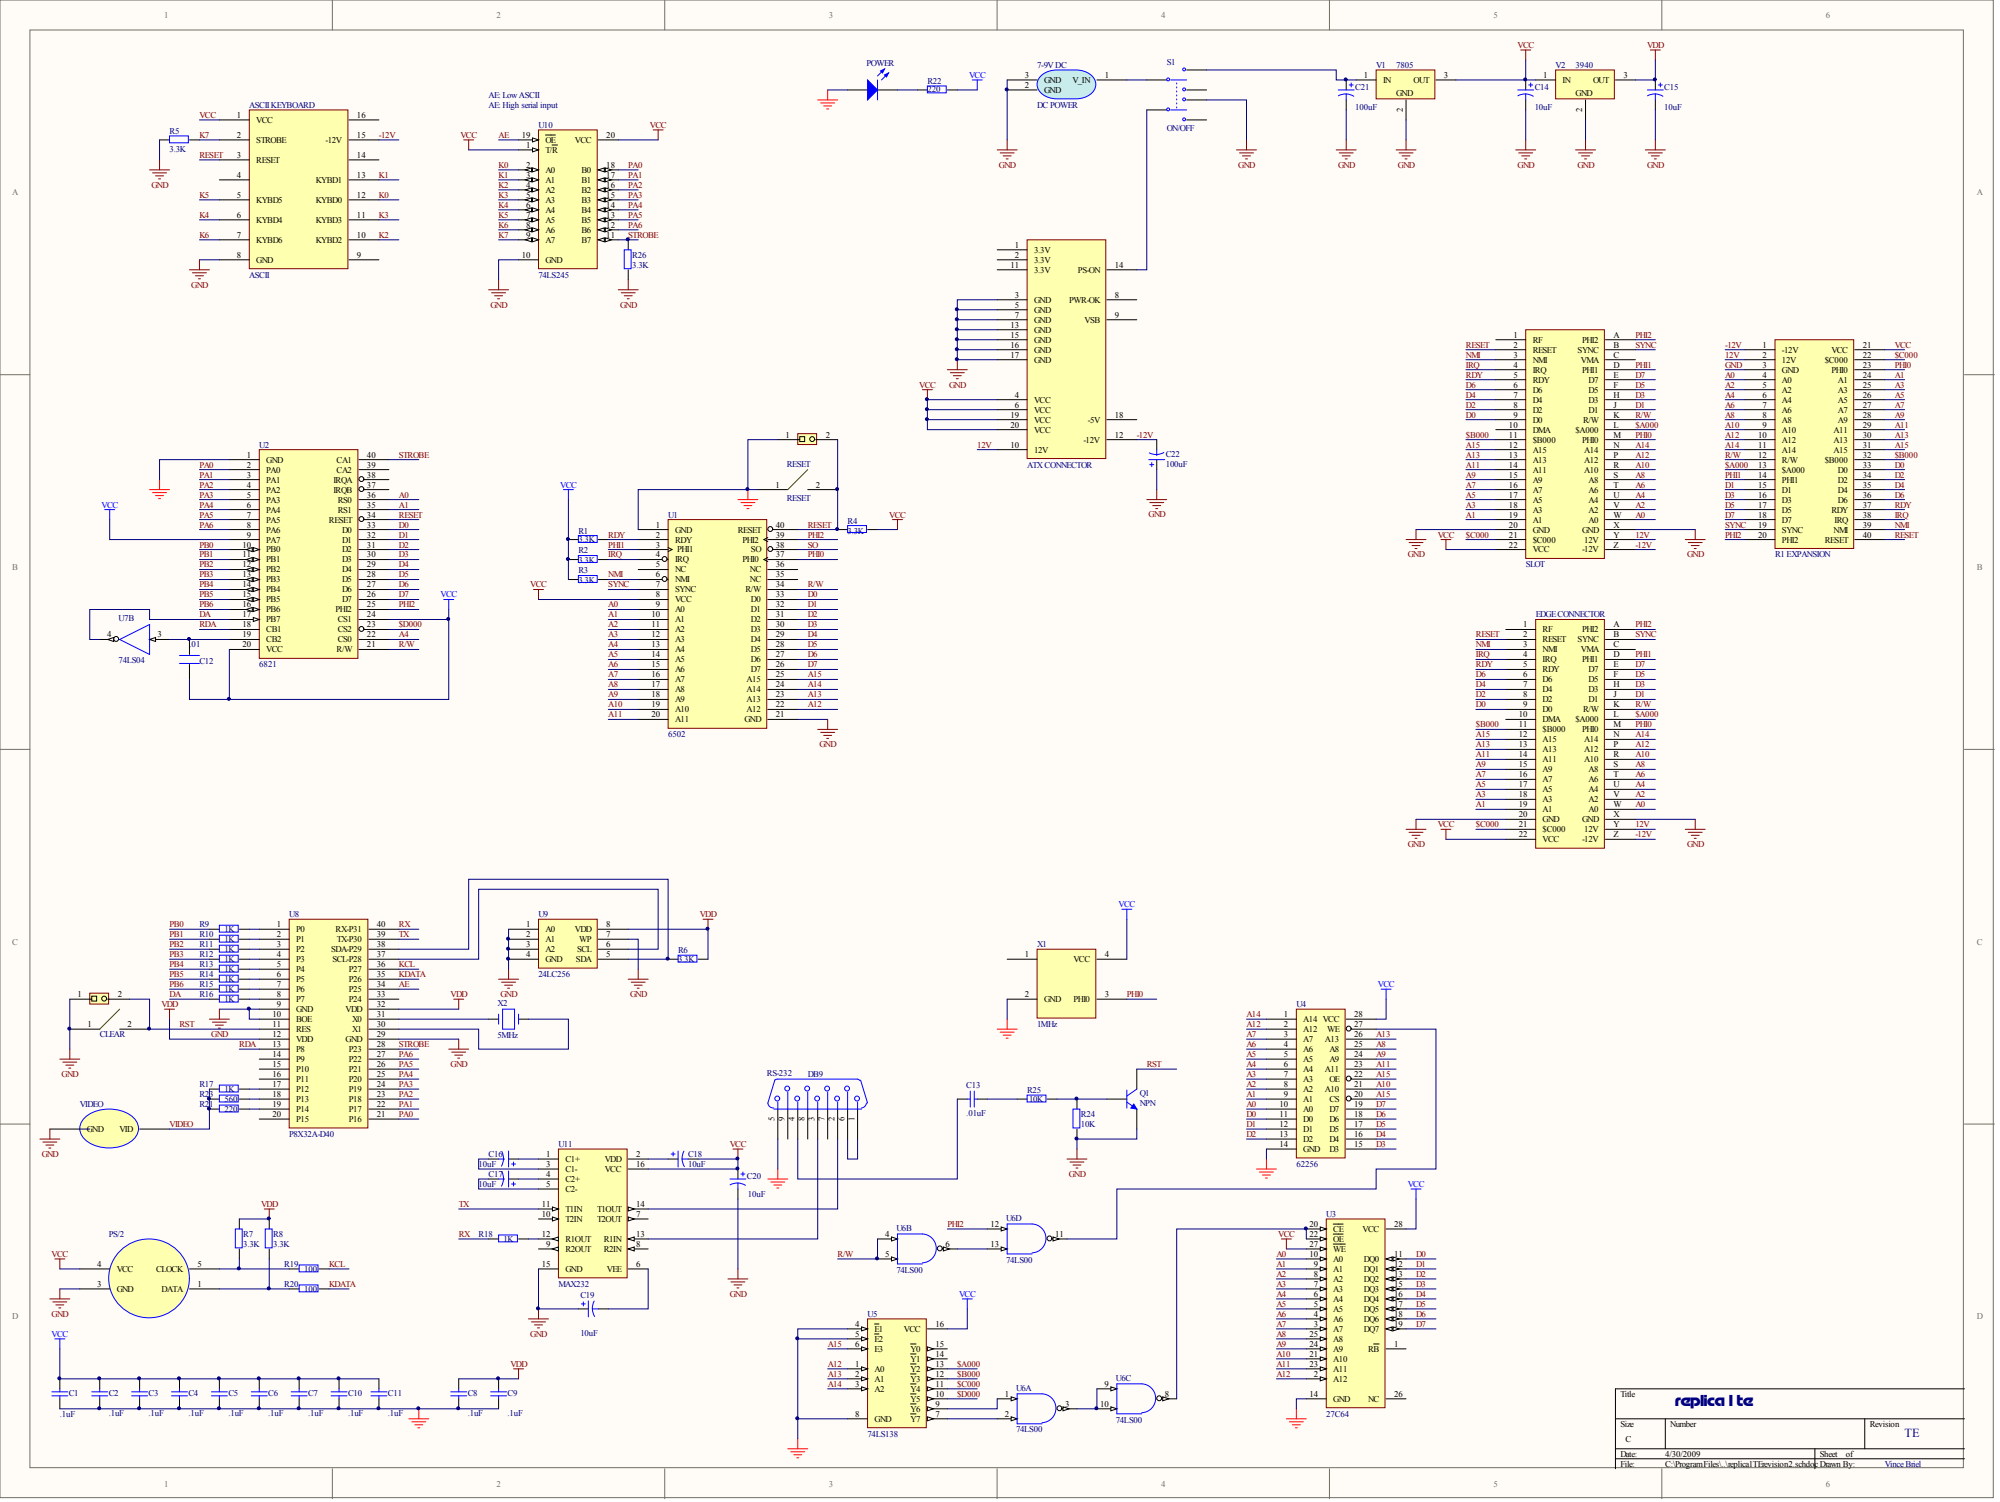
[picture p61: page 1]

AE: Low ASCII
AE: High serial input

GND 5

GND 13

VDD | GND 9

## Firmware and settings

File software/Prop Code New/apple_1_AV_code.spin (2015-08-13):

''    replica 1 TEN I/O controller by Briel Computers
''
''    TE-110 update includes 1MHz signal on pin P15 (pin 20 physical)
''    Added 2 pin inverter code to eliminate 74LS04 from previous design
''    Added jumper for PS/2 disable if high
''    Added code to CLS if pin P24 goes high
''    Added code so if HOME is pressed, backspace does _ out but screen does backspace!
''    Keyboard setup so ASCII will be jumpered if enabled
''    changed BAUD rate to 9600
''    As of July 3, 2008 only NTSC is available

''    
''    Idendify port pins below
''    P0-P6 are Video Data Bus pins
''    P7 is Data Available from 6821 letting you know there is data
''    P8 is Ready Data Available letting 6821 know you can receive
''    P12-P14 Video port
''    P16-23 is keyboard data out to 6821 P23 is Strobe bit
''    P25 is ASCII keyboard buffer pin
''
''****************************************************************    
CON
  _clkmode = xtal1 + pll16x
  _xinfreq = 5_000_000
'
  RX_Pin     = 31
  TX_Pin     = 30                                          
  Out        = %1
  Low        = 0
  High       = 1
  CR         = 13
  LF         = 10
  BaudRate   = 9_600
  VideoPins  = 13
  VideoCls   = 0
  NUM        = %100
  CAPS       = %010
  SCROLL     = %001
  RepeatRate = 40
'Set emulation type for pin configuration
   Demo      = true                    ' Demo Board
   Proto     = false                   ' Proto Board
   Hydra     = false                   ' Hydra

'  dspPins   = (Hydra & 24) | ((Demo | Proto) & 12)   ' TV
   dspPins   = 16                                     ' VGA
   keyPins   = (Hydra & 13) | ((Demo | Proto) & 26)
   spiDO     = (Hydra & 16) | (Demo & 0) | (Proto & 8)
   spiClk    = (Hydra & 17) | (Demo & 1) | (Proto & 9)
   spiDI     = (Hydra & 18) | (Demo & 2) | (Proto & 10)
   spiCS     = (Hydra & 19) | (Demo & 3) | (Proto & 11)

   CLK0      = 15 'Pin P15 (physical 20) is the Phase 0 clock to drive the 6502
   revision  = 2
   zero      = 0

   clockOut     = 25
   latchOut     = 24
   columnOut    = 26
   rowIn        = 27

   
DAT

tvCursorOn    byte true
  tvForeColor   byte 7                                                          'Composite color value index
  tvBackcolor   byte 2
cursor        byte 3
'cursors       byte %000, %001, %101, %010, %110, %011, %111
'terminalModes byte text#SET_DECAWM
VAR
  Byte Index
  Byte Rx                        
  Word key
  Byte keystep
  Byte rxbyte
  Long stack0[300], stack1[300]
  Byte temp
  Byte ascii
  Byte keyinuse
  Byte serdata
  Byte strobe
  Byte BS

  word cursorBlink

  word rowState
  word columnSelect
  word check

  byte debounce[56]
  
OBJ
'  VideoDisplay: "char_mode_09"   
  Serport: "Serial_IO"
  VideoDisplay:   "aigeneric_driver"

PUB   main | te,p                                       'Main startup and video handler                

  BS := 0                                        ' Standard Backspace mode emulating apple 1 = 0 or working BS = 1
    
  VideoDisplay.Start(videopins)
  VideoDisplay.Out(VideoCls)                     'Clear screen
  'VideoDisplay.Color($0F00)
   
  Serport.startx(RX_Pin, TX_Pin, BaudRate)       'Start Serial Port, set baud, pins, etc

  DIRA[23..16]~
  DIRA[25]~~
  
  DIRA[8]~~                                      'Set P8 as output pin to RDA signal 

  'cognew (serial, @stack0)                              'Cog sits around looking for serial input data
  cognew (keyboard, @stack1)
 
  repeat

    outa[8]~~

    pauseMS(12)

    cursorBlink += 1

    if cursorBlink == 50
      VideoDisplay.Outcursor(64)
      
    if cursorBlink > 100
      VideoDisplay.Outcursor(32)
      cursorBlink := 0
    
    temp := ina[7]                             'Read DA signal from 6821

    if ina[7]                                           'Data on line?

      temp := ina[6..0]                                 'Get it

      if temp > 126
        temp := 0

      !outa[8]                                          'Turn off RDA signal                                           

      if temp == 95 and BS

        VideoDisplay.Outcursor(32)
        VideoDisplay.out(temp)          

      if temp == 13                          'Is data a Carriage Return (CR)?
         VideoDisplay.Outcursor(32)          'yes, remove cursor with a blank so it won't shadow
         Serport.out(10)
         
      if temp > 31 or temp == 13             'is character Apple 1 style?
         VideoDisplay.Out(temp)              'Yes, send it to TV output
         VideoDisplay.Outcursor(64)          'Set the new cursor
         
      '
       Serport.out(temp)                      'Send it out serial port


PUB serial | tempSer                                       'Serial INPUT COG

  repeat          

    tempSer := Serport.in

    if tempSer
  
      keyOut(tempSer)                                'If we get a key via serial, send it out
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

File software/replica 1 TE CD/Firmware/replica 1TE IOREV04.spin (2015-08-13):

''    replica 1 TE I/O controller by Briel Computers
''
''    version 3.01  FIRST INITIAL TEST
''    version 3.02  FIX FOR WHEN ASCII NOT ATTACHED, NO GHOST DATA
''    version 3.03  COLOR FIX FOR TRUE B&W
''    version 3.04  FIX CTRL CODES TO WORK
''    
''    As of July 3, 2008 only NTSC is available

''    
''    Idendify port pins below
''    P0-P6 are Video Data Bus pins
''    P7 is Data Available from 6821 letting you know there is data
''    P8 is Ready Data Available letting 6821 know you can receive
''    P12-P14 Video port
''    P16-23 is keyboard data out to 6821 P23 is Strobe bit
''    P25 is ASCII keyboard buffer pin
''
''****************************************************************    
CON
  _clkmode = xtal1 + pll16x
  _xinfreq = 5_000_000
'
  RX_Pin     = 31
  TX_Pin     = 30                                          
  Out        = %1
  Low        = 0
  High       = 1
  CR         = 13
  LF         = 10
  BaudRate   = 2_400
  VideoPins  = 12
  VideoCls   = 0
  NUM        = %100
  CAPS       = %010
  SCROLL     = %001
  RepeatRate = 40
'Set emulation type for pin configuration
   Demo      = true                    ' Demo Board
   Proto     = false                   ' Proto Board
   Hydra     = false                   ' Hydra

'  dspPins   = (Hydra & 24) | ((Demo | Proto) & 12)   ' TV
   dspPins   = 16                                     ' VGA
   keyPins   = (Hydra & 13) | ((Demo | Proto) & 26)
   spiDO     = (Hydra & 16) | (Demo & 0) | (Proto & 8)
   spiClk    = (Hydra & 17) | (Demo & 1) | (Proto & 9)
   spiDI     = (Hydra & 18) | (Demo & 2) | (Proto & 10)
   spiCS     = (Hydra & 19) | (Demo & 3) | (Proto & 11)


OBJ
VAR
  Byte Index
  Byte Rx                        
  Word key
  Byte keystep
  Byte rxbyte
  Long Stack[300],stack1[300],stack2[300]
  Byte temp
  Byte ascii
  Byte keyinuse
  Byte serdata
  Byte strobe
OBJ
  VideoDisplay: "char_mode_08"   
  Serport: "Serial_IO"
  'kb: "keyboard"
 
PUB   main                                       'Main startup and video handler                
  
  VideoDisplay.Start                             'Start Video Driver
  VideoDisplay.Out(VideoCls)                     'Clear screen
  Serport.startx(RX_Pin, TX_Pin, BaudRate)       'Start Serial Port, set baud, pins, etc
  'kb.startx(26, 27, NUM+CAPS, RepeatRate)        'Start Keyboard Driver, set Caps lock
  DIRA[23..16]~                                  'Set ASCII keyboard port as input 
  DIRA[25]~~                                     'Set ASCII buffer pin as output
  DIRA[8]~~                                      'Set P8 as output pin to RDA signal 
  'cognew (ps2 , @stack1)
  cognew (blink , @Stack)
  cognew (serial, @stack2)
      
  Repeat
      OUTA[8]~~                                  'Turn on P8 to recieve video data (to RDA)
      temp := INA[7]                             'Read DA signal from 6821
      if temp >> 0                               'Is there data out there?
          temp :=INA[6..0]                       'Yes, get video data
          !OUTA[8]                               'Turn off RDA signal
          PauseMS(12)                            'Pause 12ms        
          if temp == 13                          'Is data a Carriage Return (CR)?
             VideoDisplay.Outcursor(32)          'yes, remove cursor with a blank so it won't shadow
          if temp > 31 or temp == 13             'is character Apple 1 style?
             VideoDisplay.Out(temp)              'Yes, send it to TV output
             VideoDisplay.Outcursor(64)          'Set the new cursor
          Serport.out(temp)                   'Send it out serial port          
{-
PUB ps2                                          'PS/2 Keyboard COG
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
